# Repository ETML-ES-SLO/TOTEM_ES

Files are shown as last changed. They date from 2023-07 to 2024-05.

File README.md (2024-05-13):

# TOTEM FIXME 

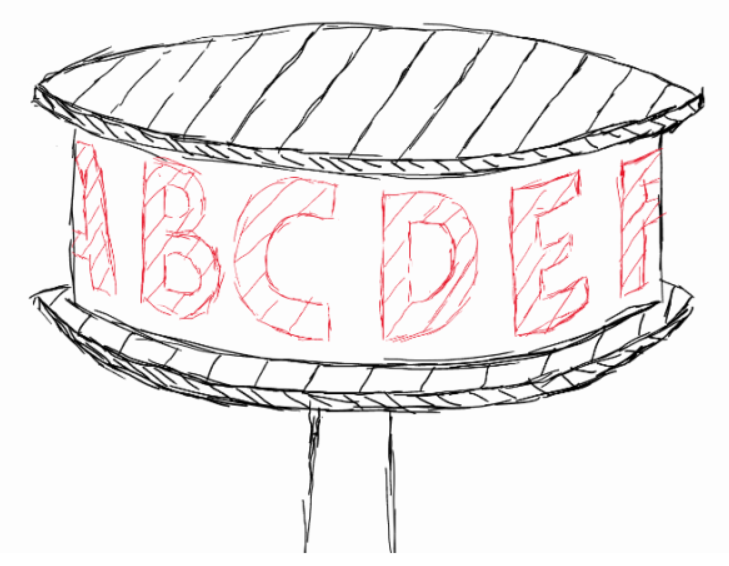
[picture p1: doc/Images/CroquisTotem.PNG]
croquis du totem


## General Description 

[FR] : le but de ce projet est de réaliser un totem lumineux pouvant afficher des messages défilants ou des animations. 
Ce totem sera utilisé lors de festivales ou de manifestions lié aux activités du hackersapce Fixme, que ce soit à l'intérieur ou à l'éxtérieur.
Un premier prototype a été réaliser par un ex-étudiant de l'ES (Nicolas Furst), ce protoype est composé de :  

[EN] : the goal of this project is to make a light totem which can display different scrolling messages or animations. 
This totem will be used at festivals or demonstration meeting related FIXME hackerspace activities, indorrs or outdorrs. 
A first prototype was realized by an former student of the ES technical school (Nicolas Furst), this prototype is composed of : 

## Sotfwares used for this projet 
### for the version 1_X (ETML-ES)

* for mechanical part : **soldiworks** 
* for shematics and PCB design : **Altium** 
* for PIC micronctroller programming  : => *IDE* : MPLABX  ??- *configurator* : Harmony ?? - *compilator* : XC?? 

### for the version 2_x (FIXME)

in progress !!!

## **Mechanical part** : 

* two disk of 240mm diameter - view of top and bottom below

| view **TOP** | view **BOTTOM** | 
| --- | --- |
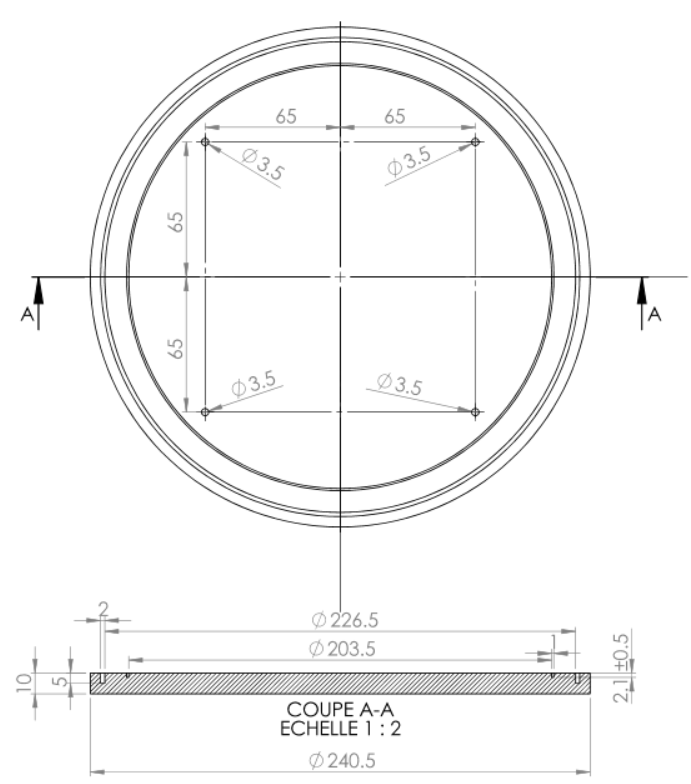
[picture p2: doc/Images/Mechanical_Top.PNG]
TOP
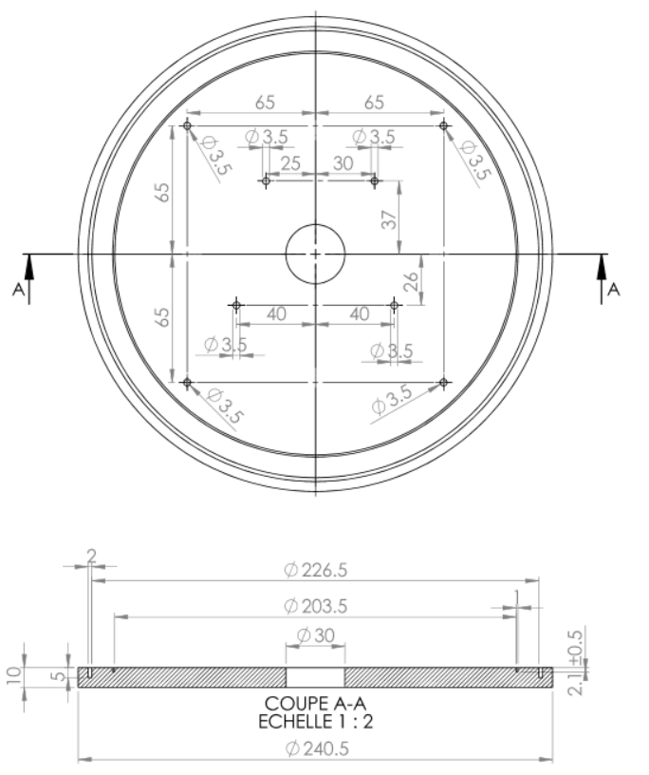
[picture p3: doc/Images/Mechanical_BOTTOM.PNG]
BOTTOM
|  |  | 

**note** : the mechanical schematic was realized on the Solid Works CAO software - for using the mechanical files, go into the **mec** folder 

## **Electronics part** 

Below is a block diagrams of the various stages of the electronic part : 
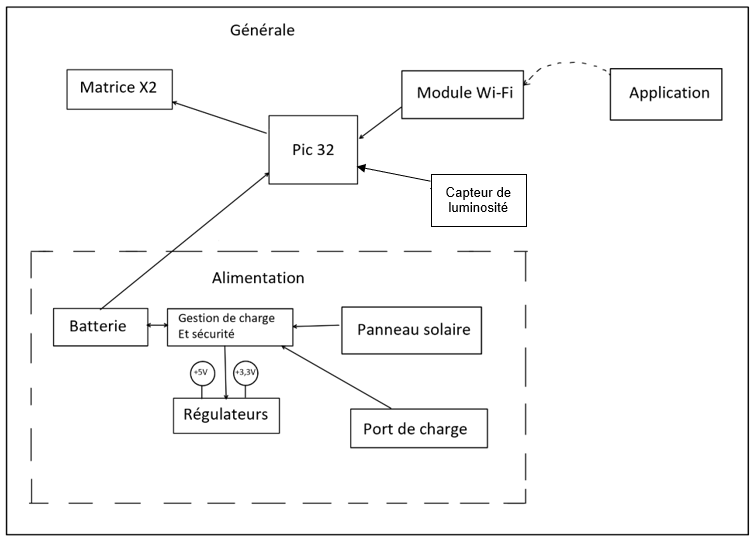
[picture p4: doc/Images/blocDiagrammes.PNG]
block diagrams


### **POWER SUPPLY**
in progress 

#### **Battery & Solar Panel**

#### **Charging System**
#### **Regulator**

### **DISPLAY**
2 flexible LEDS panels (8 x 32 => 256 type leds [WS2812B](https://cdn-shop.adafruit.com/datasheets/WS2812B.pdf) or [SK6812](https://cdn-shop.adafruit.com/product-files/1138/SK6812+LED+datasheet+.pdf))  

### **MICROCONTROLER** 

[FR]: pour choisir correctement un micrcontroleur, il faut déterminer les différentes fonctions que l'on a besoin, voir le tableau ci-dessous. 
On a besoin de : 
* 3 entrées analogiques, 
* une communication SPI comprenant la clock, le chip select, le MISO et le MOSI, 
* 5 I/O, 
* un reset
* deux pins de programmation 
* alimentation pour la partie digitales et analogiques 

ce qui fait au minium ~ **20pins** => voir le tableau ci-dessous 

En se référant au [datasheet PIC32MX795H](https://ww1.microchip.com/downloads/aemDocuments/documents/MCU32/ProductDocuments/DataSheets/PIC32MX5XX6XX7XX_Family%29Datasheet_DS60001156K.pdf),
vu le nombre de pattes estimées, il serait bien de choisir un boitier de type **TQFP** de 64pins. 
On reste sur du prototype, donc il serait bien d'utiliser le chip ayant le plus de mémoire (ROM -> 512ko | RAM -> 128ko)      

[EN]: to choose the microcontroller, to need to determine the functions required - see the table below
It needs : 
* 3x analog input 
* 1x SPI communication with : clock, chip select, MISO, MOSI 
* 5x digital I/O 
* Reset 
* 2x programming Pins
* pins for the digital and analog part 

we need minimum ~ **20pins** => see table below  

In reference with [datasheet PIC32MX795H](https://ww1.microchip.com/downloads/aemDocuments/documents/MCU32/ProductDocuments/DataSheets/PIC32MX5XX6XX7XX_Family%29Datasheet_DS60001156K.pdf), 
and with the above estimate, it would be a good idea to use **TQFP** box, with 64pins. What's more, this is a prototype, so it would be a good idea to also take the uC with the largest memory (ROM -> 512ko | RAM -> 128ko)  

| -Application- | -Function- | -Pin's Number- | 
| --- | --- | --- |
| battery current measurement | Analogic Input (ADC) | 1x | 
| battery voltage measurement | Analogic Input (ADC) | 1x | 
| luminosity measurement | Analogic Input (ADC) | 1x |
| Wifi Communication | SPI | 4x | 
| Wifi Communication | Digital I/O | 4x |
| 5V activation | Digital I/O | 1x |
| uC programming | PGE-D/C | 2x |
| uC Reset | _MCLR | 1x | 
| Power Supply digital I/O | VDD | minimum 1x | 
| Power Supply analog Input | AVDD | minimum 1x | 
| Ground Supply | VSS - AVSS | minimum 2x | 

Below, features extracted from the datasheet 
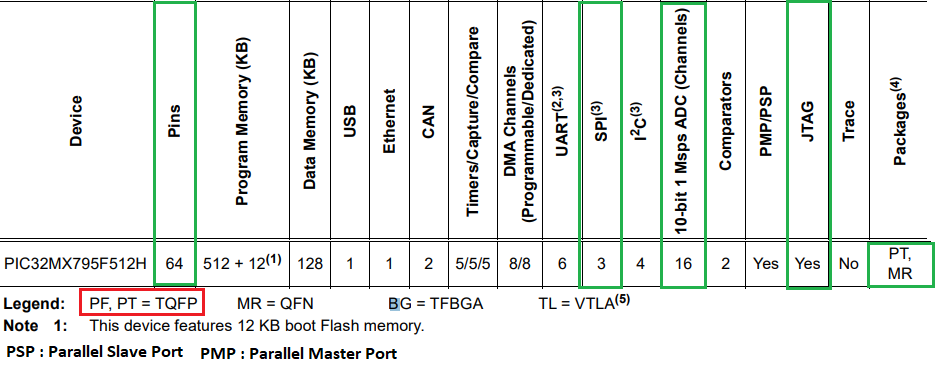
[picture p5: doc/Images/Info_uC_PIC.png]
PIC32M795 features


### **SENSORS** 

#### **Brightness measurement** 

#### **Current measurement**

Below a no exhaustive list of main electronics parts - here the main components used in this project, for more details, see the [BOM](/hardware/BOM/ListeComposants_V1.xlsx) 

| description | manufacturer | model | datasheet | remarks | name supplier | supplier reference |
| --- | --- | --- | --- | --- | --- | --- |
| microcontroller PIC family | Microchip | PICMX795H | [datasheet PIC32MX795H](https://ww1.microchip.com/downloads/aemDocuments/documents/MCU32/ProductDocuments/DataSheets/PIC32MX5XX6XX7XX_Family%29Datasheet_DS60001156K.pdf) | TQFP housing | Farnell | [1778989](https://ch.farnell.com/fr-CH/microchip/pic32mx795f512h-80i-pt/micro-32-bits-512k-flash-usb-64tqfp/dp/1778989) | 
| IOT module IEEE 802.11 | Microchip | ATWILC1000-MR110xB | [datasheet ATWILC100](https://ww1.microchip.com/downloads/aemDocuments/documents/WSG/ProductDocuments/DataSheets/ATWILC1000-MR110XB-IEEE-802.11-b-g-n-Link-Controller-Module-DS70005326E.pd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) | no comments |
| DC/DC Converter (Input : 4,5 to 14V Ouput : 0 - 6V / 10A | lineage Power | NQR010A0X4 | [datasheet NQR010A0X4](/doc/datasheets/Alimentation/NQR010A0X-477178.pdf) | probably osbolete component | 
| current sensing Amplifier | TI | LMP860x | [datasheet LMP860x](https://www.ti.com/lit/ds/symlink/lmp8601.pdf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)  | no comments | 
| light sensor - phototransitor | Vishay | TEPT4400 | [datasheet TEPT4400](https://www.vishay.com/docs/81341/tept4400.pdf) | no comment | 
| Step-Down Regulator 3A | TI | LM2676 | [datasheet LM2676](https://www.ti.com/lit/ds/symlink/lm2676.pdf?ts=1697798250050&ref_url=https%253A%252F%252Fwww.google.com%252F) | no comment | 
| Current Sensor Amplifier | TI | LM860x | [datasheet LM8601](| Step-Down Regulator 3A | TI | LM2676 | [datasheet LM2676](https://www.ti.com/lit/ds/symlink/lm2676.pdf?ts=1697798250050&ref_url=https%253A%252F%252Fwww.google.com%252F) | no comment | ) | no comment | 
| Intelligent Control LED | Worldsemi | WS2812B | [datasheet WS2812B](https://cdn-shop.adafruit.com/datasheets/WS2812B.pdf) | link with led pannels | 
| --- | --- | --- | --- | --- | 

## **SOFTWARE (Firmeware - Software)**
### **Description**

[FR]: Pour la partie connexion avec la carte électronique, cela se fera par le réseau WiFi en connexion point à point avec une application (non défini) qui communiquera pour piloter le ToTem. 
Les fonctions possibles seront : 

* afficher chaînes de caractères alphanumérique - voir caractères spéciaux 
* modification de la luminoisté 
* modification de la couleur du texte 
* modifier la fréquence d'affichage 
* affichage du niveau de batterie 
* animation - jeux 

[EN]: to connect to the electronic board, this will be done using the point-to-point WiFi nwtwork with an application (no defined), which will communicate to control the Totem. 
The possible functions will be : 

* display alpha-numeric strings - see the special characters 
* luminosity modification 
* text's color modification 
* display's frequency modification
* display the battery level 
* animation - gaming 

### **Firmeware part** 

### **software application** 

In progress

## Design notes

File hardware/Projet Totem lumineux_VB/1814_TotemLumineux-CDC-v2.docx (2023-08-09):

# Projet ETML-ES - Cahier des charges

Totem lumineux

1814

Entreprise/Client: | Fixme | Département:
Demandé par (Prénom, Nom): | Philippe Bovey | Date: | 02.05.2022

Auteur (ETML-ES): | Miguel Santos | Filière: | SLO
| | Date: | 02.05.2022

# 1 But du projet

La principale tâche de correction de ce projet sera d’améliorer le PCB de celui-ci. Une empreinte Mikroe sera utilisé pour remplacer et faciliter de futurs changements de module Wi-fi. Le PCB devra aussi être réduit en taille si possible. Les problèmes de footprint relevé dans le rapport final devront être corrigés.

Le boitier devra être modifié afin de pouvoir y intégrer un connecteur pour l’alimentation et un capteur de luminosité externe. Une structure imprimée en 3D peut être envisagée pour cela. Néanmoins, nous souhaitons conserver le plus possible ce qui est déjà présent.

# 2 Spécifications du projet

- Empreinte MikroBus
- Stitching réduit (~10mm)
- Trous de fixation NON-métallisés

# 3 Tâches à réaliser

- Améliorer les différentes connectiques du PCB.
- Ajouter une empreinte Mikroe au PCB qui remplacera le module Wi-fi.
- Corriger les footprints erronés.
- Fraiser les trous supérieurs pour noyer les trous.

# 4 Jalons principaux

- Revue de schéma 23.05.2022
- Corrections des footprints 30.05.2022
- Revue de PCB 13.06.2022

# 5 Livrables

Enlever les livrables inapplicables au projet parmi la liste ci-dessous.

- Les fichiers sources de CAO électronique des PCB réalisés
- Tout le nécessaire à fabriquer un exemplaire hardware de chaque :
- Fichiers de fabrication (GERBER) / liste de pièces avec références pour commande / implantation (prototype) / modifications / dessins mécaniques, etc

# 6 Convention de nommage et liens

Le nom de ce fichier doit être unique et doit donc contenir le nom du projet avec le format suivant :

aaii_nomProjet-CDC_Vn.docx

avec :

- CDC : pour Cahier des charges
- aaii : numéro de projet, exemple 1708 pour projet de 2017 no 08
- nomProjet : comme son nom l'indique.
- Vn: ou n indique la version du document.

Exemple :

- 0910x_PICEthernet-CDC_V1.docx

## 6.1 Stockage du fichier

Ce fichier sera stocké à la racine du dossier /doc d’un projet.

Ainsi, tous les fichiers de documentation faisant partie du projet sont centralisés dans le même répertoire.

JMO – Nov 2018Projet-CDC-v1.docxPage 2

ECOLE SUPERIEURE ELCO – SLO

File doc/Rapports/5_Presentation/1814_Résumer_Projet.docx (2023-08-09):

RESUMÉ - Projet Nicolas Fürst

SLO

2ème années

Titre:

Totem Lumineux

Contexte et objectifs:

- Totem lumineux à LED pour extérieur.
- Animation colorée.
- Possibilité d'afficher un mot ou un texte défilant.
- Lisible depuis toutes directions.
- Tête à monter sur un mat pour l'élever.
- Alimentation sur batterie, rechargeable par secteur et panneau solaire.
- Longue autonomie, environ 24H.
- Commande via Wifi, 4G ou Bluetooth.
- LED RGB - gestion de la batterie.
- Utilisable en extérieur.
- Gérer par un Pic32MX.
- Affichage circulaire avec une matrice souple.

Résultats obtenus et conclusion :

Au finale le projet répond aux principaux critères du cahier des charges.

Le Totem est capable d'afficher un message coloré ou une animation à une vitesse et luminosité variable sur deux matrices souple pour un total de 512 LEDs RGB, il est capable de lire le niveau de son alimentation et il possède un boitier qui peut être imperméabilisé. Bien qu'il ait un module wifi la communication ne fonctionne pas ce qui est le gros point en moins par rapport au cahier des charges. La partie batterie manque mais le Totem peut sans problème la recevoir.

Maître(s) de projet: Monsieur Philippe Bovey

Entreprise mandataire: FIXME Hackerspace

Ecole supérieure, école des métiers Lausanne Rue de Sébeillon 12 CH-1004 Lausanne www.etml-es.ch | 1 / 1 |

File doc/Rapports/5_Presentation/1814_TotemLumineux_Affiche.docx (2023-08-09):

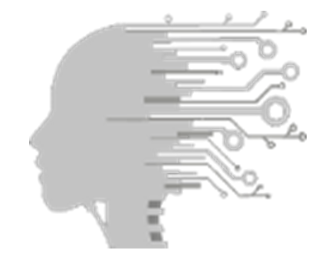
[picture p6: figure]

FIXME Hackerspace

Ce Projet est un Totem qui a pour but d'afficher des messages à 360°, s'est pourquoi il est équipé de deux matrices souples de chez Adfruit donnant un total de 512 LEDs RGB reparti sur tout le tour avec une résolution de 64 colonnes de 8 LEDs.

Les messages que le Totem est capable d'afficher peuvent varier en nombre de caractère, évidemamment, mais également en luminosité et en vitesse de défilement. Mais l'utilité du Totem ne s'arrête pas là, avec autant de LEDs il est aussi capable de faire des animations bien que pour l'instant une seul a été programmer.

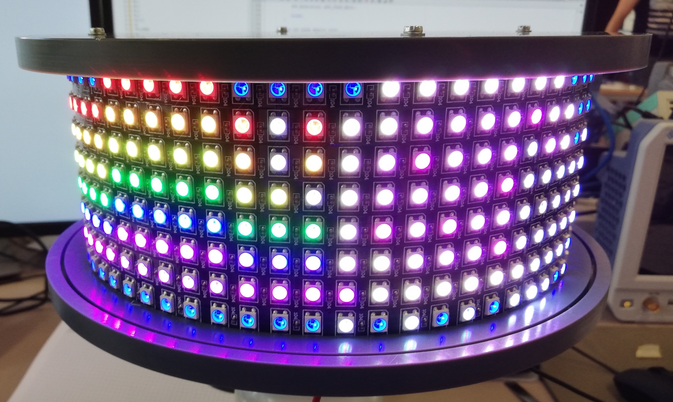
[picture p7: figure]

Pour la suite du projet il faut faire la communication Wifi du Totem ainsi que l'application nécessaire à le faire fonctionner. Avec Ceci Le Totem bénéficiera de plus d'animations.

En conclusion j'ai vraiment apprécié travailler sur ce projet et j'ai beaucoup appris en le réalisant.

www.etml-es.ch rue de Sébeillon 12, 1004 Lausanne ETML

Nicolas Fürst Technicien-ne ES en génie électrique / 2017-2018 Totem Lumineux

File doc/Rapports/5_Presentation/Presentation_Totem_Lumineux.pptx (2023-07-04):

## Totem lumineux

Nicolas Fürst

## Sommaire:

1. Cahier des charges
2. Schéma
3. PCB
4. Affichage
5. Logiciel
6. Mécanique
7. Modes
8. Consommation
9. Conclusion
10. Questions?

Sommaire

## Cahier des charges

• Totem lumineux à LED pour extérieur.
• Animation colorée.
• Possibilité d'afficher un mot ou un texte défilant.
• Lisible depuis toutes directions.
• Tête à monter sur un mat pour l'élever.
• Alimentation sur batterie, rechargeable par secteur et panneau solaire.
• Longue autonomie, environ 24H.
• Commande via Wifi, 4G ou Bluetooth.
• LED RGB - gestion de la batterie.
• Utilisable en extérieur.
• Gérer par un Pic32MX.

Cahier des charges


## Partie alimentation

Schéma

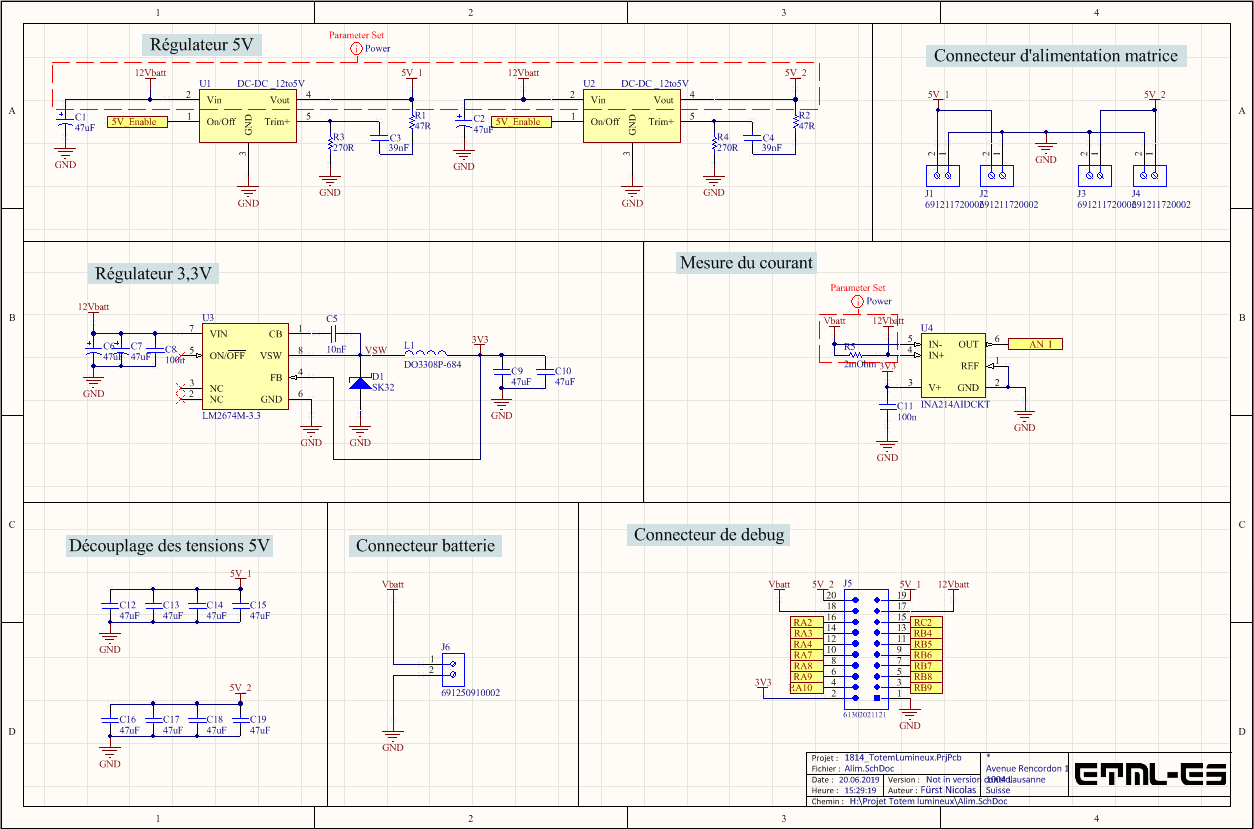
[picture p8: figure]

## Partie Logique

Schéma

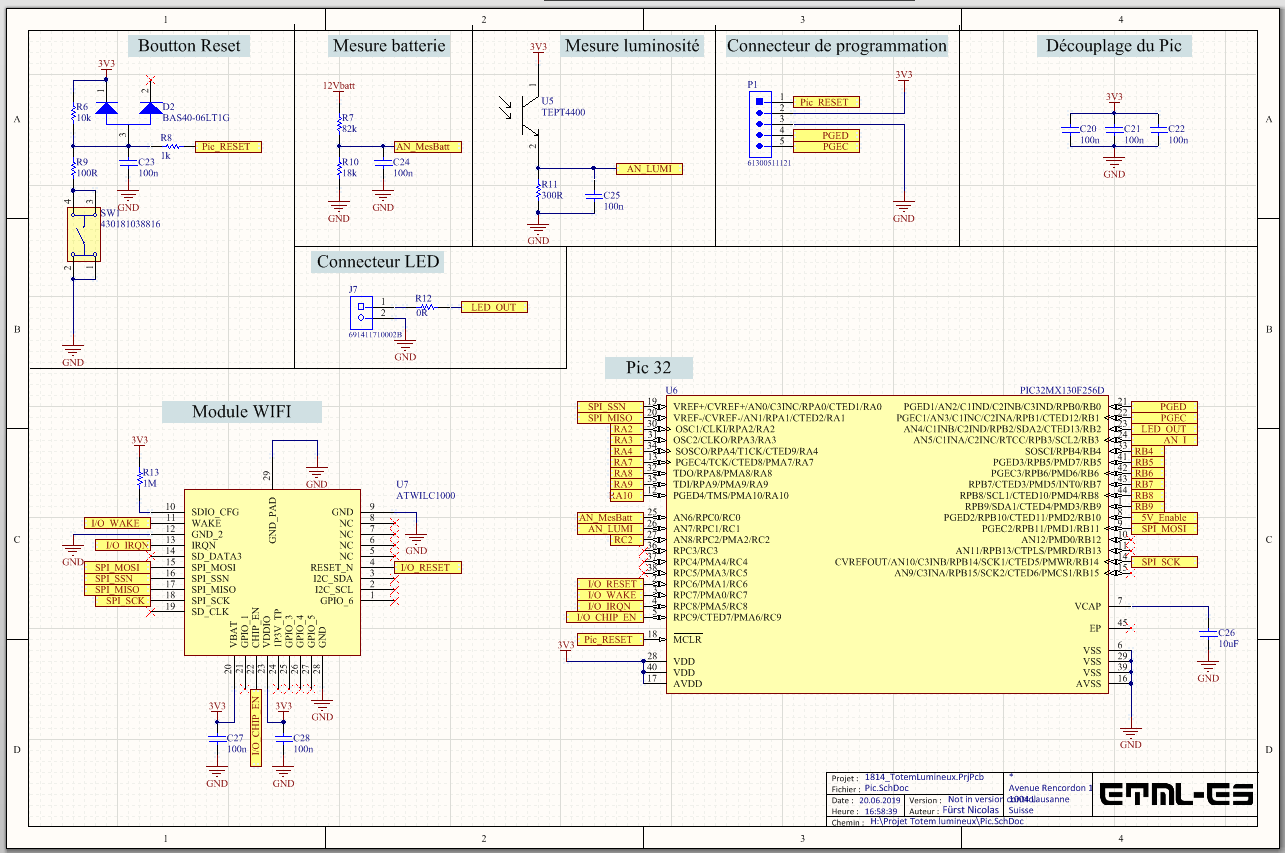
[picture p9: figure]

## Dimensionnement

PCB

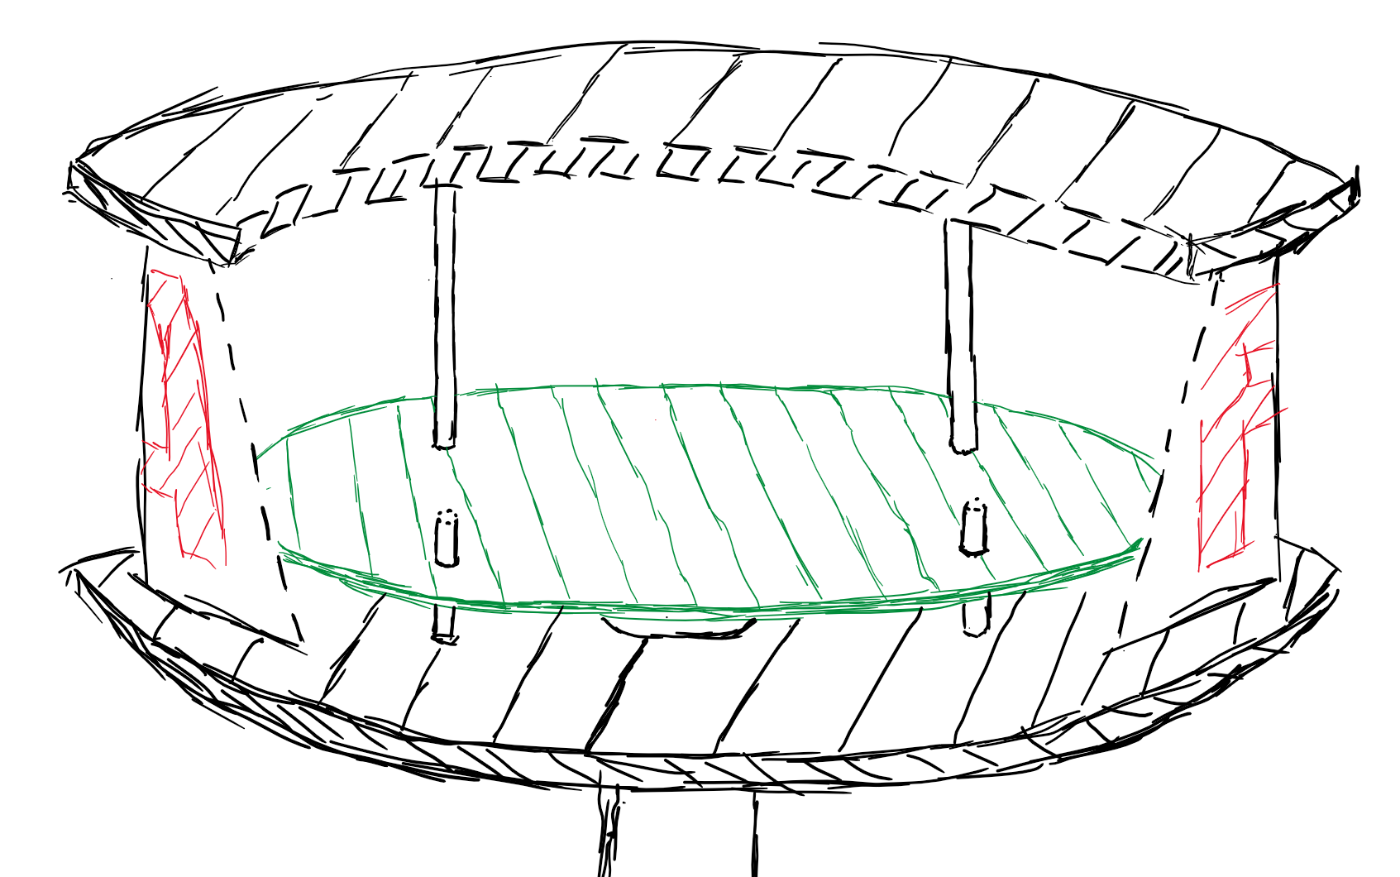
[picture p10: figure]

- 204mm de diamètre ou de diagonale.
- Rectangulaire de 110mm x 87mm

## Placement

PCB

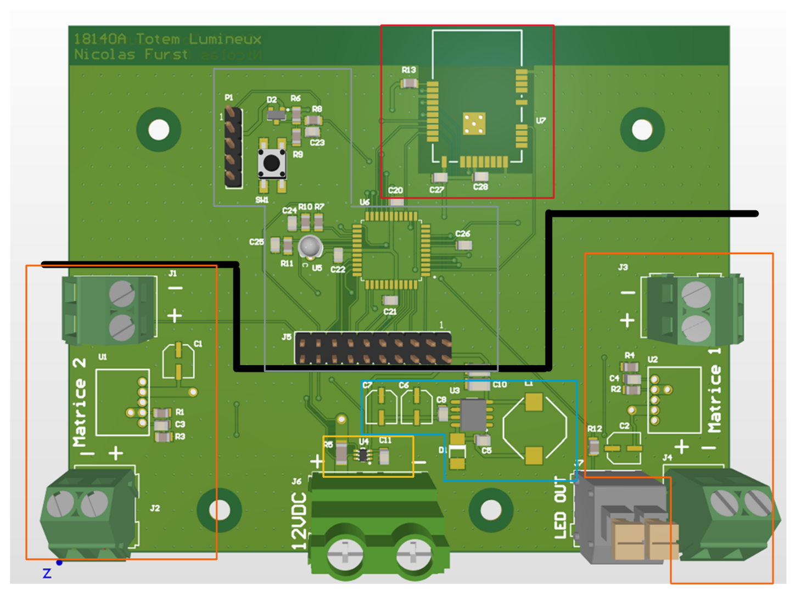
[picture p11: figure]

## Routage

PCB

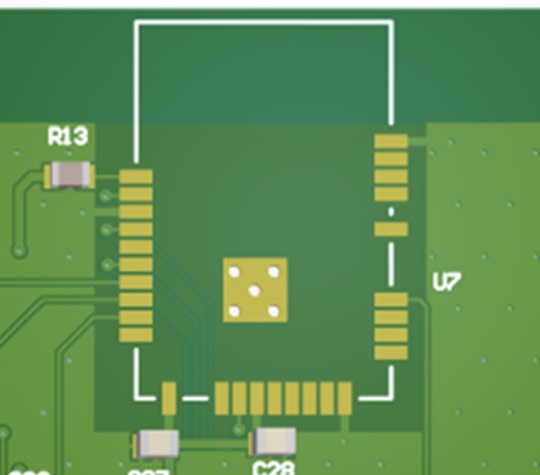
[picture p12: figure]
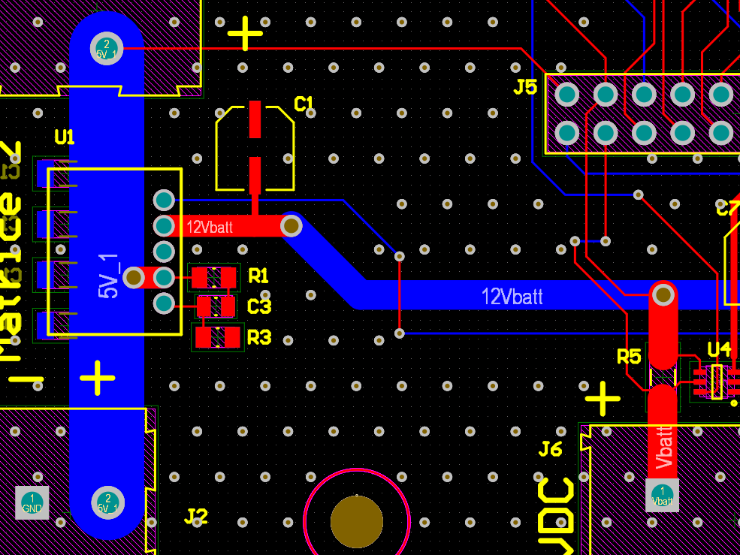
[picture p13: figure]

## Problèmes

PCB

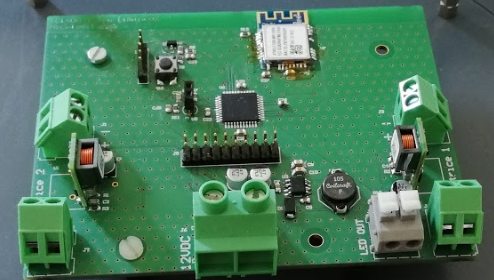
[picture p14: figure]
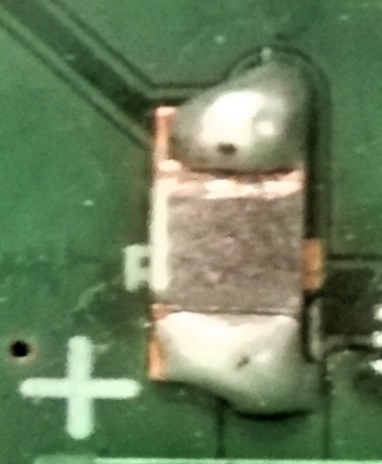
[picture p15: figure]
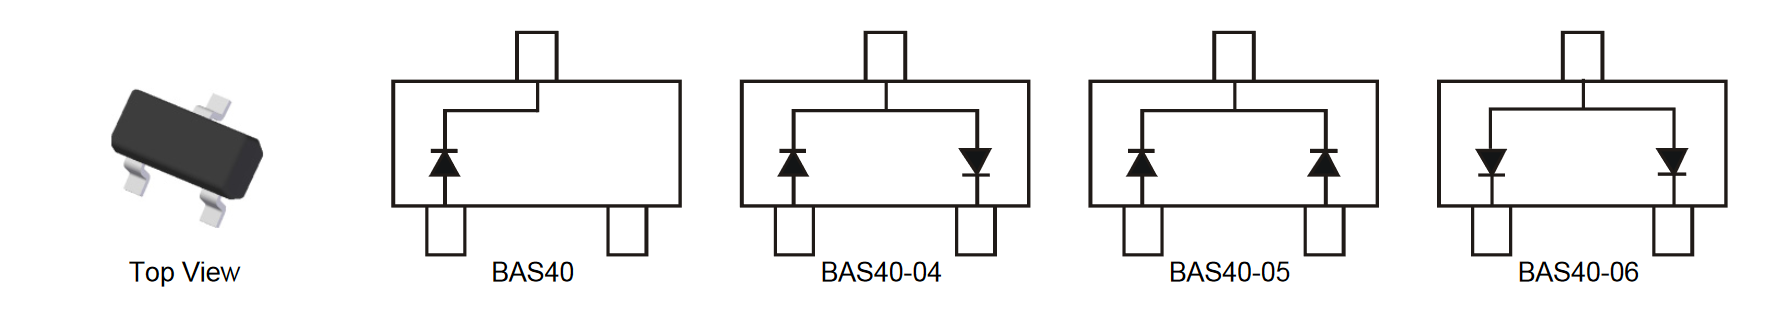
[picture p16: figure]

## Matrices

Deux matrices de 256 LEDs RGB.
512 LEDs au total, 64 colonnes de 8 LEDs.

Affichage

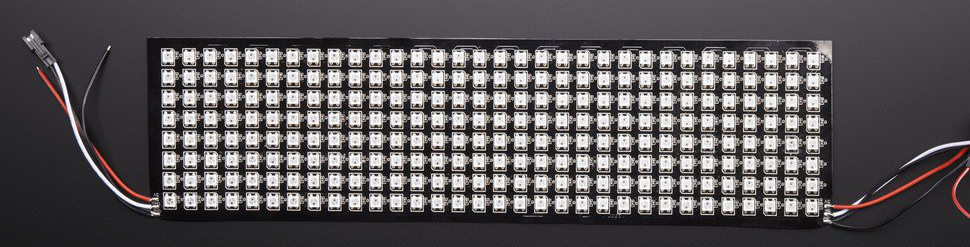
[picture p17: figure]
Flexible 8x32 NeoPixel RGB LED Matrix

## LEDs et communication

Communication série sans communication de clock.
8 bits par couleur.

Affichage

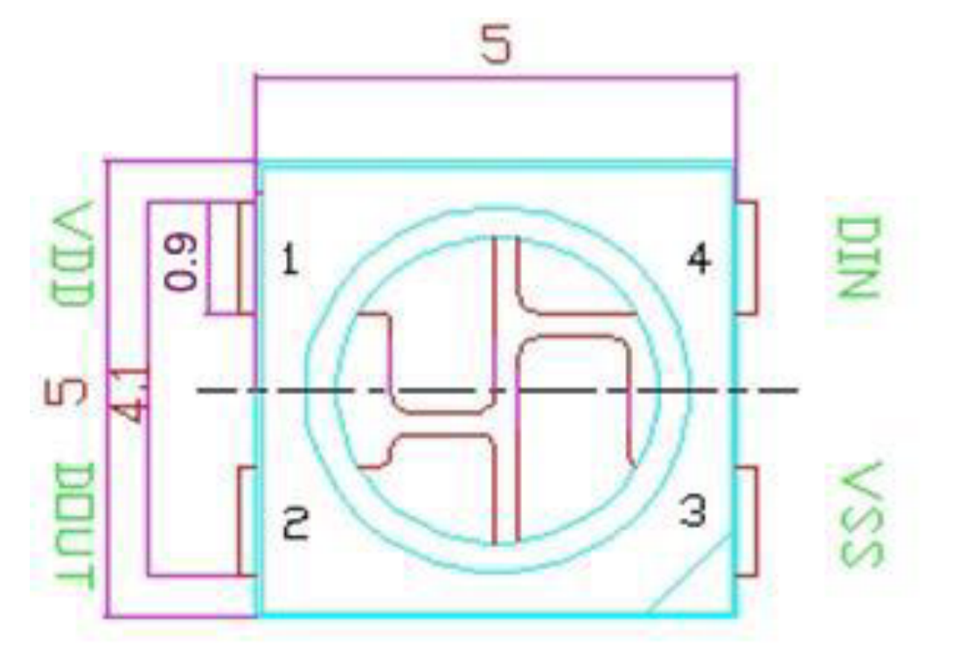
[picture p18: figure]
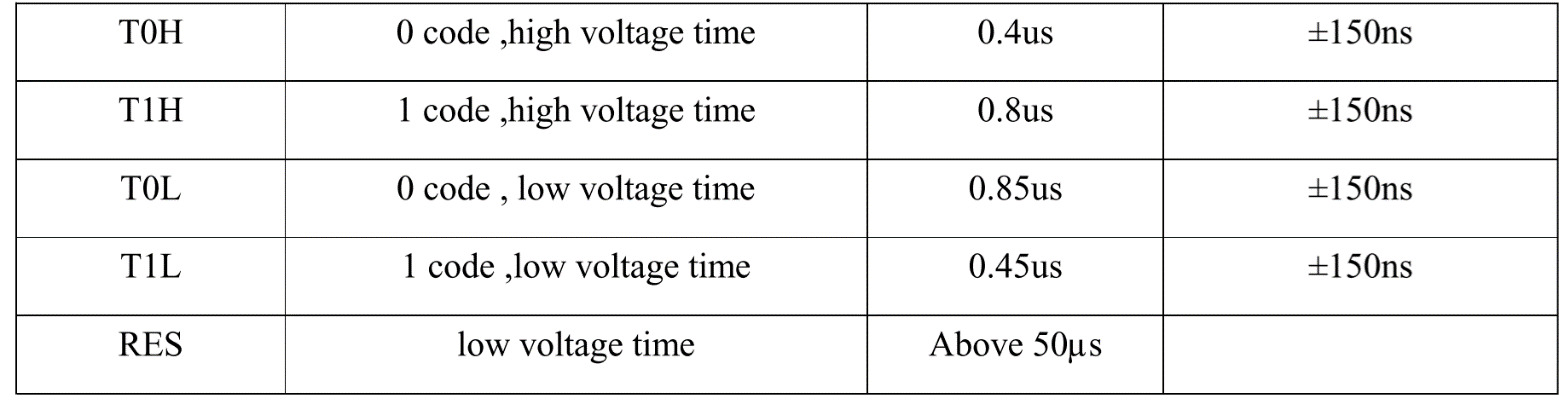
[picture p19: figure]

## Fonctions LEDs

Logiciel

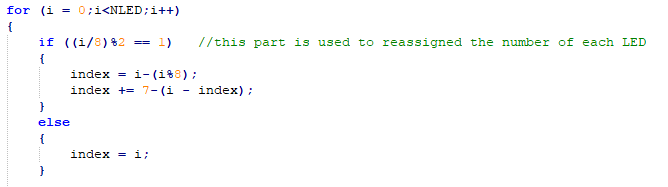
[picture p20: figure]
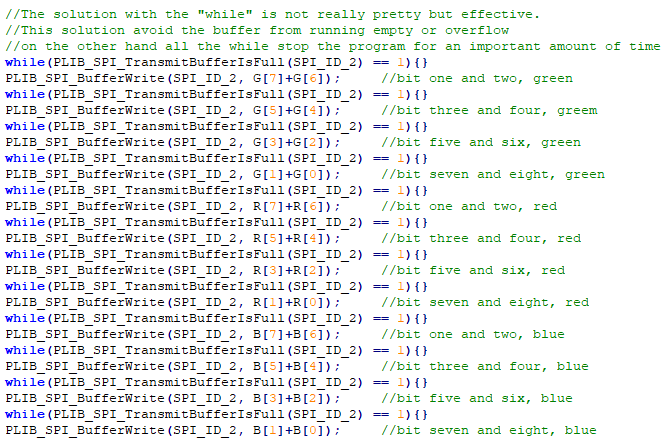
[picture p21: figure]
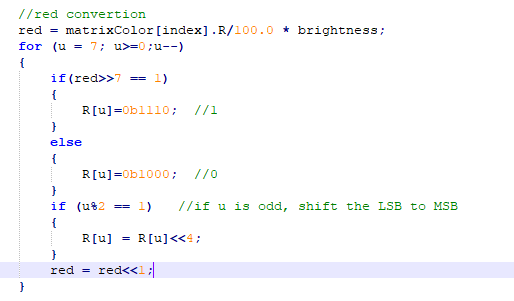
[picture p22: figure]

## Fonctions texte

Logiciel

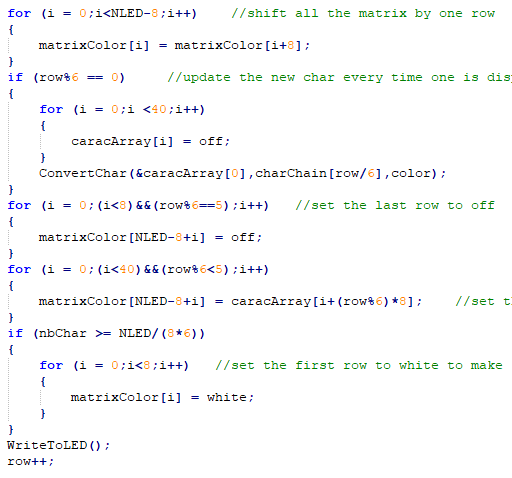
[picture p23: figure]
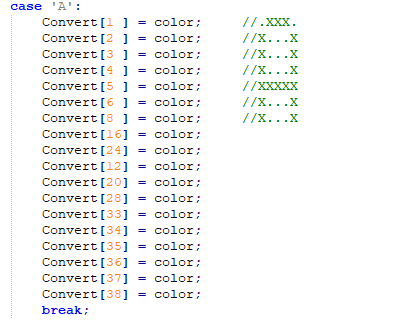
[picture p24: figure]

## Boitier

q

Mécanique

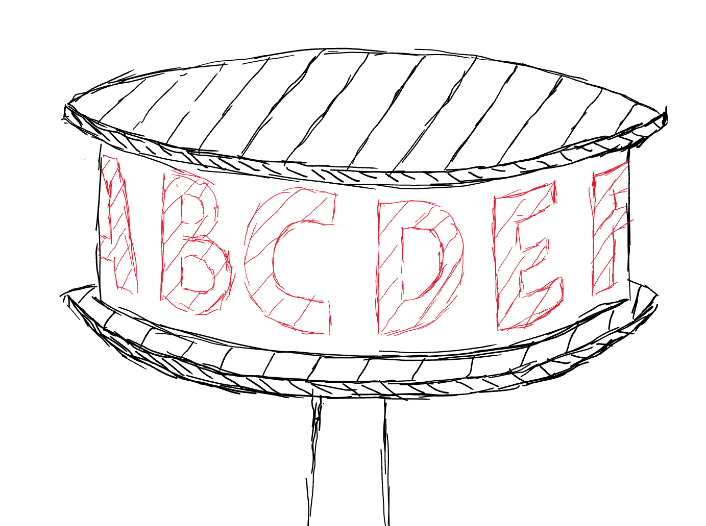
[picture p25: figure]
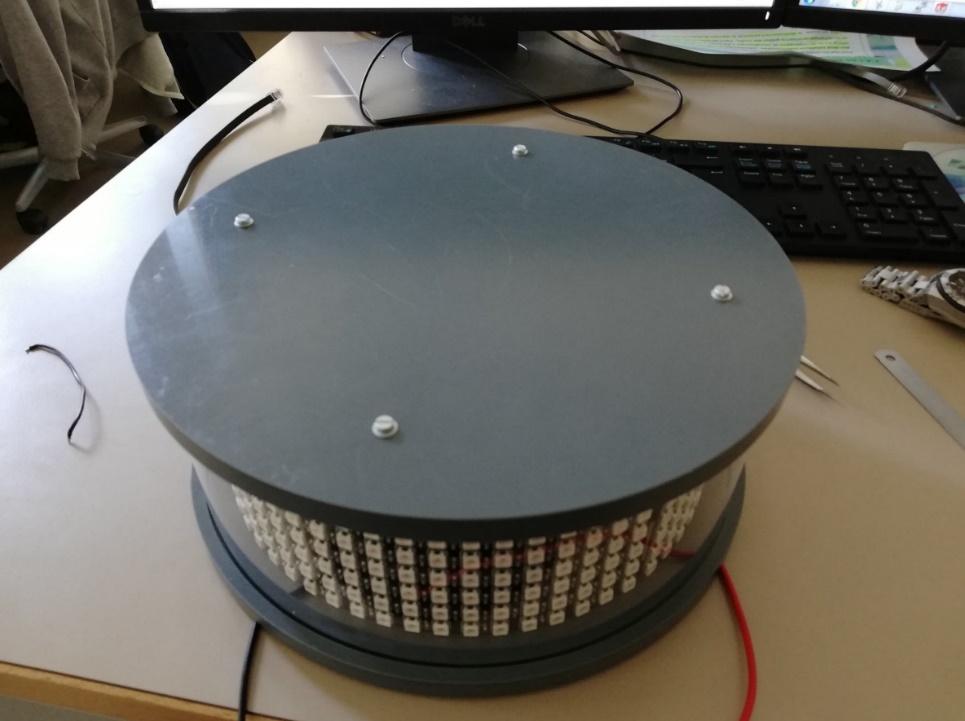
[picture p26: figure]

## Fonctionnalité:

Textes défilant.
Animations.
Réglage automatique de la luminosité.
Mesures de la tension d'entrée.

.',-_/*+=:()%°$!?0123456789ABCDEFGHIJKLMNOPQRSTUVWXYZ

Fonctionnalité

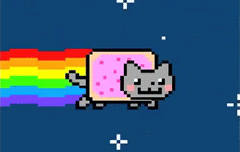
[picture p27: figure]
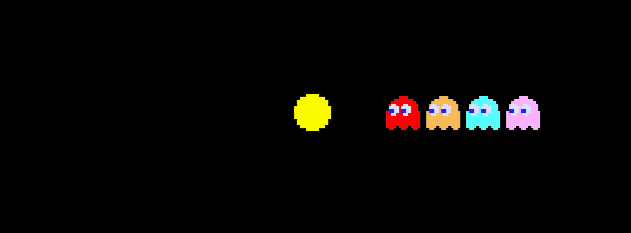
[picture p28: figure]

## Consommation

Consommation

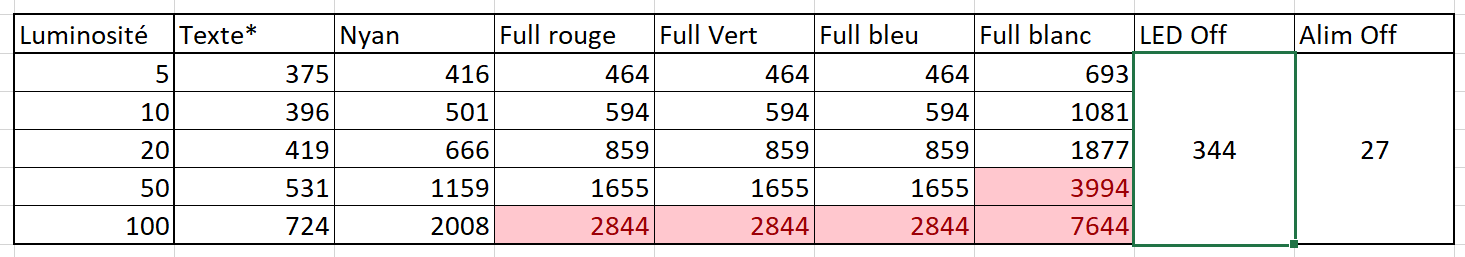
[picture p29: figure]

Mesure faite à 5V sur une seul matrice


## Conclusion

## Question?

Nicolas Fürst

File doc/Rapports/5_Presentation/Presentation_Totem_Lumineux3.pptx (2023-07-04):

## Totem lumineux

Nicolas Fürst

## Sommaire:

1. Cahier des charges
2. Schéma
3. PCB
4. Affichage
5. Logiciel
6. Mécanique
7. Modes
8. Consommation
9. Conclusion
10. Questions?

Sommaire

## Cahier des charges

• Totem lumineux à LED pour extérieur.
• Animation colorée.
• Possibilité d'afficher un mot ou un texte défilant.
• Lisible depuis toutes directions.
• Tête à monter sur un mat pour l'élever.
• Alimentation sur batterie, rechargeable par secteur et panneau solaire.
• Longue autonomie, environ 24H.
• Commande via Wifi, 4G ou Bluetooth.
• LED RGB - gestion de la batterie.
• Utilisable en extérieur.
• Gérer par un Pic32MX.

Cahier des charges


## Partie alimentation

Schéma


## Partie Logique

Schéma


## Placement

PCB


## Routage

PCB


## Problèmes

PCB


## Matrices

Deux matrices de 256 LEDs RGB.
512 LEDs au total, 64 colonnes de 8 LEDs.

Affichage

Flexible 8x32 NeoPixel RGB LED Matrix

## LEDs et communication

Communication série sans communication de clock.
8 bits par couleur.

Affichage


## Fonctions LEDs

Logiciel


## Fonctions texte

Logiciel


## Boitier

q

Mécanique


## Fonctionnalité:

Textes défilant.
Animations.
Réglage automatique de la luminosité.
Mesures de la tension d'entrée.

.',-_/*+=:()%°$!?0123456789ABCDEFGHIJKLMNOPQRSTUVWXYZ

Fonctionnalité


## Consommation

Consommation


Mesure faite à 5V sur une seul matrice


## Conclusion

## Question?

Nicolas Fürst

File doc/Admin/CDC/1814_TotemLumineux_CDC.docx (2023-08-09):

# Totem lumineux

# 1. DOnnée de base

Totem lumineux à Led pour extérieur – forme cylindrique – 30cm de haut – environ 5 à 10 Led par coté cardinaux (N/S/E/W) – alimentation autonomes. Recharge solaire et uUSB – autonomie de 24h – scénario de couleur - commande via wifi ou 4G

# 2. A voir

Sujet | Priorité
LED | 1
Commande wifi | 1
Batterie | 1
Recharge solaire | 1
Forme et boitier | 2
Scénario de couleur | 3
Points cardinaux ? | 2

# 3. Cahier des charges

- 40 LED RGB, 10 par coté.
  - LED SK6812 ou WS2812B
- Sur batterie avec une autonomie de 24H.
  - Batterie li-ion ou li-po.
  - Gestion de la charge.
  - Feedback du niveau de batterie.
- Contrôle via wifi ou 4G.
- Utilisation en extérieure.
- Panneau solaire.
- Forme circulaire de 30cm de haut

# 4. à voir en priorité

## 4.1 LED

LED RGB adressable :

Les LED adressable permettent de contrôler indépendamment la couleur de chaque LED.

Parmis les choix il y a la WS2812B et la SK6812 la seule différence est que la SK est plus récente et sa couleur résiste mieux au voltage drop. Sinon les deux Led se commande avec exactement le même protocolle de communication.

Vus que les LED son independante il est possible d’en mettre plus et de les éteindre pour consommer moins.

Matrice flexible :

Pour afficher un texte a 360 degré j’ai pensé utiliser deux matrice de LED 8x32 flexible de sorte a faire comme un disque d’environ 20cm de diamètre et 8cm de hauteur.

Cette solution implique 512 LED ce qui est considérablement plus que les autres solution mais il seras très facile de faire défiler un texte qui seras facilement lisible.

La profusion de LED implique evidemment une consomation supérieur mais un caractère a environ 15 LED allumer et on peut en afficher maximum de 10 caractère ce qui fait 150 LED allumer au maximum sa reste 4 fois supérieur au 40 LED de base. (a voir test de consommation)

## 4.2 Commande Wifi

Esp(8266)

## 4.3 Batterie

La batterie doit pouvoir tenir 24H. La consommation principale de l’ensemble sera les LED, à tel point que le reste en devient presque négligeable.

La consommation maximale serait donc de 60mA par LED et 40 LED ce qui fait un total de 12Wh, ce qui est beaucoup trop. Mais cette consommation survient uniquement si les 3 couleurs des 40 LED son alummer en pérmanence à la luminosité maximum. Je pense donc que la consommation peut être réduite au moins d’un facteur 10 juste en réduisant la luminositer et en faisant des animation pendant lesquels seulement une LED sur deux ou trois est alummer etc.. SI il est nécessaire de réduire encore il est possible de juste jamais allumer certaine LED.

Pour les calcules je pense prendre une consommation moyenne de 1,2Wh ce qui reste encore assez élever.

Avec 1,2Wh la batterie doit faire 28,8W pour tenir 24h avec une seul charge et cela sans compter le panneau solaire. Ce qui fait que, par exemple, seulement 3 batteries INR18650-30Q sufirait pour alimenter le totem pendant 24H

## 4.4 Recharge solaire

## 4.5 Boitier

https://www.amazon.fr/EsportsMJJ-Acrylique-Longueur-Transparent-Plexiglass/dp/B074SKWL35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

e stage Page 7 sur 7 26-nov.-18

This document is the property of EM MICROELECTRONIC-MARIN SA and is furnished in confidence and upon the condition that all rights originating in the information, whether patented or not, will be respected. EM Document Center/10.12.02 Page 1 of 2

EM MICROELECTRONIC - MARIN SA PRODUCT MARKING

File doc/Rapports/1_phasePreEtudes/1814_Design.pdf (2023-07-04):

ETML

Phase de design | Page 1 sur 13 | 6-févr.-19

# Phase de design

# École supérieure

## Électronique

## PROJ Salle R110

# TOTEM LUMINEUX

## Réalisé par :

## Nicolas Fürst

## Date :

## 06 Février 2019

Phase de design | Page 2 sur 13 | 6-févr.-19

## Table des matières


Phase de design | Page 3 sur 13 | 6-févr.-19

### 1. DESCRIPTION

### 1.1 APPARENCE

En apparence, la tête du totem fera un peu plus de 20 cm de diamètre pour 10 de haut, les deux matrices de 256 LED feront tout le tour afin de pouvoir afficher du texte lisible depuis toutes les directions. Le PCB avec le pic et tout le reste se situera dans la tête.

La base sera moins complexe, elle devra déjà maintenir le mât et la tête droits et stables et contenir la batterie, le panneau solaire, les deux régulateurs de charge avec le port de charge et finalement l’interrupteur on/off. La base pourra donc simplement être une boîte contenant le tout et maintenant le panneau solaire à l’extérieur.

### 1.2 FONCTIONNALITÉ

En plus de pouvoir afficher un texte par Wifi, il sera possible de changer la couleur du texte, choisir d’afficher différentes animations, modifier la luminosité soit automatiquement ou alors à l’aide d’un capteur et finalement le Totem mesurera la tension de la batterie régulièrement pour pouvoir signaler le niveau de batterie et adapter automatiquement la luminosité ou la fréquence d’affichage pour allonger l’autonomie du Totem et le maintenir allumé plus longtemps.

### 2. CHOIX EFFECTUÉ

### 2.1 PRÉ-ÉTUDE

Ce que j’avais déjà choisi lors de la pré-étude est resté. Que ce soit pour les matrices de LED, le kit batterie plus panneau solaire, le capteur de luminosité ou le design du Totem il n’y a pas eu de modification.

Cependant certains points n’étaient pas complétement résolus, notamment pour les régulateurs de tension 12V à 5V et pour le module Wifi. Depuis ses deux points ont été éclaircis .

Le module Wifi sera un ATWILC1000 de chez Microchip car il fallait un module ayant la possibilité de s’y connecter depuis une page Web. Le MRF24WN0MA a été mon premier choix car il a déjà été utilisé pour un précèdent projet, mais Microchip le considère obsolète et conseille d’utiliser son équivalent, le ATWILC1000.

Pour le régulateur, j’ai choisi de prendre deux NQR010A0X4. Je les ai choisis principalement pour une question de simplicité par rapport à celui créé sur mesure sur Texas Instrument et en fonction du coup.

### 2.2 SUPPLÉMENT

En plus de ce que j’ai prévu dans la pré-études, j’ai ajouté un LMP8601 qui permet de mesurer un courant. Cet ajout, en complément de la mesure de tension, permettra de mesurer le niveau de la batterie avec précision malgré les chutes de tension.

Le deuxième gros ajout est un deuxième régulateur de charge qui s’avère nécessaire pour avoir une charge par panneau solaire et par secteur.


Phase de design | Page 4 sur 13 | 6-févr.-19

### 3. DIMENSSIONNEMENT

### 3.1 MESURE DE LA LUMINOSITÉ

Voici le schéma du capteur de luminosité :

Son fonctionnement est plutôt simple. Le phototransistor utilisé comme capteur fournit un courant en fonction de la luminosité qu’il perçoit, il suffit donc de faire passer ce courant dans une résistance pour pouvoir mesurer une tension sur un port analogique du pic. Pour dimensionner la résistance il faut déterminer la luminosité maximum que l’on veut pouvoir détecter en Lux, pour me donner une idée de ce que représente une valeur de luminosité je suis allé voir sur Wikipédia :

Grace à ce tableau je peut déterminer à peu près qu’il ne sera pas nécessaire de connaitre la luminosité ambiante si elle passe le cap des 5000 Lux. Une fois ce cap atteint l’affichage sera certainement déjà à sa luminosité maximale.


Phase de design | Page 5 sur 13 | 6-févr.-19

Ensuite, dans le datasheet du capteur on peut facilement trouver la résolution du capteur (le nombre de mA par Lux) :

Malheureusement, dans le tableau on peut voir trois différents groupes de capteurs (A,B et C) qui ont chacun un rapport différent, mais Distrelec ne précise pas à quel groupe appartient leur capteur ce qui fait que selon le type du capteur la valeur de la résistance peut être amenée à changer. Pour l’instant j’ai considéré que le capteur se situera à 45 uA/20Lux ce qui donne les résultats suivants :

R =

3,3 ∗ 20
5000 = ~300Oℎm

### 3.2 RÉGULATEUR

3.2.1 | Régulateur 5V
| Schéma pour les deux régulateurs 5V :

Avec ces régulateurs, pour avoir une sortie à 5V il faut dimensionner le condensateur et les deux résistances. Pour ce faire on trouve dans le datasheet un schéma qui montre comment les câbler :


Phase de design | Page 6 sur 13 | 6-févr.-19

Et des tableaux nous donnant les valeurs de résistance et de condensateur pour des tensions communes telles que 3,3V ou dans mon cas 5V :

Avec les tableaux on peut déterminer toutes les valeurs nécessaires : RTune (R2) = 47 Ohm, CTrim (C2) = 39nF et RTrim = 268 Ohm. Pour RTrim la valeur ne tombe pas sur une valeur facile à trouver, j’ai donc pris la valeur la plus proche dans la serie E12 ce qui donne 270 Ohm. Pour vérifier l’impact que le changement de valeur à eu sur la tension de sortie, j’ai retourné la fonction servant à trouver RTrim en cas de tension hors valeur des tableaux :

Uout =

1,182
RTrim ∗ 10⁻³ − 0,591 = 4,97V

On peut voir que la tension reste extrêmement proche des 5V.

3.2.2 | Régulateur 3,3V
| Schéma du régulateur 3,3V :

Comme pour le régulateur 5V toutes les informations sur le dimensionnement des composants se trouvent dans le datasheet. Cette fois-ci cependant la tension de sortie est


Phase de design | Page 7 sur 13 | 6-févr.-19

fixée à 3,3V dans le chip. Tous les dimensionnements se feront par rapport au courant nécessaire en sortie.

La première chose est le schéma exemple :

On peut voir que tous les composants sont déjà dimensionnés pour une application typique. J’ai repris la valeur des condensateurs tels quels mais j’ai quand même redimensionné la bobine et la diode.

Que ce soit pour la bobine ou la diode il faut commencer par déterminer le courant max de sortie nécessaire. Pour estimer le courant max j’ai simplement considérer environ 200mA pour le Pic et pour le module Wifi ce qui correspond à ce que j’ai pu trouver dans les datasheets, j’ai ensuite arrondi à 500mA pour compenser les autres éventuelles consommations.

Une fois ce courant max déterminé il suffit de trouver les valeurs correspondantes dans les tableaux :

Seulement dans le tableau pour dimensionner la bobine le courant ne descend pas en dessous de 1A. Ce qui n’est pas vraiment un problème puisque si la bobine peut tenir 1A à 14V de tension d’entrée, elle sera aussi capable de tenir 0,5A. Donc la référence de la bobine est L23.

Le datasheet fournit un tableau avec des bobines correspondent aux références du premier tableau :


Phase de design | Page 8 sur 13 | 6-févr.-19

J’ai choisi la bobine DO3316-333 car je voulais une bobine SMD et celle-ci se trouvait dans le vault de Altium.

Pour la diode on peut trouver un tableau similaire à la bobine :

Pour les diodes, toutes feraient l’affaire je me suis donc contenté de prendre la plus basique que le datasheet propose en SMD.

### 3.3 MESURE DE LA BATTERIE

3.3.1 | Mesure de la tension
| Schéma du diviseur :

La mesure de la tension est constituée d’un simple diviseur de tension pour avoir une tension variable d’un maximum de 3,3V lisible par une des entrées analogiques du Pic. En considérant que la batterie aura une tension maximale de 14V on peut facilement dimensionner le diviseur en déterminant que Rtot vaux 100 kOhm pour limiter un maximum le courant :


Phase de design | Page 9 sur 13 | 6-févr.-19

R8 =

100 ∗ 3,3
14 = 23,57kOℎm

Pour R8 22kOhm fonctionnerait mais pour avoir une marge d’erreur j’ai choisi la valeur inférieure de 18kOhm. On peut ensuite trouver la résistance R5 qui vaudra 82 kOhm, ce qui fait parfaitement 100 kOhm au total.

3.3.2 Mesure du courant

Schéma du LM8601 :

Pour mesurer le courant j’utilise un LM8601. Il s’agit basiquement d’un ampli OP. Le dimensionnement à faire ici est la résistance. Le but de cette résistance est de créer une chute de tension en fonction du courant qui la traverse pour créer une différence entre les deux entrées de l’ampli OP.

Pour la dimensionner, il faut que la valeur de la résistance soit suffisamment haute pour que la chute de tension au courant maximum soit exploitable, mais la plus basse possible pour minimiser les pertes. Dans cette optique, on m’a conseillé de ne pas dépasser 1V de chute de tension aux bornes de la résistance lorsque le courant est maximum. Maintenant en divisant cette chute de tension par le courant que la batterie aura à fournir au maximum dans le pire des cas, on trouve la valeur de la résistance :

Calcul du courant :

Imax =

Imatrice ∗ 2 ∗ 5+ I3,3V ∗ 3,3
12 | = 5,14A

Le courant max ne devrait pas dépasser les 5,14A mais j’ai fait la suite des calculs en considérant le courant max à 5A. Car comme c’est un courant estimé et extrême qui ne devrait jamais survenir plus de quelques secondes. L’arrondir à 5A donne une valeur de résistance plus simple.

Calcul de la résistance :

Rsℎunt =

1
5

= 0,2Oℎm

Phase de design | Page 10 sur 13 | 6-févr.-19

### 4. CONCEPT DU LOGICIEL

### 4.1 LOGICIEL DE BASE

Le Totem pourra être contrôlé uniquement au travers du module Wifi. Voilà une liste de ce qu’il sera possible de faire :

- Pouvoir afficher tous les caractères de l’alphabet en majuscule ainsi que tous les chiffres.
- Mettre à jour le texte à afficher.
- Modifier la luminosité ou demander au Totem de la régler lui-même.
- Modifier la fréquence d’affichage, faire en sorte que le texte tourne en permanence ou que une fois toutes les 5 secondes par exemple.
- Demander au Totem d’afficher le niveau de batterie.

### 4.2 AMÉLIORATIONS

Si aucun problème majeur ne ce présente lors de la réalisation du projet, le logiciel de base avec les fonctions citées ci-dessus sera fait et fonctionnel. Cependant, je pense qu’il y a beaucoup d’améliorations qui peuvent être ajoutées. Si mon avancement le permet voici la liste des fonctions que j’aimerais pouvoir ajouter de la plus importante à la moins importante selon moi :

1. Pouvoir modifier la couleur du texte voire de chaque caractère.
2. Etendre le nombre de caractère possible à celui de la table ascii.
3. Ajouter des animations.
4. Faire un mode d’affichage optimisé à différentes consommations permettant d’estimer précisément combien de temps encore le Totem pourra rester allumé.

### 4.3 IDÉES POSSIBLES

Il est très peut probable que je réussisse à faire le logiciel de base avec toutes les améliorations que j’aimerais y amener mais si j’y arrive et qu’il me reste du temps, voici des idées que j’ai eues pour la suite :

- Augmenter le nombre de caractères à la table ascii étendue.
- Ajouté un mode d’édition de la matrice depuis l’application wifi. Ce mode permettrait de modifier indépendamment chaque LED des deux matrices. Ce mode permettrait aussi de modifier la matrice de manière automatique depuis un PC par exemple sans devoir modifier le code dans le Pic.

### 4.4 GÉSTION DES LED

Les LED des matrices sont des WS2812B qui sont des LED RGB avec un chip permettant une communication en série, ce qui permet de contrôler les 512 LED avec une seule ligne de commande. Pour pouvoir les commander il faut donc respecter un protocole, chaque LED prend 24 bits, les bits sont envoyés à une vitesse de 800kHz, chaque bit que ce soit un 1 ou un 0 possède un temps à l’état haut et un temps à l’état bas, ce qui permet entre autres de transmettre l’horloge.

C’est pourquoi l’utilisation d’une ligne SPI pour contrôler les LED fonctionne bien, en utilisant un SPI travaillant à une fréquence 8 fois plus élevée que celle nécessaire pour gérer les LED un byte du SPI correspondra à un bit pour les LED et donc en transmettant 1000’0000 on obtiendras un 0 et 1111’1110 un 1.


Phase de design | Page 11 sur 13 | 6-févr.-19

### 5. BOITIER ET PCB

Pour le boîtier, la forme sera normalement très semblable à ce que j’ai dessiné. Pour déterminer les dimensions du boîtier, il faut partir du diamètre que les deux matrices vont créer une fois mises en cercle. Vu que la longueur des matrices est connue, le diamètre peut se trouver facilement :

p =

320 ∗ 2
π

= 204mm

La hauteur de la tête est en partie déterminé par la hauteur des matrices qui font 8cm de haut, À la hauteur des matrices s’ajoute l’épaisseur des disques inférieurs et supérieurs. Au total la tête fera environ 10cm de haut.

Le diamètre des matrices permet de connaitre le diamètre maximal du PCB, environ 20cm de diamètre. Cependant pour le diamètre du PCB je vais partir sur un PCB rond de 18cm de diamètre ce qui devrait être amplement suffisant au cas ou cela ne suffit pas il reste encore un peu de marge.

### 6. SCHÉMA BATTERIE

La partie charge de la batterie, interrupteur et panneau solaire se trouvera dans et sur la base. Cette partie ne sera pas faite sur PCB mais câblée. Voici le schéma :


Phase de design | Page 12 sur 13 | 6-févr.-19

### 7. CHOIX DES PINS

Pour visualiser le choix des pins sur le pic j’ai fait ce tableau :

La première chose à faire pour correctement choisir les pins est de savoir ce qu’il faut et pour quel élément :

- Trois entrées analogiques, deux pour la mesure de la batterie et une pour la luminosité.
- Un SPI à 4 fil et 4 IO pour le module Wifi.
- Une IO pour activer, désactiver l’alimentation 5V.
- PGED, PGEC.
- Les alimentations.

Une fois déterminé il faut les placer. Le plus simple est de d’abord placé celle qui on le plus de restriction. Les alimentations ne peuvent pas être placé ailleurs que sur les pattes d’alimentation, de ce fait la question de ou les mettre ne se pose même pas. Ensuite le module Wifi est celui qui monopolise le plus de pattes, de plus il a besoin d’un SPI, pour le SPI 1 la patte SCK1 est la seul à être imposer les autres son des pps ce qui fait quel peuvent être placer presque librement. J’ai donc essayé de placer les huit pattes destiner au module wifi sur le moins de côté du Pic possible. J’ai placer les deux pattes de programmation sur PGEC1 et PGED1 car elles étaient libres. Finalement j’ai placé les pattes restantes en essayant d’imaginé ou seront placer les composant sur le PCB.

Phase de design | Page 13 sur 13 | 6-févr.-19

### 8. CONCLUSION

Suite à la présentation, certains éléments vont être ajouter et d’autre modifier :

- Pour commencer, le régulateur 3,3V seras remplacer par un LM2674 car il n’est pas nécessaire de fournir plus de 500mA à 3,3V.
- Une série de connecteurs seras ajouter pour y relier les alimentations et les pin no connecte du Pic.
- Le schéma de la batterie sera très certainement modifié.
- Le PCB serra certainement fait dans le but d’être le plus petit possible et de forme rectangulaire pour limiter les couts.

Pour le régulateur 3,3V LM2674 la méthode de dimensionnement des composant ainsi que le schéma exemple son exactement les mêmes. Ce qui fait qu’il suffit de faire la même démarche mais cette fois-ci pour un courant de 500mA avec le datasheet du LM2674 pour corriger le mauvais choix du régulateur.

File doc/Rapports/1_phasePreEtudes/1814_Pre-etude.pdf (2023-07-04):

ETML

Pre-étude | Page 1 sur 9 | 13-déc.-18

# Pre-étude de projet

# École supérieure

## Électronique

## PROJ Salle R110

# TOTEM LUMINEUX

## Réalisé par :

## Nicolas Fürst

## Dates :

## 13 décembre 2018

Pre-étude | Page 2 sur 9 | 13-déc.-18

## Table des matières

Pre-étude | Page 3 sur 9 | 13-déc.-18

### 1. CAHIER DES CHARGES

- Totem lumineux à LED pour extérieur.
- Animation colorée.
- Possibilité d'afficher un mot ou un texte défilant.
- Lisible depuis toutes directions.
- Tête à monter sur un mat pour l'élever.
- Alimentation sur batterie, rechargeable par externe et panneau solaire.
- Longue autonomie, environ 24H.
- Commande via Wifi, 4G ou Bluetooth.
- LED RGB - gestion de la batterie.
- Utilisable en extérieur.
- Gérer par un Pic32MX.
- Affichage circulaire avec une matrice souple.

### 2. DONNÉE DE BASE

Mon projet doit être un totem lumineux capable d’afficher des textes ou des messages visible distance. Pour ce faire je vais réaliser une sorte de soucoupe avec deux matrices souples qui viendra se placer sur un mat d’environ deux mètre de haut.
Le tout aura une autonomie d’environ 24h avec la possibilité en cas de soleil de la recharger avec un panneau solaire.
Les messages à afficher ou les animations seront déterminer via une application, les données transmise via 4G, WIFI ou Bluetooth.
La structure devra être utilisable en extérieure ce qui veut dire entre autres qui faudrait qu’elle soit water proof.

### 3. PLANNING

Semaine | 1 | 2 | 3 | 4 | 5 | 6 | 7 | 8 | 9 | 10 | 11 | 12 | 13 | 14 | 15 | 16 | 17 | 18 | 19 | 20 | 21 | 22 | 23 | 24
Schéma
PCB
Montage
Programmation


Pre-étude | Page 4 sur 9 | 13-déc.-18

### 4. SHÉMA BLOQUE ET ÉXPLICATION COMPOSANT

### 4.1 PIC32

Pour le choix du microcontrôleur j’ai simplement prix le même que la plupart des projets s’est à dire un PIC32MX795H :
http://ww1.microchip.com/downloads/en/DeviceDoc/80000480P.pdf
Ce PIC possède plus que ce qu’il me faut, c’est à dire :
- Un UART pour le module WIFI.
- Une sortie SPI pour les matrices de LED.
- Au moins deux entrées analogiques, une pour le capteur de luminosité et une pour un potentielle contrôle de la tension de batterie.
- Plusieurs I/O au cas où il faut ajouter des boutons ou autre.

### 4.2 MATRICE X2

Deux matrices de 256 LED RGB ws2812b/sk6812 de chez Adafruit : https://www.adafruit.com/product/2294

Capteur de
luminosité


Pre-étude | Page 5 sur 9 | 13-déc.-18

Les deux matrices seraient disposées en cercle formant une sorte de soucoupe de 8 LED de haut et 64 de périmètre.

Il sera possible d’afficher entre 10 et 12 caractères en même temp et de faire tourner le texte pour en afficher plus et le rendre lisible de tous les coté.

Au niveau de la consommation après plusieurs mesures que l’on peut trouver dans le fichier Excel. Les LED peuvent consommer jusqu’à 64W ce qui est énorme mais pour quelle consomme autant il faut qu’elles soient toutes allumées en blanc et à la luminosité maximum ce qui fait un vrai lampadaire.
Je pense que pour une utilisation normale la consommation moyenne devrait se trouver entre 5 et 10 W ce qui est déjà beaucoup plus raisonnable.
D’après les mesures que j’ai faites il serait possible descendre en dessous de 2W et de toujours avoir un texte lisible, cependant la luminosité serais grandement atteinte et en plein soleil j’ai des doutes sur la lisibilité du texte.
Avec mes mesures j’ai également remarqué que les LED consomment même si elles sont éteintes, avec les deux matrice la consommation des LED éteintes vaut 1,73Wh.

En conclusion pour les deux matrices je pense qu’il sera définitivement possible d’avoir un excellent rendu à une consommation raisonnable. La consommation peut non seulement être réduite en réduisant la luminosité des LED mais également en n’affichant pas le texte en permanence par exemple. Comme je l’ai remarqué si les LED sont alimentées on ne peut pas consommer mois de 1,7Wh
, pour économiser encore plus il faudrait ajouter un système qui coupe l’alimentation des LED quand elles sont éteintes

4.2.1 Autres possibilités

Parmi les autres possibilités, il y avait faire une seule matrice de LED qui tournerais sur elle-même. Mais cette méthode nécessite de faire passer au minimum la masse et le positive au travers d’un axe ce qui est très compliqué.
Il aurait également été possible d’utiliser 4 matrices formant un carré. Mais la consommation par rapport au deux matrices souples n’auraient pas changé dû au nombre de LED quasi identique donc quatre matrices en carré résulteraient juste en un affichage moins bien lisible.

Pre-étude | Page 6 sur 9 | 13-déc.-18

### 4.3 MODULE WIFI

Pour le module Wifi, j’ai trouvé trois modules potentiels le esp32 qui est le module que Patrick Favre va utiliser pour son projet.

La deuxième possibilité est assez similaire, s’est le RN171.

Et enfin la dernière et celle que je choisirais pour l’instant car par rapport au deux autres il est possible de si connecter depuis une page internet est le MRF24Wn0MA / ATWILC1000.

### 4.4 APPLICATION

Il n’est pas prévu pour l’instant que je réalise l’application, je ne me suis donc pas encore renseigné sur le sujet.

### 4.5 BATTERIE

La première chose à savoir pour pouvoir choisir la batterie est quel volume doit-elle faire. Pour le déterminer il me suffit de multiplier l’autonomie désirer [h] par la consommation moyenne de mon système :
Pour l’autonomie l’objectif est de 24H au mieux, mais pour la consommation s’est un peu plus compliquer. Premièrement je considère la consommation des LED comme l’unique consommation du système car le reste (Pic, module wifi) ont une consommation négligeable par rapport au LED. Comme l’autonomies est désirer dans le meilleur des cas je considère quelle seras possible à une consommation réduite. Je choisi donc 2Wh qui selon moi est une consommation atteignable.
La batterie devra donc avoir une capacité minimum de 24 * 2 = 48Wh.

Une fois la capacité trouver deux solutions son possible : Batterie au plomb ou batterie au lithium. Cependant vus qu’il faut une grande capacité les batteries au lithium son moins envisageable.
Le prix/Wh des batteries au lithium est beaucoup plus élever que pour celle au plomb ce qui en fait le premier mauvais point.
Ensuite due à la grande capacité nécessaire il faut plusieurs cellules ce qui rend la charge et la gestion de la sécurité des batteries au lithium très compliquer alors que la gestion de charge est un jeu d’enfant avec une batterie au plomb.

Les gros inconvénients d’une batterie au plomb sont sa taille et son poids, mais ce n’est pas un problème pour mon projet car le Totem na pas pour objectif d’être déplacer en permanence et il est parfaitement possible de faire une sorte de boite ou de cage à la base du totem pour y ranger la batterie.

Après quelque recherche j’ai trouvé cette batterie chez distrelec : https://www.distrelec.ch/fr/batterie-au-plomb-12-ah-fiammfg20722/p/30047216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 (https://www.distrelec.ch/fr/batterie-au-plomb-12-ah-fiamm-fg20722/p/30047216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) Cette batterie fait 7,2Ah pour 12V ce qui fait 86,4Wh ce qui est largement au-dessus des 48Wh minimum calculer. Ça taille et son poids son également parfaitement raisonnable.

Avec cette batterie l’autonomie a consommation minimum :

Consommation | Minimum, 2Wh | Moyenne, 5Wh | Moyenne, 10Wh | Maximum 30Wh
Autonomie | 43,2h | 17,2h | 8,6h | 2,88h

Avec la batterie on peut facilement atteindre 12h avec la consommation moyenne que j’ai estimée, en plus avec le panneau solaire cette autonomie peut être grandement améliorer. En plus si le Totem est utilisé en mode basse consommation, selon mes estimations il est presque possible d’atteindre 2 jour non-stop d’utilisation.

Mais plusieurs problèmes peuvent apparaitre avec une batterie de moto avec les charges décharge répéter. Voir la batterie à utilisé dans le point panneau solaire

### 4.6 PANNEAU SOLAIRE / GESTION DE CHARGE


Pre-étude | Page 7 sur 9 | 13-déc.-18

Pour le panneau solaire, on m’a conseillé de prendre un kit qui comprend panneau, régulateur de charge et une batterie AGM qui est une batterie au plomb un peu spéciale adapté pour les panneaux solaires.
J’ai assez vite trouvé ce kit de chez swiss green : https://www.swiss-green.ch/fr/kits-solaires-standard/39286460-kit-solaire-420-wh-12v.html

Il comprend un panneau solaire de 20Wpeak, un régulateur de charge de 5A et une batterie au plomb AGM de 12V 8Ah ce qui fait pile le double en capacité du minimum que j’ai calculer.

### 4.7 PORT DE CHARGE

En plus du panneau solaire il faut un port de charge secteur pour pouvoir le charger sans dépendre du soleil. Le seul problème est que le régulateur de charge qui viens avec le panneau solaire ne possède pas d’entrer secondaire. Ma solution est donc de directement brancher une alimentation de 24V sur l’entrée du panneau solaire comme ceci :

Vus que l’entrée du panneau solaire doit être d’un maximum de 30V pour une batterie de 12V :

Une alimentation de 24V comme celle-ci fait parfaitement l’affaire : https://www.amazon.fr/LED-Alimentation-151W-MeanWell-LPV-150-24/dp/B01CGQRYZY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 (https://www.amazon.fr/LED-Alimentation-151W-MeanWell-LPV-150-24/dp/B01CGQRYZY) Sachant que c’est un régulateur de charge de 5A pour une batterie de 12V ça ne sert à rien d’avoir une alimentation de plus de 3A pour 24V.


Pre-étude | Page 8 sur 9 | 13-déc.-18

### 4.8 REGULATEURS

Le régulateur de 3,3V est simplement là pour le PIC se seras donc le même que pour les autres s’est à dire un :

Mais pour les LED s’est différent il faut un régulateur capable de fournir au minimum 3A à 5V constant et jusqu’à 12,8A au cas ou toutes les LED devais être allumé à la luminosité maximum.
Vus qu’il y aura deux matrices il est possible si nécessaire de faire deux régulateurs chacun de 6,5A.

Après de multiple recherche je n’ai pas trouvé de composant tous en un avec un courant de sortie aussi élever. Mais à la suite du conseil de Yann Dacosta j’ai utilisé un des outils de Texas Instrument pour désigner un step down buck converter.
Voici un des montages qui tourne autour du TPS40345DRC : http://www.ti.com/lit/ds/symlink/tps40345.pdf

Pour retrouver la simulation il faut mettre sur ce lien : https://webench.ti.com/powerdesigner/switching-regulator (https://webench.ti.com/power-designer/switching-regulator) les paramètres suivants : VinMin = 12V VinMax = 12V, Vout = 5V et IoutMax = 13A. Ensuite s’est le premier résultat.
Cette solution semble adéquate mais elle pose des problèmes au niveau du routage et du montage.

S’est pourquoi comme autre solution il y aurais un ou deux convertisseur DCDC comme celui-ci : https://www.mouser.ch/ProductDetail/GE-Critical-Power/NQR010A0X4Z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. (https://www.mouser.ch/ProductDetail/GE-Critical-Power/NQR010A0X4Z)

### 4.9 CAPTEUR DE LUMINOSITÉ

Le capteur de luminosité servira à mesurer l’intensité lumineuse de l’environnement dans lequel ce trouve le totem, et adapte la luminosité des LED pour quelles restent visible. Plus l’environnement est lumineux plus les LED le seront.

Pour ça il y a une multitude de capteur disponible. Mais mon choix s’est tourné vers un capteur de luminosité ambiante sous forme de LED : https://www.distrelec.ch/fr/capteur-de-luminosite-ambiante-570-nm-vishay-tept-4400/p/17522426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. 06 (https://www.distrelec.ch/fr/capteur-de-luminosite-ambiante-570-nm-vishay-tept-4400/p/17522426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)

Pre-étude | Page 9 sur 9 | 13-déc.-18

### 5. ÉSTIMATION DES COUTS

Composant | Prix
PIC | 10 .-
Module WIFI | 5 à 18.-
Régulateurs | 5 à ~20.-
Panneau solaire, batterie et régulateur | 230.-
Matrices X2 | 200.-
Composant divers | 5 à 20.-
Total | 455 à 498.-

### 6. CONCLUSION

En conclusion, bien que j’aie encore des doutes sur certains composants comme pour le régulateur de 12V à 5V. Je pense pouvoir me lancer dans le développement du schéma.

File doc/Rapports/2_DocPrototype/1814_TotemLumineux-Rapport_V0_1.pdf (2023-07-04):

ETML

Rapport final | Page 1 sur 41 | 20-juin-19

# Rapport Final

# École supérieure

## Électronique

## PROJ Salle R110

# TOTEM LUMINEUX

## Réalisé par :

## Nicolas Fürst

## Date :

## 20 Juin 2019

Rapport final | Page 2 sur 41 | 20-juin-19

Rapport final | Page 3 sur 41 | 20-juin-19

## Table des matières

Rapport final | Page 4 sur 41 | 20-juin-19

Rapport final | Page 5 sur 41 | 20-juin-19

## PRÉ-ÉTUDE

### 1. CAHIER DES CHARGES

- Totem lumineux à LED pour extérieur.
- Animation colorée.
- Possibilité d'afficher un mot ou un texte défilant.
- Lisible depuis toutes directions.
- Tête à monter sur un mat pour l'élever.
- Alimentation sur batterie, rechargeable par secteur et panneau solaire.
- Longue autonomie, environ 24H.
- Commande via Wifi, 4G ou Bluetooth.
- LED RGB - gestion de la batterie.
- Utilisable en extérieur.
- Gérer par un Pic32MX.
- Affichage circulaire avec une matrice souple.

### 2. DONNÉE DE BASE

Mon projet doit être un totem lumineux capable d’afficher des textes ou des messages visible distance. Pour ce faire je vais réaliser une sorte de soucoupe avec deux matrices souples qui viendra se placer sur un mat d’environ deux mètre de haut.
Le tout aura une autonomie d’environ 24h avec la possibilité en cas de soleil de la recharger avec un panneau solaire.
Les messages à afficher ou les animations seront déterminer via une application, les données transmise via 4G, WIFI ou Bluetooth.
La structure devra être utilisable en extérieure ce qui veut dire entre autres qui faudrait qu’elle soit water proof.

### 3. PLANNING

Semaine | 1 | 2 | 3 | 4 | 5 | 6 | 7 | 8 | 9 | 10 | 11 | 12 | 13 | 14 | 15 | 16 | 17 | 18 | 19 | 20 | 21 | 22 | 23 | 24
Schéma
PCB
Montage
Programmation


Rapport final | Page 6 sur 41 | 20-juin-19

### 4. SHÉMA BLOQUE ET ÉXPLICATION COMPOSANT

### 4.1 PIC32

Pour le choix du microcontrôleur j’ai simplement prix le même que la plupart des projets s’est à dire un PIC32MX795H :
http://ww1.microchip.com/downloads/en/DeviceDoc/80000480P.pdf
Ce PIC possède plus que ce qu’il me faut, c’est à dire :
- Un UART pour le module WIFI.
- Une sortie SPI pour les matrices de LED.
- Au moins deux entrées analogiques, une pour le capteur de luminosité et une pour un potentielle contrôle de la tension de batterie.
- Plusieurs I/O au cas où il faut ajouter des boutons ou autre.

### 4.2 MATRICE X2

Deux matrices de 256 LED RGB ws2812b/sk6812 de chez Adafruit : https://www.adafruit.com/product/2294

Capteur de
luminosité

Rapport final | Page 7 sur 41 | 20-juin-19

Les deux matrices seraient disposées en cercle formant une sorte de soucoupe de 8 LED de haut et 64 de périmètre.

Il sera possible d’afficher entre 10 et 12 caractères en même temp et de faire tourner le texte pour en afficher plus et le rendre lisible de tous les coté.

Au niveau de la consommation après plusieurs mesures que l’on peut trouver dans le fichier Excel. Les LED peuvent consommer jusqu’à 64W ce qui est énorme mais pour quelle consomme autant il faut qu’elles soient toutes allumées en blanc et à la luminosité maximum ce qui fait un vrai lampadaire.
Je pense que pour une utilisation normale la consommation moyenne devrait se trouver entre 5 et 10 W ce qui est déjà beaucoup plus raisonnable.
D’après les mesures que j’ai faites il serait possible descendre en dessous de 2W et de toujours avoir un texte lisible, cependant la luminosité serais grandement atteinte et en plein soleil j’ai des doutes sur la lisibilité du texte.
Avec mes mesures j’ai également remarqué que les LED consomment même si elles sont éteintes, avec les deux matrice la consommation des LED éteintes vaut 1,73Wh.

En conclusion pour les deux matrices je pense qu’il sera définitivement possible d’avoir un excellent rendu à une consommation raisonnable. La consommation peut non seulement être réduite en réduisant la luminosité des LED mais également en n’affichant pas le texte en permanence par exemple. Comme je l’ai remarqué si les LED sont alimentées on ne peut pas consommer mois de 1,7Wh
, pour économiser encore plus il faudrait ajouter un système qui coupe l’alimentation des LED quand elles sont éteintes

4.2.1 Autres possibilités

Parmi les autres possibilités, il y avait faire une seule matrice de LED qui tournerais sur elle-même. Mais cette méthode nécessite de faire passer au minimum la masse et le positive au travers d’un axe ce qui est très compliqué.
Il aurait également été possible d’utiliser 4 matrices formant un carré. Mais la consommation par rapport au deux matrices souples n’auraient pas changé dû au nombre de LED quasi identique donc quatre matrices en carré résulteraient juste en un affichage moins bien lisible.

### 4.3 MODULE WIFI

Pour le module Wifi, j’ai trouvé trois modules potentiels le esp32 qui est le module que Patrick Favre va utiliser pour son projet.

La deuxième possibilité est assez similaire, s’est le RN171.

Et enfin la dernière et celle que je choisirais pour l’instant car par rapport au deux autres il est possible de si connecter depuis une page internet est le MRF24Wn0MA / ATWILC1000.

Rapport final | Page 8 sur 41 | 20-juin-19

### 4.4 APPLICATION

Il n’est pas prévu pour l’instant que je réalise l’application, je ne me suis donc pas encore renseigné sur le sujet.

### 4.5 BATTERIE

La première chose à savoir pour pouvoir choisir la batterie est quel volume doit-elle faire. Pour le déterminer il me suffit de multiplier l’autonomie désirer [h] par la consommation moyenne de mon système :
Pour l’autonomie l’objectif est de 24H au mieux, mais pour la consommation s’est un peu plus compliquer. Premièrement je considère la consommation des LED comme l’unique consommation du système car le reste (Pic, module wifi) ont une consommation négligeable par rapport au LED. Comme l’autonomies est désirer dans le meilleur des cas je considère quelle seras possible à une consommation réduite. Je choisi donc 2Wh qui selon moi est une consommation atteignable.
La batterie devra donc avoir une capacité minimum de 24 * 2 = 48Wh.

Une fois la capacité trouver deux solutions son possible : Batterie au plomb ou batterie au lithium. Cependant vus qu’il faut une grande capacité les batteries au lithium son moins envisageable.
Le prix/Wh des batteries au lithium est beaucoup plus élevé que pour celle au plomb ce qui en fait le premier mauvais point.
Ensuite due à la grande capacité nécessaire il faut plusieurs cellules ce qui rend la charge et la gestion de la sécurité des batteries au lithium très compliquer alors que la gestion de charge est un jeu d’enfant avec une batterie au plomb.

Les gros inconvénients d’une batterie au plomb sont sa taille et son poids, mais ce n’est pas un problème pour mon projet car le Totem na pas pour objectif d’être déplacer en permanence et il est parfaitement possible de faire une sorte de boite ou de cage à la base du totem pour y ranger la batterie.

Après quelque recherche j’ai trouvé cette batterie chez distrelec : https://www.distrelec.ch/fr/batterie-au-plomb-12-ah-fiamm-fg20722/p/30047216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 (https://www.distrelec.ch/fr/batterie-au-plomb-12-ah-fiamm-fg20722/p/30047216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) Cette batterie fait 7,2Ah pour 12V ce qui fait 86,4Wh ce qui est largement au-dessus des 48Wh minimum calculer. Ça taille et son poids son également parfaitement raisonnable.

Avec cette batterie l’autonomie a consommation minimum :

Consommation | Minimum, 2Wh | Moyenne, 5Wh | Moyenne, 10Wh | Maximum 30Wh
Autonomie | 43,2h | 17,2h | 8,6h | 2,88h

Avec la batterie on peut facilement atteindre 12h avec la consommation moyenne que j’ai estimée, en plus avec le panneau solaire cette autonomie peut être grandement améliorer. En plus si le Totem est utilisé en mode basse consommation, selon mes estimations il est presque possible d’atteindre 2 jour non-stop d’utilisation.

Mais plusieurs problèmes peuvent apparaitre avec une batterie de moto avec les charges décharge répéter. Voir la batterie à utiliser dans le point panneau solaire

### 4.6 PANNEAU SOLAIRE / GESTION DE CHARGE

Pour le panneau solaire, on m’a conseillé de prendre un kit qui comprend panneau, régulateur de charge et une batterie AGM qui est une batterie au plomb un peu spéciale adapté pour les panneaux solaires. J’ai assez vite trouvé ce kit de chez Swiss green : https://www.swiss-green.ch/fr/kits-solaires-standard/39286460-kit-solaire-420-wh-12v.html

Il comprend un panneau solaire de 20Wpeak, un régulateur de charge de 5A et une batterie au plomb AGM de 12V 8Ah ce qui fait pile le double en capacité du minimum que j’ai calculer.


Rapport final | Page 9 sur 41 | 20-juin-19

### 4.7 PORT DE CHARGE

En plus du panneau solaire il faut un port de charge secteur pour pouvoir le charger sans dépendre du soleil. Le seul problème est que le régulateur de charge qui viens avec le panneau solaire ne possède pas d’entrer secondaire. Ma solution est donc de directement brancher une alimentation de 24V sur l’entrée du panneau solaire comme ceci :

Vus que l’entrée du panneau solaire doit être d’un maximum de 30V pour une batterie de 12V :

Une alimentation de 24V comme celle-ci fait parfaitement l’affaire : https://www.amazon.fr/LED-Alimentation-151W-MeanWell-LPV-150-24/dp/B01CGQRYZY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 (https://www.amazon.fr/LED-Alimentation-151W-MeanWell-LPV-150-24/dp/B01CGQRYZY) Sachant que c’est un régulateur de charge de 5A pour une batterie de 12V ça ne sert à rien d’avoir une alimentation de plus de 3A pour 24V.

### 4.8 REGULATEURS

Le régulateur de 3,3V est simplement là pour le PIC se seras donc le même que pour les autres s’est à dire un : LM2674M

Mais pour les LEDs s’est différent il faut un régulateur capable de fournir au minimum 3A à 5V constant et jusqu’à 12,8A au cas où toutes les LEDs devaient être allumé à la luminosité maximum.
Vus qu’il y aura deux matrices il est possible si nécessaire de faire deux régulateurs chacun de 6,5A.

Après de multiple recherche je n’ai pas trouvé de composant tous en un avec un courant de sortie aussi élever. Mais à la suite du conseil de Yann Dacosta j’ai utilisé un des outils de Texas Instrument pour désigner un step down buck converter.
Voici un des montages qui tourne autour du TPS40345DRC : http://www.ti.com/lit/ds/symlink/tps40345.pdf


Rapport final | Page 10 sur 41 | 20-juin-19

Pour retrouver la simulation il faut mettre sur ce lien : https://webench.ti.com/power-designer/switching-regulator (https://webench.ti.com/power-designer/switching-regulator) les paramètres suivants : VinMin = 12V VinMax = 12V, Vout = 5V et IoutMax = 13A. Ensuite s’est le premier résultat.
Cette solution semble adéquate mais elle pose des problèmes au niveau du routage et du montage.

C’est pourquoi comme autre solution il y aurais un ou deux convertisseur DCDC comme celui-ci : https://www.mouser.ch/ProductDetail/GE-Critical-Power/NQR010A0X4Z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. (https://www.mouser.ch/ProductDetail/GE-Critical-Power/NQR010A0X4Z)

### 4.9 CAPTEUR DE LUMINOSITÉ

Le capteur de luminosité servira à mesurer l’intensité lumineuse de l’environnement dans lequel se trouve le totem, et adapte la luminosité des LEDs pour qu’elles restent visible. Plus l’environnement est lumineux plus les LED le seront.

Pour ça il y a une multitude de capteur disponible. Mais mon choix s’est tourné vers un capteur de luminosité ambiante sous forme de LED : https://www.distrelec.ch/fr/capteur-de-luminosite-ambiante-570-nm-vishay-tept-4400/p/17522426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. 06 (https://www.distrelec.ch/fr/capteur-de-luminosite-ambiante-570-nm-vishay-tept-4400/p/17522426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)

### 5. ÉSTIMATION DES COUTS

Composant | Prix
PIC | 10 .-
Module WIFI | 5 à 18.-
Régulateurs | 5 à ~20.-
Panneau solaire, batterie et régulateur | 230.-
Matrices X2 | 200.-
Composant divers | 5 à 20.-
Total | 455 à 498.-

Rapport final | Page 11 sur 41 | 20-juin-19

## PHASE DE DESIGN

### 6. DESCRIPTION

### 6.1 APPARENCE

En apparence, la tête du totem fera un peu plus de 20 cm de diamètre pour 10 de haut, les deux matrices de 256 LED feront tout le tour afin de pouvoir afficher du texte lisible depuis toutes les directions. Le PCB avec le pic et tout le reste se situera dans la tête.

La base sera moins complexe, elle devra déjà maintenir le mât et la tête droits et stables et contenir la batterie, le panneau solaire, les deux régulateurs de charge avec le port de charge et finalement l’interrupteur on/off. La base pourra donc simplement être une boîte contenant le tout et maintenant le panneau solaire à l’extérieur.

### 6.2 FONCTIONNALITÉ

En plus de pouvoir afficher un texte par Wifi, il sera possible de changer la couleur du texte, choisir d’afficher différentes animations, modifier la luminosité soit automatiquement ou alors à l’aide d’un capteur et finalement le Totem mesurera la tension de la batterie régulièrement pour pouvoir signaler le niveau de batterie et adapter automatiquement la luminosité ou la fréquence d’affichage pour allonger l’autonomie du Totem et le maintenir allumé plus longtemps.

### 7. CHOIX EFFECTUÉ

### 7.1 PRÉ-ÉTUDE

Ce que j’avais déjà choisi lors de la pré-étude est resté. Que ce soit pour les matrices de LED, le kit batterie plus panneau solaire, le capteur de luminosité ou le design du Totem il n’y a pas eu de modification.

Cependant certains points n’étaient pas complétement résolus, notamment pour les régulateurs de tension 12V à 5V et pour le module Wifi. Depuis ses deux points ont été éclaircis .

Le module Wifi sera un ATWILC1000 de chez Microchip car il fallait un module ayant la possibilité de s’y connecter depuis une page Web. Le MRF24WN0MA a été mon premier choix car il a déjà été utilisé pour un précèdent projet, mais Microchip le considère obsolète et conseille d’utiliser son équivalent, le ATWILC1000.

Pour le régulateur, j’ai choisi de prendre deux NQR010A0X4. Je les ai choisis principalement pour une question de simplicité par rapport à celui créé sur mesure sur Texas Instrument et en fonction du coup.

### 7.2 SUPPLÉMENT

En plus de ce que j’ai prévu dans la pré-études, j’ai ajouté un LMP8601 qui permet de mesurer un courant. Cet ajout, en complément de la mesure de tension, permettra de mesurer le niveau de la batterie avec précision malgré les chutes de tension.

Le deuxième gros ajout est un deuxième régulateur de charge qui s’avère nécessaire pour avoir une charge par panneau solaire et par secteur.


Rapport final | Page 12 sur 41 | 20-juin-19

### 8. DIMENSSIONNEMENT

### 8.1 MESURE DE LA LUMINOSITÉ

Voici le schéma du capteur de luminosité :

Son fonctionnement est plutôt simple. Le phototransistor utilisé comme capteur fournit un courant en fonction de la luminosité qu’il perçoit, il suffit donc de faire passer ce courant dans une résistance pour pouvoir mesurer une tension sur un port analogique du pic. Pour dimensionner la résistance il faut déterminer la luminosité maximum que l’on veut pouvoir détecter en Lux, pour me donner une idée de ce que représente une valeur de luminosité je suis allé voir sur Wikipédia :

Grace à ce tableau je peux déterminer à peu près qu’il ne sera pas nécessaire de connaitre la luminosité ambiante si elle passe le cap des 5000 Lux. Une fois ce cap atteint l’affichage sera certainement déjà à sa luminosité maximale.


Rapport final | Page 13 sur 41 | 20-juin-19

Ensuite, dans le datasheet du capteur on peut facilement trouver la résolution du capteur (le nombre de mA par Lux) :

Malheureusement, dans le tableau on peut voir trois différents groupes de capteurs (A,B et C) qui ont chacun un rapport différent, mais Distrelec ne précise pas à quel groupe appartient leur capteur ce qui fait que selon le type du capteur la valeur de la résistance peut être amenée à changer. Pour l’instant j’ai considéré que le capteur se situera à 45 uA/20Lux ce qui donne les résultats suivants :

R =

3,3 ∗ 20
5000 = ~300Oℎm

### 8.2 RÉGULATEUR

8.2.1 | Régulateur 5V
| Schéma pour les deux régulateurs 5V :

Avec ces régulateurs, pour avoir une sortie à 5V il faut dimensionner le condensateur et les deux résistances. Pour ce faire on trouve dans le datasheet un schéma qui montre comment les câbler :


Rapport final | Page 14 sur 41 | 20-juin-19

Et des tableaux nous donnant les valeurs de résistance et de condensateur pour des tensions communes telles que 3,3V ou dans mon cas 5V :

Avec les tableaux on peut déterminer toutes les valeurs nécessaires : RTune (R2) = 47 Ohm, CTrim (C2) = 39nF et RTrim = 268 Ohm. Pour RTrim la valeur ne tombe pas sur une valeur facile à trouver, j’ai donc pris la valeur la plus proche dans la série E12 ce qui donne 270 Ohm. Pour vérifier l’impact que le changement de valeur a eu sur la tension de sortie, j’ai retourné la fonction servant à trouver RTrim en cas de tension hors valeur des tableaux :

Uout =

1,182
RTrim ∗ 10⁻³ − 0,591 = 4,97V

On peut voir que la tension reste extrêmement proche des 5V.

8.2.2 | Régulateur 3,3V
| Schéma du régulateur 3,3V :

Comme pour le régulateur 5V toutes les informations sur le dimensionnement des composants se trouvent dans le datasheet. Cette fois-ci cependant la tension de sortie est


Rapport final | Page 15 sur 41 | 20-juin-19

fixée à 3,3V dans le chip. Tous les dimensionnements se feront par rapport au courant nécessaire en sortie.

La première chose est le schéma exemple :

On peut voir que tous les composants sont déjà dimensionnés pour une application typique. J’ai repris la valeur des condensateurs tels quels mais j’ai quand même redimensionné la bobine et la diode.

Que ce soit pour la bobine ou la diode il faut commencer par déterminer le courant max de sortie nécessaire. Pour estimer le courant max j’ai simplement considérer environ 200mA pour le Pic et pour le module Wifi ce qui correspond à ce que j’ai pu trouver dans les datasheets, j’ai ensuite arrondi à 500mA pour compenser les autres éventuelles consommations.

Une fois ce courant max déterminé il suffit de trouver les valeurs correspondantes dans les tableaux :

Le tableau tombe pile entre deux bobines pour avoir de la marge j’ai choisi la bobine L23.

Le datasheet fournit un tableau avec des bobines correspondent aux références du premier tableau :


Rapport final | Page 16 sur 41 | 20-juin-19

J’ai choisi la bobine DO3308-683 car je voulais une bobine SMD et celle-ci se trouvait dans le vault de Altium.

Pour la diode on peut trouver un tableau similaire à la bobine :

Pour les diodes, toutes feraient l’affaire je me suis donc contenté de prendre la plus basique que le datasheet propose en SMD.

### 8.3 MESURE DE LA BATTERIE

8.3.1 | Mesure de la tension
| Schéma du diviseur :

Rapport final | Page 17 sur 41 | 20-juin-19

La mesure de la tension est constituée d’un simple diviseur de tension pour avoir une tension variable d’un maximum de 3,3V lisible par une des entrées analogiques du Pic. En considérant que la batterie aura une tension maximale de 14V on peut facilement dimensionner le diviseur en déterminant que Rtot vaux 100 kOhm pour limiter un maximum le courant :

R8 =

100 ∗ 3,3
14 = 23,57kOℎm

Pour R8 22kOhm fonctionnerait mais pour avoir une marge d’erreur j’ai choisi la valeur inférieure de 18kOhm. On peut ensuite trouver la résistance R5 qui vaudra 82 kOhm, ce qui fait parfaitement 100 kOhm au total.

8.3.2 Mesure du courant

Schéma du LM8601 :

Pour mesurer le courant j’utilise un LM8601. Il s’agit basiquement d’un ampli OP. Le dimensionnement à faire ici est la résistance. Le but de cette résistance est de créer une chute de tension en fonction du courant qui la traverse pour créer une différence entre les deux entrées de l’ampli OP.

Pour la dimensionner, il faut que la valeur de la résistance soit suffisamment haute pour que la chute de tension au courant maximum soit exploitable, mais la plus basse possible pour minimiser les pertes. Dans cette optique, on m’a conseillé de ne pas dépasser 1V de chute de tension aux bornes de la résistance lorsque le courant est maximum. Maintenant en divisant cette chute de tension par le courant que la batterie aura à fournir au maximum dans le pire des cas, on trouve la valeur de la résistance :

Calcul du courant :

Imax =

Imatrice ∗ 2 ∗ 5+ I3,3V ∗ 3,3
12 | = 5,14A

Le courant max ne devrait pas dépasser les 5,14A mais j’ai fait la suite des calculs en considérant le courant max à 5A. Car comme c’est un courant estimé et extrême qui ne devrait jamais survenir plus de quelques secondes. L’arrondir à 5A donne une valeur de résistance plus simple.

Calcul de la résistance :

Rsℎunt =

1
5

= 0,2Oℎm

Rapport final | Page 18 sur 41 | 20-juin-19

### 9. CONCEPT DU LOGICIEL

### 9.1 LOGICIEL DE BASE

Le Totem pourra être contrôlé uniquement au travers du module Wifi. Voilà une liste de ce qu’il sera possible de faire :

- Pouvoir afficher tous les caractères de l’alphabet en majuscule ainsi que tous les chiffres.
- Mettre à jour le texte à afficher.
- Modifier la luminosité ou demander au Totem de la régler lui-même.
- Modifier la fréquence d’affichage, faire en sorte que le texte tourne en permanence ou que une fois toutes les 5 secondes par exemple.
- Demander au Totem d’afficher le niveau de batterie.

### 9.2 AMÉLIORATIONS

Si aucun problème majeur ne se présente lors de la réalisation du projet, le logiciel de base avec les fonctions citées ci-dessus sera fait et fonctionnel. Cependant, je pense qu’il y a beaucoup d’améliorations qui peuvent être ajoutées. Si mon avancement le permet voici la liste des fonctions que j’aimerais pouvoir ajouter de la plus importante à la moins importante selon moi :

1. Pouvoir modifier la couleur du texte voire de chaque caractère.
2. Etendre le nombre de caractère possible à celui de la table ascii.
3. Ajouter des animations.
4. Faire un mode d’affichage optimisé à différentes consommations permettant d’estimer précisément combien de temps encore le Totem pourra rester allumé.

### 9.3 IDÉES POSSIBLES

Il est très peu probable que je réussisse à faire le logiciel de base avec toutes les améliorations que j’aimerais y amener mais si j’y arrive et qu’il me reste du temps, voici des idées que j’ai eues pour la suite :

- Augmenter le nombre de caractères à la table ascii étendue.
- Ajouté un mode d’édition de la matrice depuis l’application wifi. Ce mode permettrait de modifier indépendamment chaque LED des deux matrices. Ce mode permettrait aussi de modifier la matrice de manière automatique depuis un PC par exemple sans devoir modifier le code dans le Pic.

### 9.4 GÉSTION DES LED

Les LED des matrices sont des WS2812B qui sont des LED RGB avec un chip permettant une communication en série, ce qui permet de contrôler les 512 LED avec une seule ligne de commande. Pour pouvoir les commander il faut donc respecter un protocole, chaque LED prend 24 bits, les bits sont envoyés à une vitesse de 800kHz, chaque bit que ce soit un 1 ou un 0 possède un temps à l’état haut et un temps à l’état bas, ce qui permet entre autres de transmettre l’horloge.

C’est pourquoi l’utilisation d’une ligne SPI pour contrôler les LED fonctionne bien, en utilisant un SPI travaillant à une fréquence 8 fois plus élevée que celle nécessaire pour gérer les LED un byte du SPI correspondra à un bit pour les LED et donc en transmettant 1000’0000 on obtiendras un 0 et 1111’1110 un 1.


Rapport final | Page 19 sur 41 | 20-juin-19

### 10. BOITIER ET PCB

Pour le boîtier, la forme sera normalement très semblable à ce que j’ai dessiné. Pour déterminer les dimensions du boîtier, il faut partir du diamètre que les deux matrices vont créer une fois mises en cercle. Vu que la longueur des matrices est connue, le diamètre peut se trouver facilement :

p =

320 ∗ 2
π

= 204mm

La hauteur de la tête est en partie déterminé par la hauteur des matrices qui font 8cm de haut, À la hauteur des matrices s’ajoute l’épaisseur des disques inférieurs et supérieurs. Au total la tête fera environ 10cm de haut.

Le diamètre des matrices permet de connaitre le diamètre maximal du PCB, environ 20cm de diamètre. Cependant pour le diamètre du PCB je vais partir sur un PCB rond de 18cm de diamètre ce qui devrait être amplement suffisant au cas où cela ne suffit pas il reste encore un peu de marge.

### 11. SCHÉMA BATTERIE

La partie charge de la batterie, interrupteur et panneau solaire se trouvera dans et sur la base. Cette partie ne sera pas faite sur PCB mais câblée. Voici le schéma :

Rapport final | Page 20 sur 41 | 20-juin-19

### 12. CHOIX DES PINS

Pour visualiser le choix des pins sur le pic j’ai fait ce tableau :

La première chose à faire pour correctement choisir les pins est de savoir ce qu’il faut et pour quel élément :

- Trois entrées analogiques, deux pour la mesure de la batterie et une pour la luminosité.
- Un SPI à 4 fil et 4 IO pour le module Wifi.
- Une IO pour activer, désactiver l’alimentation 5V.
- PGED, PGEC.
- Les alimentations.

Une fois déterminé il faut les placer. Le plus simple est de d’abord placé celle qui on le plus de restriction. Les alimentations ne peuvent pas être placé ailleurs que sur les pattes d’alimentation, de ce fait la question de ou les mettre ne se pose même pas. Ensuite le module Wifi est celui qui monopolise le plus de pattes, de plus il a besoin d’un SPI, pour le SPI 1 la patte SCK1 est la seul à être imposer les autres sont des pps ce qui fait quel peuvent être placer presque librement. J’ai donc essayé de placer les huit pattes destiner au module wifi sur le moins de côté du Pic possible. J’ai placer les deux pattes de programmation sur PGEC1 et PGED1 car elles étaient libres. Finalement j’ai placé les pattes restantes en essayant d’imaginé ou seront placer les composant sur le PCB.


Rapport final | Page 21 sur 41 | 20-juin-19

## RÉALISATION

### 13. PCB

### 13.1 DIMENSSIONNEMENT DE LA CARTE

Vus que aucun boitier ou design particulier n’a été imposé dans le cahier des charge, il n’y avait pas réellement de contrainte concernant la taille du PCB. Cependant de légère contrainte son apparu lors de la phase de design. Il a été décider de placer le PCB au centre des deux matrices de LEDs ce qui limite la taille du PCB au périmètre des matrices :

d =

p
π

=

640
π

≅ 203,72mm

Due aux matrices le PCB ne pouvait pas être plus grand qu’un rond de 204mm de diamètre ou un carré de 144mm x 144mm.
Ces dimension calculé sont plus que suffisante pour les composant qu’il fallait monter, j’ai donc fait le PCB au plus petit et finalement c’est un rectangle de 110mm par 87mm.

### 13.2 PLACEMENT

Pour la plus parts des composants il n’y avait pas de grande contrainte pour le placement ou pour le routage, seul le module wifi et les connecteurs avait un placement restreint et un routage particulier.

Voilà à quoi ressemble la carte. La séparation délimite, en haut la partie logique et en bas la partie puissance et alimentation.

Rapport final | Page 22 sur 41 | 20-juin-19
13.2.1 | Partie puissance
| En bas dans les encadrés orange j’ai placé les borniers d’alimentation des matrices, les deux sont identique et indépendant, deux bornier à droite pour alimenter la matrice droite et pareil du côté gauche pour alimenter la deuxième matrice chacun ayant un régulateur 5V. De nombreuse contrainte on mener à les placer là, la première est qu’ils doivent être au bord pour droite et gauche pour être plus proche des matrice, ensuite si les borniers sont aussi proches de leur régulateur 5V respectif s’est pour limiter la résistance dans les piste 5V et les effet de résistance dans le plan de masse menant à une masse non uniforme. À droite il y a également le bornier de data out pour les LEDs car c’est la matrice une qui reçois les informations pour les LEDs. Enduite au centre j’ai placer le bornier de la batterie et tout de suite après dans l’encadré jaune la mesure du courant. Si la mesure du courant se fait aussi proche s’est simplement pour simplifier le routage du 12V ensuite. Et finalement il ne restait plus qu’à mettre la partie régulateur 3,3V (encadré bleu) dans l’espace qu’il restait.
13.2.2 | Partie logique
| La seul contrainte pour la partie logique concerne le module wifi (dans l’encadrer rouge) qui, pour fonctionner de manière optimale, doit se trouver au bord du PCB. Le reste des composants (dans l’encadrer gris) a été placé en fonction de la place restante en suivant une logique de base c’est à dire les capacités de découplage le plus proche des composant à découpler etc...

### 13.3 ROUTAGE

Le routage de la partie logique était assez classique, du moins pour toute la partie dans l’encadré gris. En revanche pour le module wifi les contrainte ne s’arrêtait pas à le placer au bord de la carte, le datasheet conseil aussi vivement de retiré tous le cuivre de la couche top directement en dessous du module et de faire une zone sous l’antenne sans cuivre sur aucune des couches :

Consigne du datasheet. | Résultat sur le PCB.

Le routage de la partie puissance lui était un peu plus particulier, il a fallu faire attention à la largeur des pistes.
Vus que le 3,3V est prévu uniquement pour la partie logique, le courant traversant les piste serras relativement faible. Les piste font donc une largeur standard pour des alimentation de 0,5mm.


Rapport final | Page 23 sur 41 | 20-juin-19

En revanche pour la partie 12V et 5V vus que la puissance nécessaire pour alimenter les matrices de LEDs doit passer dans le piste il faut les dimensionner en conséquence :
Voilà ce que ça donne sur le PCB. On peut voir, en particulier pour le 5V, que les piste qui entre et qui sorte du régulateur 5V sont plus petite quelle devrait s’est dû à l’entraxe du régulateur, si les piste était plus large elles seraient trop proche des pad. Pour le 12V la réduction est négligeable mais pour le 5V elle est importante, j’ai donc routé la piste au top et au bot et j’ai fait la piste le plus court possible.

Après avoir tous routé j’ai ajouté un plan de masse au top et au bot avec un stiching.


Rapport final | Page 24 sur 41 | 20-juin-19

### 13.4 MONTAGE ET PROBLÊME

Après avoir reçus le PCB et les composants j’ai vite remarqué qu’il y avait des problème avec certain footprint que j’ai réalisé :
Tout d’abord je me suis trompé sur les dimension de la résistance shunt R5, la résistance que j’ai commandée est du 2512 mais le footprint que j’ai utilisé n’est que du 1206, par chance grâce au via en dessus de la résistance j’ai pu souder la résistance en limitant un maximum l’ajout de résistance indésiré.

Le deuxième footprint qui à poser un problème est celui des condensateur polarisé de 47uF, en plus d’avoir assigné les pin à l’envers, je n’ai pas mis suffisamment de tolérance par rapport aux indications du datasheet ce qui fait qu’ils n’étaient pas faciles du tous à souder, exactement le même problème est survenu pour la bobine. Au finale cette erreur n’impact pas le produit finale mais elle a posé beaucoup de problème lors du montage.

La première chose que j’ai soudé et testé sont les alimentation ce qui m’a très vite permis de remarquer que j’ai également assigné les pin des régulateurs 5V à l’envers. Par chance en avoir testé un à l’envers ne la pas détruit et le dessouder puis le resouder à l’endroit à résolue le problème.

La dernière erreur commise lors du montage concerne le reset du pic qui ne fonctionnais pas avec le bouton. J’ai assez vite remarqué que le problème venait de la diode D2. Pendant la confection du PCB j’ai décidé de prendre la même diode que celle utilisé pour la carte de développement pic 32 de l’ETML-ES parce qu’il y en avait en stock, la diode BAS40. La diode était disponible dans le vault de Altium ce qui m’a épargné la confection du schéma et du footprint, seulement la diode BAS40 qui est dans le vault est une BAS40-06 et on peut voir dans le datasheet que la BAS40 n’a pas la même configuration que la BAS40-06 chose que j’ai remarqué trop tard :

J’ai cependant réussi à corriger cette erreur efficacement en recablent une diode BAS40 pour éviter de perdre du temps avec la commande d’un nouveau composant :

En revanche le footprint le plus sensible que j’ai dû réaliser, celui du module wifi est juste et j’ai réussi à le souder sans difficulté.


Rapport final | Page 25 sur 41 | 20-juin-19

### 14. COMMUNICATION AVEC LES LED

La gestion de la communication des LEDs est un des point les plus important et le premier auquel je me suis attaquée.
Les matrices sont composées chacune de 256 LEDs RGB adressable WS2812B ou de l’équivalant SK6812 pour un total de 512 LEDs. Ces LEDs comporte 4 pins :

Les pins d’alimentation VDD et VSS et le pins de données Din et Dout respectivement data in et data out.

La ou ces LEDs sont particulière par rapport à des LEDs RGB classique c’est la manière dont elles sont commandées. Chacune des LEDs est composer d’un chip qui vas lui-même adapter la tension de chacune des composante de la LED RGB en fonction des donné reçus sur sa pin Din. Une LED a besoin de 24 bit pour être commander, 8 bit par couleur, ce qui donne un total de plus de 16 million de couleurs.

Sur la matrice les LEDs sont simplement placée en séries. Pour les commandée il faut envoyer une tram du nombre totale de LEDs fois 24 bit. Chacune des LEDs vas lire les 24 premier bit puis transmettre le reste de la tram à la suivante, ce qui fait que la tram vas en quelque sort se consommer un peu plus après chaque LEDs.

Les LEDs utilises leurs propre protocole :

Rapport final | Page 26 sur 41 | 20-juin-19

Vu qu’il n’y a pas de transmission d’horloge il faut un moyens de synchroniser les données et un moyens de différencier un 0 de aucune donnée. C’est pour ça que le 0 comme le 1 ont un temps high voltage et un temps low voltage.

Pour générer ces 1 et ces 0 j’ai utilisé le SPI 2 et plus précisément le SDO2 que j’ai placer sur la pin 23 du Pic grâce à Harmony. Si j’ai choisi un SPI pour générer le signale de commande des LEDs s’est parce que s’est facile de générer les 1 et les 0. Il suffit d’utiliser un byte de SPI comme bit du signale, par exemple en envoyant 11000000 sur SDO2 avec le bon baud rate la première LED vas le comprendre comme un 0 et en envoyant 24 bytes d’affiler la première LED vas mettre ses trois couleur à 0.

Maintenant que la théorie est expliquée il faut passer au calculs. La première chose que j’ai fait est de trouver un temps identique pour T0H, T1L et idem pour T1H, T0L maintenant ses temps ne peuvent pas être choisi arbitrairement, il faut qu’il soit dans la tolérance et également qu’ils respectent la règle suivante :
8
T0H +T0L

∗ T0H = nombre rond

Après quelque essais j’ai trouvé Valeurs trouvé qui respecte toutes les conditions. Avec ces valeurs et la formule juste en dessus on peut également trouver le nombre de bits du SPI correspondant pour chacun des temps. T0H et T1L corresponde à 2 bits, T1H et T0L corresponde eux au reste du byte donc 6 bits. Donc en envoyant 11000000 on obtiendra un 0 au LEDs et si on envois 11111100 un 1.

La deuxième chose à réglé est le baud rate du SPI. En sachant que les LEDs travail à 800kHz ça veut dire que le SPI doit envoyer les bytes à 800kHz. On trouve donc facilement le baud rate avec le calcul suivant :

800kHz ∗ 8 = 6,4MHz

Cette configuration fonctionne mais on peut réduire le baud rate du SPI sans perdre en précision. Il est possible de réduire le baud rate de moitié, car les ratio de bits nécessaire pour que les LEDs interprète un 1 ou un 0 peuvent être divisé par deux sans que les délai T0H,T0L,T1H et T1L ne change. Ce changement implique qu’il faut envoyer les donner par paire de bits car avec un byte du SPI on envois désormais deux bits mais vus que les LEDs ont besoin chacune de 24 bits le nombre de bit à envoyer serras toujours paire quelle que soit le nombre de LEDs à commander. En plus de permettre au SPI de travailler moins vite cette solution à un autre avantage qui est celui de réduire le code. Le baud rate du SPI serra donc deux fois plus petit à 3,2MHz à la place de 6,4MHz, et désormais pour un 0 il faudra écrire 1000XXXX et pour un 1 il faudra écrire1110XXXX.

Rapport final | Page 27 sur 41 | 20-juin-19

### 15. CODE

### 15.1 HARMONY

15.1.1 | Pin settings :
| Il y avait plusieurs chose à régler avec Harmony, ici on peut voir la configuration des pins :

Les deux seul pin vraiment importantes sont la pin 8 qui est l’enable des deux régulateur 5V et la pin 23 qui est la pin de commande des LEDs.

15.1.2 | Timer 1 :
| Le reste de la configuration se fait dans les options. Tous d’abord il a fallu un Timer pour cadencer l’application, s’est lui qui vas déterminer la vitesse de défilement du texte :

Ici le Timer Period n’est pas très important car il est tout de suite modifié dans le code mais le Prescaler lui a été choisi de manière que la fréquence du timer ne soit pas trop haute ce qui ferais que le code n’a pas le temps de mettre à jour les matrice qu’il doit déjà les remettre à jour et pas trop faible non plus pour éviter que le texte mette 10 minute pour faire le tour du totem. Après plusieurs test j’ai remarqué que le prescaler idéal été 64 ce qui permet une fréquence du Timer 1 entre :

48000000
64 = 750kHz

Et :

48000000
64 ∗ 65536 = 11,44Hz


Rapport final | Page 28 sur 41 | 20-juin-19

Test du Timer 1, Timer Period = 65535, toggle de la pin RB6 à chaque interruption donc f = 2*f mesuré.

Sur le Screenshot on voit une fréquence de 5,74Hz ce qui fait une interruption à 11,48Hz ce qui est très proche des 11,44Hz calculé.

15.1.3 | SPI
| Le projet contient deux communication SPI mais n’ayant pas eu le temps de m’attaquer sérieusement à la programmation du module wifi je n’ai pas initialisé le SPI servant à la communication avec le module wifi. Vus qu’il ne faut que le SDO2 pour communiquer avec les LEDs la configuration du SPI n’est pas très compliquer :

Le plus important a changé est le Clock/Baud Rate qui a été mis à 3,2MHz.


Rapport final | Page 29 sur 41 | 20-juin-19

### 15.2 LED

L’écriture sur les matrice est faite avec deux fonction. La fonction Led_Set() et la fonction WriteToLED.

La Fonction Led_Set() est très basic, la seul chose qu’elle fait s’est écrire des 0 dans le SPI pendant environ 50us le temps de reset des LEDs. Cette fonction va permettre de dire au LEDs d’afficher ce qu’elles ont reçus.

La fonction WriteToLED elle est un peu plus compliquer, elle s’occupe de prendre un tableau, colorMatrix, d’un nombre de case égale au nombre de LEDs contenant une structure, colorStruct, de trois uint8 par case représentant les trois couleurs RGB de chaque LEDs et de convertir ces valeurs en une tram valide pour les LEDs à envoyer sur le SPI. Ce tableau permet de modifier facilement la couleurs de chacune des LEDs avec des fonctions relativement simple.

La première chose que fait la fonction est de réassigner les cases du tableau, car dans mon code je considère que les LEDs sont router comme ça sur les matrices :

Alors qu’elles sont réellement routées comme ça :

La première configuration permet de grandement simplifier le faite de faire bouger les lettres ou les animations sur la matrice. Dans le code au lieu de réassigner tous le tableau j’ai juste adapté l’index utilisé pour le lire :

Voilà ce que fait cette partie de code, si la colonne sur laquelle pointe i est impaire l’index est adapté, sinon il vaut i.

La deuxième chose que vas faire la fonction est de convertir la valeur 8 bit de chaque couleur de la case pointer par l’index :

On peut voir ici la couleur rouge mais les trois couleur marche exactement de la même manière. La valeur rouge du tableau est testé bit par bit puis selon si c’est un 1 ou un 0 vas être converti en 1110 ou en 1000 puis assigné à la case correspondent au bit d’un tableau de 8 case. Puis vus que l’on envois deux bit par byte de SPI si le bit converti est impair il serra shift de 4 bit en direction du MSB pour simplifier sont addition plus tard.


Rapport final | Page 30 sur 41 | 20-juin-19

La dernière partie mais pas des moindre est celle qui s’occupe de remplir le buffer du SPI :

Cette partie m’a causé beaucoup de problème car bien que le datasheet du pic est la conception du SPI suggère que en cas de non transfère de donner le SDO garde son dernière état réalité le SDO se met à l’état haut ce qui pose de gros problème pour les LEDs. Il faut donc s’assuré que le buffer ne soit jamais plein et encore moins vide. La fonction s’exécute bien assez vite pour que le buffer ne soit jamais vide cependant il se remplit très vite d’où les while qui font attendre le code tant qu’il n’y a pas au moins une place dans le buffer. Cette solution stop le program ce qui n’est pas parfait mais l’écriture se fait quand même suffisamment vite pour ne pas gêner le reste du programme.

### 15.3 MESSAGE

Pour écrire des massages sur les matrices il faut une librairie de caractères. Une fonction qui, une fois appelé, vas retourner un tableau contenant les LEDs à allumer pour faire la lettre voulu. Voilà ce que ça donne dans le code pour la lettre A :


Rapport final | Page 31 sur 41 | 20-juin-19

La fonction qui s’occupe de faire c’est la fonction convertChar() qui avec l’adresse du tableau de 40 case, un caractère de la table ascii et une couleur vas remplir le tableau avec le caractère d’entré converti. Pour l’instant la fonction peut convertir 53 caractère faisant partie de cette liste :

.',-_/*+=:()%°$!?0123456789ABCDEFGHIJKLMNOPQRSTUVWXYZ

À cette liste s’ajoute l’espace qui enfaite est le tableau vide et un damier si le caractère voulu ne correspond pas à la liste. Il est possible de mettre à jour cette « librairie » de caractère avec d’autre caractère mais sans trop la modifier il faut que les caractère respectent les règle suivantes : ils doivent faire partie de la table ascii non-étendue, ils ne doivent pas une foi converti prendre plus de place sur la matrice que 5x8 LEDs et ça ne peut pas être le caractère ‘\0’.

Une fois la librairie de caractère faite il faut afficher s’est caractère sur les matrices, s’est ici que la fonction Text() entre en jeu. Cette fonction fonctionne de la manière suivante : Elle prend le premier caractère de la chaine qu’il lui a été passé en paramètre et le convertit avec la fonction CaracLib() ; ensuite elle décale tous le tableau matixColor d’une colonne vers la gauche ; puis elle met à jour la dernière colonne du tableau matrixColor avec la première colonne du tableau de conversion du caractère.

La fonction va également analyser la taille du message et s’il est suffisamment petit pour être afficher en entier sur les matrices il tournera à l’infinie Contrairement à une phrase un mot suffisamment court de mois de X caractère est lisible tout autour du totem. Si le message est trop grand la première colonne s’allumeras en blanc pour marquer la différence entre le début du message et la fin car là où le début et la fin du message se rencontre si-il n’y a pas d’indication les lettres donne l’impression de se mélanger et le résultat est très perturbant.

La fonction Text() a besoin en entré d’une chaine de caractère contenant à la fin le caractère ‘\0’ sinon la fonction ne sait pas où se trouve la fin du message et il risque d’y avoir des overflow avec les index de tableau.

Rapport final | Page 32 sur 41 | 20-juin-19

### 15.4 AUTRES FONCTIONS

Mon code est composé d’autres fonction un peu plus secondaire que je vais un peu moins détailler que les précédentes mais s’est quand même intéressent de s’arrêter dessus.

Dans le fichier Anim.c en plus de la fonction Text() j’ai fait une fonction Nyan() et une fonction Battery(). Les deux fonctions marchent de manière assez similaire.

La première, Nyan(), est une animation de la célèbre vidéo Nyancat, je l’ai principalement réalisé pour faire une sorte de démonstration de ce que l’on peut faire avec les matrices. En plus de la fonction Nyan() je voulais implémenter une fonction PacMan() mais le manque de temps m’en a empêché.

La fonction Battery() elle affiche des batterie toute autour du totem qui vont afficher le niveau de l’alimentation. Cette fonction est surtout là pour montrer que la lecture de la tension fonctionne il manque toute la calibration, pour l’instant les batteries afficher son plein si la tension vaut 14V et diminue de manière linéaire jusqu’à 10V pour afficher des batteries vides.

J’ai réalisé une autre fonction qui a besoin de réglage c’est la fonction AutoBrightness() qui comme son nom l’indique règle la luminosité des matrices en fonction de la lumière ambiante, cette fonction marche étonnamment bien mais elle a besoin d’être calibrer. Il faudra peut-être même changer la résistance R11 sur le PCB pour modifier la sensibilité du capteur.

Les fonction d’initialisation et de lecture des ADCs ont été copier des anciens TP et exercice réaliser autour des ADCs. Presque aucune modifications n’a été requise.

Les dernières fonctions sont des fonctions plutôt utilitaire comme la fonction FullColor() qui permet de mettre la même couleur dans tous le tableau matrixColor. Cette fonction est utilisée principalement pour remettre tous le tableau dans un état LEDs éteinte. La fonction RainbowPick() elle est une fonction qui permet de return une couleur, au format colorStruct, faisant partie du spectre de l’arc-en-ciel. Cette fonction est très utile pour faire une boucle couvrant toutes les couleurs ou choisir une couleur en étant sûr qu’elle soit jolie et à la même luminosité.

### 15.5 PROBLÈME ET MODULE WIFI

En réalisant ce programme j’ai rencontré plusieurs problème, certains relativement classique comme des oubli d’initialisation de variable etc. et d’autre plus embêtent et qui mérite qu’on si attarde. Le premier était celui concernant la communication des LEDs et le SPI que j’ai déjà détaillé en dessus. Le deuxième gros problème que j’ai rencontré lui concerne l’écriture des message sur la matrice. Pendant l’implémentation de la fonction Text() j’ai fait une erreur qui faisait que l’index du tableau matrixColor réalisait une formule pouvant donner un résultat négatif. Voilà à quoi ressemblais le problème en simplifier dans le code :

L’ennui s’est que MplabX compilait le code sans erreur est l’écrivait dans la mémoire mais il ne fonctionnait pas du tout. En plus de compiler sans erreur en mode debug le code ne plantais que plus tard à un endroit qui n’avait aucun problème. J’ai assez vite remarqué que certaine variable qui ne devait pas être modifié prenait de valeurs absolument absurde pour mon code. Et j’ai fini par remarquer qu’un tableau avait parfois un index négatif mais qu’au lieux de planter écrivais la valeur que je voulais lui attribuer à l’adresse de la case en considérant l’index comme non signé et les adresses en question été par hasard celle d’autre variable qui elles, ont causé des problème juste en dessous car elle n’était pas réassignée. Bien que ce problème m’ait fait perdre deux jours j’ai eu de la chance car les variable modifier aurait pu être utile bien plus loin dans le code rendant la détection du problème encore plus compliquer.

Concernant le module wifi qui était une grosse partie du cahier des charges, j’ai essayé sans succès à le faire fonctionner, d’un point de vue hardware toute à l’air correcte s’est du côté software qu’il y a des problèmes. Pour commencer si j’ai choisi le module ATWILC1000 s’est parce que monsieur Castoldi ma conseiller d’utiliser le module MRF24Wn0MA seulement sur le site de Microchip il conseil de prendre

Rapport final | Page 33 sur 41 | 20-juin-19

le module ATWILC1000 car l’autre est devenus obsolète. En faisant des recherches j’ai remarqué que Microchip fournissait un exemple spécifique pour le ATWILC1000 ce qui aurait dû rendre l’utilisation du module très similaire au dernier TP de MINF sur la communication Ethernet.

Dans un premier temps j’ai essayé d’adapter l’exemple à mon projet. J’ai très vite remarqué que le code était grandement basé sur FreeRTOS après avoir analyser le code j’ai demandé de l’aide à monsieur Bovey qui en analysant le code à pus me renseigner sur le fonctionnement de l’exemple. Tout d’abord l’exemple est prévu pour fonctionner avec une carte de développement faite par Microchip grâce à l’laquelle le module est programmer par Uart.

C’est ici qu’est la première difficulté, il faut trouver les commande SPI pour programmer le module que je n’ai pas réussi à trouver. C’est à ce stade que j’ai abandonné faute de temps.

Pendant mes recherche j’ai eu pas mal de peine à trouver des gens ayant fait un projet fonctionnel sur le module, le forum le plus constructif que j’ai trouvé est celui-ci :

https://www.avrfreaks.net/forum/atwilc1000-sd-evaluation-code

Ici la personne essaye comme moi d’utiliser le module via SPI sans succès et conseille vivement d’utiliser un autre module comme le ATWINC1500. Je regrette de ne pas avoir pris le module que l’on m’a conseillé.

### 16. MECANIQUE

Après avoir fait le PCB avec Altium j’ai commencé le design du boitier. J’ai donc suivi l’idée développer dans la phase de pré-étude qui était de faire deux disque qui prennent en sandwich les matrices laissant de la place au milieu pour monter le PCB. J’ai donc développé les deux disque en 3D sur Solid Works l’utilisation du programme était assez intuitive, je n’ai pas rencontré de problème particulier. Voilà le résultat :

Disque du bas. | Disque du haut.

Les deux disque sont presque identique, la seul différence entre les deux est les quatre trous de Montage du PCB et le gros trous au centre qui sert à faire passer les câbles d’alimentation. Sur les disques on peut apercevoir deux rainure au tour, la première sert à tenir les matrice correctement en rond el la deuxième sert à mettre un plexiglass souple pour d’une part essayer de rendre le Totem imperméable et de pouvoir dissipé un peu les LEDs en ponssant le plexiglass ce qui rend également les lettres et animation plus lisible. Finalement les quatre trous qu’il y a sur les deux disques servent à maintenir les disques avec des entretoise.


Rapport final | Page 34 sur 41 | 20-juin-19

Après avoir coté les disques j’ai transmis les plan au secteur mécanique de l’ETML qui on accepter de les réaliser pour moi sur une CNC. Une fois les deux disques reçus j’ai remarqué que malheureusement l’étudiant qui s’est occuper de les usiner à lu les dessins en miroir ce qui cause les trous de fixation du PCB à ne pas être aligner, seulement deux trous correspondes à la fois cette erreur n’est pas spécialement gênante, les deux tous aligner plus le support qu’offre les entretoises suffisent à maintenir le PCB. En vérifiant d’où venait l’erreur j’ai également remarqué que même si le dessin avait été interpréter correctement seul trois trous aurait été aligné car j’ai mal placé un des trous :

Cette côte aurait dû être à 15 au lieu de 25.

### 16.1 MONTAGE

L’or du design du boitier le montage me paraissait simple et évident mais finalement il s’avère bien plus compliquer que prévu.

1. Placé les entretoises et monté le PCB sur le disque du bas.

Il est important que les longues entretoises soient plus courtes que la hauteur des matrices mais plus longue que les matrices lorsqu’elles sont placé dans les disque pour éviter de les écraser. Ici on peut voir un élégant empilement d’entretoises forment quatre longues entretoises de 78mm de haut chacune.

Rapport final | Page 35 sur 41 | 20-juin-19
2. Placer les matrices et mettre les câbles dans les bon borniers.

Pour cette étape brancher les câbles d’alimentations avant de placer les matrices est plus simple. Ensuite il faut faire attention de brancher les deux matrices sur leurs alimentations en suivants les légendes sur le PCB.

3. La dernière étape et de très loin la plus compliquer consiste à mettre le plexiglass dans la deuxième rainure, de mettre le disque du haut et de le vissé dans les entretoise.

C’est ici qu’on peut remarquer les premier défaut du design, il est très dur de faire rentrer les matrices et le plexiglass dans leur rainure. Il est vraiment important d’être sûr d’avoir placé les matrices correctement dans la rainure avant de visser les deux disques ensemble, car si elles ne sont pas correctement mises elles vont se plier et il sera encore plus dur de les placer correctement par la suite.

Une fois complétement monté et en état de marche on peut remarquer l’autre défaut du boitier. À hauteur d’œil la visibilité des matrices est parfaite mais si le Totem est plus haut ou plus bas certaine rangée de LEDs deviennent cacher par les disques.


Rapport final | Page 36 sur 41 | 20-juin-19

### 17. TESTS ET MESURES

### 17.1 ALIMENTATION

Mon PCB est composé de trois régulateurs, deux de 5V servant d’alimentation pour les matrices et un de 3,3V pour alimenter tout le reste.

D’abords la tension d’alimentation qui est régler
à 12V

Ensuite le régulateur de la matrice 1.

Et le régulateur de la matrice 2.

Finalement le régulateur 3,3V.

On peut voir avec ces mesure que le dimensionnement des alimentations est juste et que les tension sont celle calculé.


Rapport final | Page 37 sur 41 | 20-juin-19

### 17.2 SPI

En envoyant en boucle le byte suivant 10101010 on peut mesurer le baud rate du SPI exactement de la même manière que pour le timer c’est-à-dire à la moitié de sa fréquence réel :

On voit que le SPI atteint 1,5MHz ce qui fois deux fait 3MHz ce qui est assez proche des 3,2MHz.

Si maintenant on allume la première LED en rouge à la luminosité maximum, la tram du SPI devrais ressembler à ça :

8 bits à 0 vert | 8 bits à 1 rouge | 8 bits à 0 bleu
10001000 10001000 10001000 10001000 11101110 11101110 11101110 11101110 10001000 10001000 10001000 10001000

Voilà ce qui est mesuré à l’entrée des matrices :

On voit effectivement la même tram ainsi que les donné pour la suite des LEDs qui sont toutes éteinte c’est donc uniquement des 0 ou des 1000 pour le SPI. Sur le Totem la première LED s’est bien allumé en rouge


Rapport final | Page 38 sur 41 | 20-juin-19

Avec cette tram on peut directement vérifier les temps calculer avant et vérifier s’ils correspondent :

Les temps sont respectés, on est bien dans les tolérance du datasheet, il y à certes une déviation par rapport au calcule mais les valeurs sont encore dans les tolérances et la communication fonctionne. Cette différence avec les valeurs calculer viens du faite que le baud rate du SPI n’est pas pile 3,2MHz mais 3MHz.

### 17.3 DURÉE DE FONCTION

Le code varie selon la taille du message à envoyer ou simplement si le totem affiche un message ou un animation il n’est donc pas facile ni vraiment utile de mesurer la durée du code, cependant il y a une fonction qui prend beaucoup de temps, qui est bloquante et qui prend toujours le même temps quel que soit le reste du code, c’est la fonction d’écriture sur les LEDs WriteToLED().

En faisant passé de l’état bas à l’état haut la pin RB6 juste avant l’appelle de la fonction et en faisant l’inverse juste après on auras une bonne idée de la durée de la fonction :

La fonction dure 17,86ms cette information peut paraitre un peu inutile elle nous permet déjà de réaliser le temps qu’il faut pour mettre à jour les matrices et en plus grâce à ce temps on sait que si le Timer 1 crée une interruption plus souvent que toute les 17,86ms le texte n’ira pas plus vite. En sachant ça on peut calculer la valeur minimum du Timer 1 :

17,86 ∗ 10⁻³
∗ 48000000
64 | = 13395

La valeur sous laquelle il ne faut pas aller pour le Timer Period est 13395.

des LEDs éteintes.; Texte*; Nyan; Full rouge; Full Vert; Full bleu; Full blanc

Rapport final | Page 39 sur 41 | 20-juin-19

### 17.4 CONSOMMATION

Pour mesurer la consommation j’ai fait un tableau sur Excel, toutes les valeur sont en mA, le courant a été mesuré juste avant le PCB avec une tension d’entrée de 12V :

Dans ce tableau on peut voir que j’ai tester plusieurs mode à plusieurs luminosité. Pour commencer on peut voir que quand les LEDs sont éteinte mais alimenté (LED Off) on consomme quand même 344mA ce qui n’est pas négligeable, en mesurant le courant mais cette fois en désactivant les régulateurs 5V on voit que l’on consomme plus que 27mA on peut donc en conclure que rien que d’alimenter les deux matrices par les régulateurs 5V consomme 317mA.

Mise à part ça, on peut voir que quand les matrices sont allumées d’une des trois couleurs RGB (Full rouge, Full rouge, Full bleu) on obtient exactement la même consommation pour la même luminosité ce qui prouve que les LEDs sont bien calibré à l’intérieur. Les cases en rouge indiquent que le courant est supérieur à 3A la limite de l’alimentation. L’alimentation ne peut pas fournir plus de 3A ce qui peut paraitre être un inconvenant, avec une tel consommation les matrices chauffent considérablement et d’après Adafruits qui sont les fabricants les matrices peuvent allez jusqu’à la destruction.

Ce tableau est pratique pour estimer l’autonomie du Totem en fonction du mode, de la luminosité et de la batterie. Vus que la batterie n’a pas été commander et quelle ne serras surement pas la même que celle prévu ça n’est pas très utile d’essayer d’estimer l’autonomie mais on peut déjà voir si la consommation est linéaire en fonction de la luminosité. Pour faire le graph j’ai soustrait la consommation

Ce graph montre que la consommation des matrices est parfaitement linéaire en fonction de la luminosité. Ce qui peut me permettre de compléter le tableau en extrapolant les valeurs :

Après avoir extrapoler ces valeurs on voit qu’en théorie le Totem peut atteindre une consommation de plus de 7,6A a 12V si toutes les LEDs son allumer en blanc ce qui fait environ 9A par régulateur 5V à fournir.

Rapport final | Page 40 sur 41 | 20-juin-19

### 18. STADE D’AVANCEMENT

La base du Totem fonctionne, il affiche un message sur les matrices. La grosse partie manquante du projet est, évidemment, la communication par wifi mais mise à part ça à condition d’avoir un pc et un programmeur le projet respect le cahier des charge, il est capable d’afficher un message, des animation, le niveau de la batterie, changer sa luminosité en fonction de la lumière ambiante, etc… En plus de la partie wifi toute la partie batterie et panneau solaire a été mise de coter dû à plusieurs chose notamment le prix des composant et le temps restreint. La partie panneau solaire et batterie n’est pas très compliquer commander les composant et les brancher au projet devrais suffire.

Si ce projet est repris je conseil vivement de changer le module wifi.

### 19. CONCLUSION

En conclusion je suis content de mon travail bien que déçus de ne pas avoir réussi à faire fonctionner le module wifi. Le projet a atteint un stade qui le rend selon moi fonctionnelle et qui respecte les points essentielle du cahier des charge. Le totem est capable d’afficher un message sur les matrices, de mesuré sa tension d’alimentation, d’adapter la luminosité des LEDs en fonction de la lumière ambiante et d’afficher une animation.

J’ai acquis beaucoup de nouvelle compétence grâce à ce projet. J’ai pu voir comment fonctionne la communication des LEDs à communication série et réaliser des fonction capable de communiquer avec les LEDs avec succès, mais là où j’ai appris le plus s’est au niveau de la gestion de sont temps et de la gestion d’un projet. J’ai très mal géré mon temp, j’ai été très optimiste lors de la pré-étude sur le temps que prendrais certaine chose et j’ai oublier pas mal de chose, j’ai oublié de prendre en compte les délai de commande des composant et du PCB ce qui m’a un peu retardé pour le code, je n’ai pas non plus pensé au temps que je passerais à régler des erreurs comme pour le module wifi. Ce manque d’organisation à fait que je n’ai pas réaliser que la fin du projet approchait à grand pas ce qui a grandement réduit le temps nécessaire pour travailler sur le rapport.

Bien qu’ayant fait beaucoup d’erreurs sur l’organisation et la gestion du temps je suis sûr que je réaliserais mais future projet bien mieux grâce à celui-ci.

Je tiens également à m’excuser pour le nombre de fautes que le lecteurs de ce rapport à dû subir malheureusement dû à la mauvaise gestion de mon temps je n’ai pas eu le temps de faire corriger mon rapport ma dysorthographie se reflète donc pleinement au travers de mon rapport.

Nicolas Fürst

Rapport final | Page 41 sur 41 | 20-juin-19

### 20. ANNEXE

Annexe 1 : Schéma Alim.

Annexe 2 : Schéma Pic.

Annexe 3 : Liste des composant.

Annexe 4 : Planning réel.

Annexe 5 : Plan mécanique, disque du bas.

Annexe 6 : Plan mécanique, disque du haut.

Autres annexe : Code.

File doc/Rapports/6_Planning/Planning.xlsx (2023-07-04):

 |  |  |  |  |  |  |  |  | Planning
No semaine projet | 1 | 2 | 3 | 4 | 5 | 6 | 7 | 8 | 9 | 10 | 11 | 12 | 13 | 14 | 15 | 16 | 17 | 18 | 19 | 20 | 21 | 22 | 23 | 24 | 25 | 26 | 27 | 28 | 29 | 30 | 31 | 32 | 33
No semaine | 47 | 48 | 49 | 50 | 51 | 52 | 1 | 2 | 3 | 4 | 5 | 6 | 7 | 8 | 9 | 10 | 11 | 12 | 13 | 14 | 15 | 16 | 17 | 18 | 19 | 20 | 21 | 22 | 23 | 24 | 25 | 26 | 27
Tâches
Préparation des documents / Organisation
Cahier des charges
Pré-étude
Choix des composants
Design / Schémas éléctriques
Routage des PCBs
Commande des composants / PCBs
Montage du PCB
Design Mécanique
Softwares
Tests et mesures
Rédaction du rapport

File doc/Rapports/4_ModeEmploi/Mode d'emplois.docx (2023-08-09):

Mode d’Emplois

École supérieure

Électronique

PROJ

Salle R110

# Totem Lumineux

Réalisé par :

Nicolas Fürst

Date :

20 Juin 2019

# 1. Montage

L’or du design du boitier le montage me paraissait simple et évident mais finalement il s’avère bien plus compliquer que prévu.


1. Placé les entretoises et monté le PCB sur le disque du bas.

Il est important que les longues entretoises soient plus courtes que la hauteur des matrices mais plus longue que les matrices lorsqu’elles sont placé dans les disque pour éviter de les écraser. Ici on peut voir un élégant empilement d’entretoises forment quatre longues entretoises de 78mm de haut chacune.


2. Placer les matrices et mettre les câbles dans les bon borniers.

Pour cette étape brancher les câbles d’alimentations avant de placer les matrices est plus simple. Ensuite il faut faire attention de brancher les deux matrices sur leurs alimentations en suivants les légendes sur le PCB.

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

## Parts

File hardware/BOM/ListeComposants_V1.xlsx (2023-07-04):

Comment | Description | Designator | Fournisseur | Reference | LibRef | Quantity | Price
47uF | Conductive Polymer Hybrid Aluminum Electrolytic Capacitor, 100 uF, +/- 20%, 50 V, -55 to 105 degC, 2-Pin SMD (G), RoHS, Tape and Reel | C1, C2, C6, C7 | Mouser | 667-EEE-FT1E470AR | CMP-2000-06221-1 | 4 | 0.52 | 2.08
39nF |  | C3, C4 | Digi-key | 311-1106-1-ND | Capa | 2 | 0.1 | 0.2
10nF |  | C5 | Stock |  | Capa | 1 | 0 | 0
100n |  | C8, C11, C20, C21, C22, C24, C25, C27, C28, C23 | Stock |  | Capa | 10 | 0 | 0
CAP 47uF 10V 1206(3216) | CAP 47uF 10V ±20% 1206 (3216 Metric) Thickness 1.9mm SMD | C9, C10, C12, C13, C14, C15, C16, C17, C18, C19 | Stock |  | CMP-1037-05002-1 | 10 | 0 | 0
10uF |  | C26 | Stock |  | Capa | 1 | 0 | 0
SK32 | Shotky diod | D1 | Mouser | 821-SK320BR4G | SK32 | 1 | 0.71 | 0.71
BAS40-06LT1G | Common Anode Schottky Barrier Diodes, 3-Pin SOT-23, Pb-Free, Tape and Reel | D2 | Stock |  | CMP-1055-00547-1 | 1 | 0 | 0
691211720002 | Serie 211 - 5.00 mm 45deg Entry Modular with Rising Cage Clamp - 15.50 mm Height WR-TBL, 2 pin | J1, J2, J3, J4 | Digi-Key | 732-2034-ND | CMP-1502-02524-1 | 4 | 1.11 | 4.44
61302021121 | THT Vertical Pin Header WR-PHD, Pitch 2.54 mm, Dual Row, 20 pins | J5 | Stock |  | CMP-1502-01104-1 | 1 | 0 | 0
691250910002 | Serie 2509 - 9.52 mm Horizontal Entry Modular with Rising Cage Clamp WR-TBL, 2 pin | J6 | Digi-Key | 277-5951-ND | CMP-1502-02750-1 | 1 | 1.66 | 1.66
691411710002B | Serie 411 B - 5.00mm Screwless Horizontal Entry-2.0mm2 Wires WR-TBL, 2 pin | J7 | Würth | 691411710002B | CMP-1502-03026-1 | 1 | 0 | 0
DO3308P-684 |  | L1 | Farnell | 2457510 | DO3308P-684 | 1 | 3.18 | 3.18
61300511121 | THT Vertical Pin Header WR-PHD, Pitch 2.54 mm, Single Row, 5 pins | P1 | Stock |  | CMP-1502-01068-1 | 1 | 0 | 0
47R |  | R1, R2 | Stock |  | Resistor | 2 | 0 | 0
270R |  | R3, R4 | Stock |  | Resistor | 2 | 0 | 0
2mOhm |  | R5 | Mouser | 755-PSR100KTQFJ2L00 | Resistor | 1 | 1.41 | 1.41
 |  | R6, R8, R9 | Stock |  | Resistor | 3 | 0 | 0
82k |  | R7 | Stock |  | Resistor | 1 | 0 | 0
18k |  | R10 | Stock |  | Resistor | 1 | 0 | 0
300R |  | R11 | Stock |  | Resistor | 1 | 0 | 0
0R |  | R12 | Stock |  | Resistor | 1 | 0 | 0
1M |  | R13 | Stock |  | Resistor | 1 | 0 | 0
430181038816 | WS-TASV SMD Tact Switch 4.5X4.5 mm | SW1 | Stock |  | CMP-1454-00001-1 | 1 | 0 | 0
DC-DC _12to5V |  | U1, U2 | Mouser | 894-NQR010A0X4Z | DC-DC _12to5V | 2 | 8.2 | 16.4
LM2674M-3.3 | SIMPLE SWITCHER® Power Converter High Efficiency 500mA Step-Down Voltage Regulator, 8-pin Narrow SOIC | U3 | Digi-Key | LM2674MX-3.3/NOPBCT-ND | CMP-0069-00679-2 | 1 | 3.31 | 3.31
INA214AIDCKT | Voltage Output, High / Low-Side Measurement, Bi-Directional Zero-Drift Series, Current Shunt Monitor, 2.7 to 26 V, -40 to 125 degC, 6-Pin SOT-23 (DCK6), Green (RoHS & no Sb/Br), Tape and Reel | U4 | Mouser | 595-INA210CQDCKRQ1 | CMP-2000-06456-1 | 1 | 1.65 | 1.65
TEPT4400 |  | U5 | Mouser | 782-TEPT4400 | TEPT4400 | 1 | 0.66 | 0.66
PIC32MX130F256D |  | U6 | Digi-key | PIC32MX130F256D-I/PT-ND | PIC32MX130F256D | 1 | 3.13 | 3.13
ATWILC1000 |  | U7 | Digi-Key | ATWILC1000-MR110PB-TCT-ND | ATWILC1000 | 1 | 7.44 | 7.44
Matrice | Matrice souple 8x32 LEDs |  | Mouser | 485-2294 |  | 2 | 103.49 | 206.98
PCB |  |  | Eurocircuit |  |  | 1 | 40 | 40
Total price [chf] = |  |  |  |  |  |  | 293.25

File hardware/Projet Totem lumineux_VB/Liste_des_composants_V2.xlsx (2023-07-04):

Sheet: 1814_TotemLumineux
Comment | Description | Designator | Fournisseur | Reference | LibRef | Quantity | Price
47uF | Conductive Polymer Hybrid Aluminum Electrolytic Capacitor, 100 uF, +/- 20%, 50 V, -55 to 105 degC, 2-Pin SMD (G), RoHS, Tape and Reel | C1, C2, C6, C7 | Mouser | 667-EEE-FT1E470AR | CMP-2000-06221-1 | 4 | 0.52 | 2.08
39nF |  | C3, C4 | Digi-key | 311-1106-1-ND | Capa | 2 | 0.1 | 0.2
10nF |  | C5 | Stock |  | Capa | 1 | 0 | 0
100n |  | C8, C11, C20, C21, C22, C24, C25, C27, C28, C23 | Stock |  | Capa | 10 | 0 | 0
CAP 47uF 10V 1206(3216) | CAP 47uF 10V ±20% 1206 (3216 Metric) Thickness 1.9mm SMD | C9, C10, C12, C13, C14, C15, C16, C17, C18, C19 | Stock |  | CMP-1037-05002-1 | 10 | 0 | 0
10uF |  | C26 | Stock |  | Capa | 1 | 0 | 0
SK32 | Shotky diod | D1 | Mouser | 821-SK320BR4G | SK32 | 1 | 0.71 | 0.71
BAS40-06LT1G | Common Anode Schottky Barrier Diodes, 3-Pin SOT-23, Pb-Free, Tape and Reel | D2 | Stock |  | CMP-1055-00547-1 | 1 | 0 | 0
691211720002 | Serie 211 - 5.00 mm 45deg Entry Modular with Rising Cage Clamp - 15.50 mm Height WR-TBL, 2 pin | J1, J2, J3, J4 | Digi-Key | 732-2034-ND | CMP-1502-02524-1 | 4 | 1.11 | 4.44
61302021121 | THT Vertical Pin Header WR-PHD, Pitch 2.54 mm, Dual Row, 20 pins | J5 | Stock |  | CMP-1502-01104-1 | 1 | 0 | 0
691250910002 | Serie 2509 - 9.52 mm Horizontal Entry Modular with Rising Cage Clamp WR-TBL, 2 pin | J6 | Digi-Key | 277-5951-ND | CMP-1502-02750-1 | 1 | 1.66 | 1.66
691411710002B | Serie 411 B - 5.00mm Screwless Horizontal Entry-2.0mm2 Wires WR-TBL, 2 pin | J7 | Würth | 691411710002B | CMP-1502-03026-1 | 1 | 0 | 0
DO3308P-684 |  | L1 | Farnell | 2457510 | DO3308P-684 | 1 | 3.18 | 3.18
61300511121 | THT Vertical Pin Header WR-PHD, Pitch 2.54 mm, Single Row, 5 pins | P1 | Stock |  | CMP-1502-01068-1 | 1 | 0 | 0
47R |  | R1, R2 | Stock |  | Resistor | 2 | 0 | 0
270R |  | R3, R4 | Stock |  | Resistor | 2 | 0 | 0
2mOhm |  | R5 | Mouser | 755-PSR100KTQFJ2L00 | Resistor | 1 | 1.41 | 1.41
 |  | R6, R8, R9 | Stock |  | Resistor | 3 | 0 | 0
82k |  | R7 | Stock |  | Resistor | 1 | 0 | 0
18k |  | R10 | Stock |  | Resistor | 1 | 0 | 0
300R |  | R11 | Stock |  | Resistor | 1 | 0 | 0
0R |  | R12 | Stock |  | Resistor | 1 | 0 | 0
1M |  | R13 | Stock |  | Resistor | 1 | 0 | 0
430181038816 | WS-TASV SMD Tact Switch 4.5X4.5 mm | SW1 | Stock |  | CMP-1454-00001-1 | 1 | 0 | 0
DC-DC _12to5V |  | U1, U2 | Mouser | 894-NQR010A0X4Z | DC-DC _12to5V | 2 | 8.2 | 16.4
LM2674M-3.3 | SIMPLE SWITCHER® Power Converter High Efficiency 500mA Step-Down Voltage Regulator, 8-pin Narrow SOIC | U3 | Digi-Key | LM2674MX-3.3/NOPBCT-ND | CMP-0069-00679-2 | 1 | 3.31 | 3.31
INA214AIDCKT | Voltage Output, High / Low-Side Measurement, Bi-Directional Zero-Drift Series, Current Shunt Monitor, 2.7 to 26 V, -40 to 125 degC, 6-Pin SOT-23 (DCK6), Green (RoHS & no Sb/Br), Tape and Reel | U4 | Mouser | 595-INA210CQDCKRQ1 | CMP-2000-06456-1 | 1 | 1.65 | 1.65
TEPT4400 |  | U5 | Mouser | 782-TEPT4400 | TEPT4400 | 1 | 0.66 | 0.66
PIC32MX130F256D |  | U6 | Digi-key | PIC32MX130F256D-I/PT-ND | PIC32MX130F256D | 1 | 3.13 | 3.13
ATWILC1000 |  | U7 | Digi-Key | ATWILC1000-MR110PB-TCT-ND | ATWILC1000 | 1 | 7.44 | 7.44
Matrice | Matrice souple 8x32 LEDs |  | Mouser | 485-2294 |  | 2 | 103.49 | 206.98
PCB |  |  | Eurocircuit |  |  | 1 | 40 | 40
Total price [chf] = |  |  |  |  |  |  | 293.25

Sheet: Nouveaux composants
Bloc | Designateur | Description | Valeur | Boitier | Fabricant | Fournisseur | Références |  | Quantité | Prix unitaire [CHF] | Disponible en stock ? | Prix total [CHF] | Datasheet
 |  |  |  |  |  |  | Fabricant | Fournisseur
Alimentation +5V |  | DC/DC +12V/+5V | - | Custom | Murata Power Solutions Inc. | Digi-key | OKL2-T/20-W12N2-C | 811-2961-1-ND | 1 | 12.38 | Non | 12.38 | https://www.murata.com/products/productdata/8807038353438/okl2-t20-w12.pdf?1583754815000
 |  | Rtrim pour le DC/DC 5V | 1,6 [kΩ] | 0805 (2012 métrique) | YAGEO | Digi-key | RT0805DRE071K6L | 311-2809-1-ND | 1 | 0.12 | Non | 0.12 | https://www.yageo.com/upload/media/product/productsearch/datasheet/rchip/PYu-RT_1-to-0.01_RoHS_L_12.pdf
 |  | Fusible soudé d'entrée 12V | 25 [A] | 1206 (3216 métrique) | Bel Fuse Inc. | Digi-key | 0685H9250-01 | 507-1946-1-ND | 1 | 0.28 | Non | 0.28 | https://belfuse.com/resources/datasheets/circuitprotection/ds-cp-c1h-series.pdf
 |  | Capacité d'entrée 12V + Capacité de sortie 3,3V | 22 [µF] | 0805 (2012 métrique) | Murata Electronics | Digi-key | GRM21BR61E226ME44K | 490-14661-1-ND | 3 | 0.42 | Non | 1.26 | https://www.digikey.ch/fr/products/detail/murata-electronics/GRM21BR61E226ME44K/4905534
Alimentation +3,3V |  | DC/DC +5V/+3,3V | - | Custom | Mornsun America, LLC | Digi-key | K7803JT-500R3-LB | 2725-K7803JT-500R3-LBCT-ND | 1 | 0.85 | Non | 0.85 | https://www.mornsun-power.com/html/pdf/K7803JT-500R3-LB.html
 |  | Capacité d'entrée 5V | 10 [µF] | 0805 (2012 métrique) | Murata Electronics | Digi-key | GRM21BR61H106KE43L | 490-18663-1-ND | 1 | 0.35 | Non | 0.35 | https://search.murata.co.jp/Ceramy/image/img/A01X/G101/ENG/GRM21BR61H106KE43-01A.pdf
Total [CHF] : |  |  |  |  |  |  |  |  |  |  |  | 15.24

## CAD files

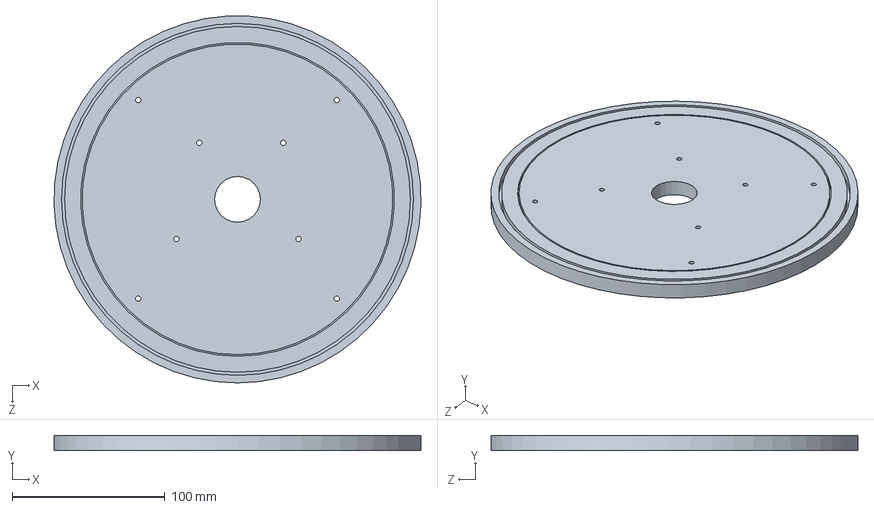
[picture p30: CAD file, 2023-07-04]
mecanique/Version A/Design_Solidworks/Totem_botom.SLDPRT
240.4 x 10.0 x 240.3 mm

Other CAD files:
mecanique/Version A/Design_Solidworks/Totem_top.SLDPRT
mecanique/Version A/Design_Solidworks/Totem_botom.SLDDRW
mecanique/Version A/Design_Solidworks/Totem_top.SLDDRW

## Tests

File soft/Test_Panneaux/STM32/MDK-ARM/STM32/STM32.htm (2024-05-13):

# Static Call Graph for image STM32\STM32.axf

#<CALLGRAPH># ARM Linker, 5060960: Last Updated: Sat May 11 20:56:07 2024

### Maximum Stack Usage = 200 bytes + Unknown(Cycles, Untraceable Function Pointers)

### Call chain for Maximum Stack Depth:

main ⇒ SystemClock_Config ⇒ HAL_RCC_ClockConfig ⇒ HAL_RCC_GetSysClockFreq ⇒ __aeabi_uldivmod ⇒ __aeabi_llsl

### Mutually Recursive functions

- ADC1_COMP_IRQHandler ⇒ ADC1_COMP_IRQHandler

### Function Pointers

- ADC1_COMP_IRQHandler from startup_stm32f051x8.o(.text) referenced from startup_stm32f051x8.o(RESET)
- CEC_IRQHandler from startup_stm32f051x8.o(.text) referenced from startup_stm32f051x8.o(RESET)
- DMA1_Channel1_IRQHandler from startup_stm32f051x8.o(.text) referenced from startup_stm32f051x8.o(RESET)
- DMA1_Channel2_3_IRQHandler from startup_stm32f051x8.o(.text) referenced from startup_stm32f051x8.o(RESET)
- DMA1_Channel4_5_IRQHandler from startup_stm32f051x8.o(.text) referenced from startup_stm32f051x8.o(RESET)
- EXTI0_1_IRQHandler from startup_stm32f051x8.o(.text) referenced from startup_stm32f051x8.o(RESET)
- EXTI2_3_IRQHandler from startup_stm32f051x8.o(.text) referenced from startup_stm32f051x8.o(RESET)
- EXTI4_15_IRQHandler from startup_stm32f051x8.o(.text) referenced from startup_stm32f051x8.o(RESET)
- FLASH_IRQHandler from startup_stm32f051x8.o(.text) referenced from startup_stm32f051x8.o(RESET)
- HardFault_Handler from stm32f0xx_it.o(i.HardFault_Handler) referenced from startup_stm32f051x8.o(RESET)
- I2C1_IRQHandler from startup_stm32f051x8.o(.text) referenced from startup_stm32f051x8.o(RESET)
- I2C2_IRQHandler from startup_stm32f051x8.o(.text) referenced from startup_stm32f051x8.o(RESET)
- NMI_Handler from stm32f0xx_it.o(i.NMI_Handler) referenced from startup_stm32f051x8.o(RESET)
- PVD_IRQHandler from startup_stm32f051x8.o(.text) referenced from startup_stm32f051x8.o(RESET)
- PendSV_Handler from stm32f0xx_it.o(i.PendSV_Handler) referenced from startup_stm32f051x8.o(RESET)
- RCC_IRQHandler from startup_stm32f051x8.o(.text) referenced from startup_stm32f051x8.o(RESET)
- RTC_IRQHandler from startup_stm32f051x8.o(.text) referenced from startup_stm32f051x8.o(RESET)
- Reset_Handler from startup_stm32f051x8.o(.text) referenced from startup_stm32f051x8.o(RESET)
- SPI1_IRQHandler from startup_stm32f051x8.o(.text) referenced from startup_stm32f051x8.o(RESET)
- SPI2_IRQHandler from startup_stm32f051x8.o(.text) referenced from startup_stm32f051x8.o(RESET)
- SVC_Handler from stm32f0xx_it.o(i.SVC_Handler) referenced from startup_stm32f051x8.o(RESET)
- SysTick_Handler from stm32f0xx_it.o(i.SysTick_Handler) referenced from startup_stm32f051x8.o(RESET)
- SystemInit from system_stm32f0xx.o(i.SystemInit) referenced from startup_stm32f051x8.o(.text)
- TIM14_IRQHandler from startup_stm32f051x8.o(.text) referenced from startup_stm32f051x8.o(RESET)
- TIM15_IRQHandler from startup_stm32f051x8.o(.text) referenced from startup_stm32f051x8.o(RESET)
- TIM16_IRQHandler from startup_stm32f051x8.o(.text) referenced from startup_stm32f051x8.o(RESET)
- TIM17_IRQHandler from startup_stm32f051x8.o(.text) referenced from startup_stm32f051x8.o(RESET)
- TIM1_BRK_UP_TRG_COM_IRQHandler from startup_stm32f051x8.o(.text) referenced from startup_stm32f051x8.o(RESET)
- TIM1_CC_IRQHandler from startup_stm32f051x8.o(.text) referenced from startup_stm32f051x8.o(RESET)
- TIM2_IRQHandler from startup_stm32f051x8.o(.text) referenced from startup_stm32f051x8.o(RESET)
- TIM3_IRQHandler from startup_stm32f051x8.o(.text) referenced from startup_stm32f051x8.o(RESET)
- TIM6_DAC_IRQHandler from startup_stm32f051x8.o(.text) referenced from startup_stm32f051x8.o(RESET)
- TSC_IRQHandler from startup_stm32f051x8.o(.text) referenced from startup_stm32f051x8.o(RESET)
- USART1_IRQHandler from startup_stm32f051x8.o(.text) referenced from startup_stm32f051x8.o(RESET)
- USART2_IRQHandler from startup_stm32f051x8.o(.text) referenced from startup_stm32f051x8.o(RESET)
- WWDG_IRQHandler from startup_stm32f051x8.o(.text) referenced from startup_stm32f051x8.o(RESET)
- __main from entry.o(.ARM.Collect$$$$00000000) referenced from startup_stm32f051x8.o(.text)
- main from main.o(i.main) referenced from entry9a.o(.ARM.Collect$$$$0000000B)

### Global Symbols

__main (Thumb, 0 bytes, Stack size unknown bytes, entry.o(.ARM.Collect$$$$00000000))
[Address Reference Count : 1]

- startup_stm32f051x8.o(.text)

_main_stk (Thumb, 0 bytes, Stack size unknown bytes, entry2.o(.ARM.Collect$$$$00000001))

_main_scatterload (Thumb, 0 bytes, Stack size unknown bytes, entry5.o(.ARM.Collect$$$$00000004))

[Calls]

- >> __scatterload

__main_after_scatterload (Thumb, 0 bytes, Stack size unknown bytes, entry5.o(.ARM.Collect$$$$00000004))

[Called By]

- >> __scatterload

_main_clock (Thumb, 0 bytes, Stack size unknown bytes, entry7b.o(.ARM.Collect$$$$00000008))

_main_cpp_init (Thumb, 0 bytes, Stack size unknown bytes, entry8b.o(.ARM.Collect$$$$0000000A))

_main_init (Thumb, 0 bytes, Stack size unknown bytes, entry9a.o(.ARM.Collect$$$$0000000B))

__rt_lib_shutdown_fini (Thumb, 0 bytes, Stack size unknown bytes, entry12b.o(.ARM.Collect$$$$0000000E))

[Calls]

- >> __arm_fini_ (Weak Reference)

__rt_final_cpp (Thumb, 0 bytes, Stack size unknown bytes, entry10a.o(.ARM.Collect$$$$0000000F))

__rt_final_exit (Thumb, 0 bytes, Stack size unknown bytes, entry11a.o(.ARM.Collect$$$$00000011))

Reset_Handler (Thumb, 8 bytes, Stack size 0 bytes, startup_stm32f051x8.o(.text))
[Address Reference Count : 1]

- startup_stm32f051x8.o(RESET)

ADC1_COMP_IRQHandler (Thumb, 0 bytes, Stack size 0 bytes, startup_stm32f051x8.o(.text))

[Calls]

- >> ADC1_COMP_IRQHandler

[Called By]

- >> ADC1_COMP_IRQHandler

[Address Reference Count : 1]

- startup_stm32f051x8.o(RESET)

CEC_IRQHandler (Thumb, 0 bytes, Stack size 0 bytes, startup_stm32f051x8.o(.text))
[Address Reference Count : 1]

- startup_stm32f051x8.o(RESET)

DMA1_Channel1_IRQHandler (Thumb, 0 bytes, Stack size 0 bytes, startup_stm32f051x8.o(.text))
[Address Reference Count : 1]

- startup_stm32f051x8.o(RESET)

DMA1_Channel2_3_IRQHandler (Thumb, 0 bytes, Stack size 0 bytes, startup_stm32f051x8.o(.text))
[Address Reference Count : 1]

- startup_stm32f051x8.o(RESET)

DMA1_Channel4_5_IRQHandler (Thumb, 0 bytes, Stack size 0 bytes, startup_stm32f051x8.o(.text))
[Address Reference Count : 1]

- startup_stm32f051x8.o(RESET)

EXTI0_1_IRQHandler (Thumb, 0 bytes, Stack size 0 bytes, startup_stm32f051x8.o(.text))
[Address Reference Count : 1]

- startup_stm32f051x8.o(RESET)

EXTI2_3_IRQHandler (Thumb, 0 bytes, Stack size 0 bytes, startup_stm32f051x8.o(.text))
[Address Reference Count : 1]

- startup_stm32f051x8.o(RESET)

EXTI4_15_IRQHandler (Thumb, 0 bytes, Stack size 0 bytes, startup_stm32f051x8.o(.text))
[Address Reference Count : 1]

- startup_stm32f051x8.o(RESET)

FLASH_IRQHandler (Thumb, 0 bytes, Stack size 0 bytes, startup_stm32f051x8.o(.text))
[Address Reference Count : 1]

- startup_stm32f051x8.o(RESET)

I2C1_IRQHandler (Thumb, 0 bytes, Stack size 0 bytes, startup_stm32f051x8.o(.text))
[Address Reference Count : 1]

- startup_stm32f051x8.o(RESET)

I2C2_IRQHandler (Thumb, 0 bytes, Stack size 0 bytes, startup_stm32f051x8.o(.text))
[Address Reference Count : 1]

- startup_stm32f051x8.o(RESET)

PVD_IRQHandler (Thumb, 0 bytes, Stack size 0 bytes, startup_stm32f051x8.o(.text))
[Address Reference Count : 1]

- startup_stm32f051x8.o(RESET)

RCC_IRQHandler (Thumb, 0 bytes, Stack size 0 bytes, startup_stm32f051x8.o(.text))
[Address Reference Count : 1]

- startup_stm32f051x8.o(RESET)

RTC_IRQHandler (Thumb, 0 bytes, Stack size 0 bytes, startup_stm32f051x8.o(.text))
[Address Reference Count : 1]

- startup_stm32f051x8.o(RESET)

SPI1_IRQHandler (Thumb, 0 bytes, Stack size 0 bytes, startup_stm32f051x8.o(.text))
[Address Reference Count : 1]

- startup_stm32f051x8.o(RESET)

SPI2_IRQHandler (Thumb, 0 bytes, Stack size 0 bytes, startup_stm32f051x8.o(.text))
[Address Reference Count : 1]

- startup_stm32f051x8.o(RESET)

TIM14_IRQHandler (Thumb, 0 bytes, Stack size 0 bytes, startup_stm32f051x8.o(.text))
[Address Reference Count : 1]

- startup_stm32f051x8.o(RESET)

TIM15_IRQHandler (Thumb, 0 bytes, Stack size 0 bytes, startup_stm32f051x8.o(.text))
[Address Reference Count : 1]

- startup_stm32f051x8.o(RESET)

TIM16_IRQHandler (Thumb, 0 bytes, Stack size 0 bytes, startup_stm32f051x8.o(.text))
[Address Reference Count : 1]

- startup_stm32f051x8.o(RESET)

TIM17_IRQHandler (Thumb, 0 bytes, Stack size 0 bytes, startup_stm32f051x8.o(.text))
[Address Reference Count : 1]

- startup_stm32f051x8.o(RESET)

TIM1_BRK_UP_TRG_COM_IRQHandler (Thumb, 0 bytes, Stack size 0 bytes, startup_stm32f051x8.o(.text))
[Address Reference Count : 1]

- startup_stm32f051x8.o(RESET)

TIM1_CC_IRQHandler (Thumb, 0 bytes, Stack size 0 bytes, startup_stm32f051x8.o(.text))
[Address Reference Count : 1]

- startup_stm32f051x8.o(RESET)

TIM2_IRQHandler (Thumb, 0 bytes, Stack size 0 bytes, startup_stm32f051x8.o(.text))
[Address Reference Count : 1]

- startup_stm32f051x8.o(RESET)

TIM3_IRQHandler (Thumb, 0 bytes, Stack size 0 bytes, startup_stm32f051x8.o(.text))
[Address Reference Count : 1]

- startup_stm32f051x8.o(RESET)

TIM6_DAC_IRQHandler (Thumb, 0 bytes, Stack size 0 bytes, startup_stm32f051x8.o(.text))
[Address Reference Count : 1]

- startup_stm32f051x8.o(RESET)

TSC_IRQHandler (Thumb, 0 bytes, Stack size 0 bytes, startup_stm32f051x8.o(.text))
[Address Reference Count : 1]

- startup_stm32f051x8.o(RESET)

USART1_IRQHandler (Thumb, 0 bytes, Stack size 0 bytes, startup_stm32f051x8.o(.text))
[Address Reference Count : 1]

- startup_stm32f051x8.o(RESET)

USART2_IRQHandler (Thumb, 0 bytes, Stack size 0 bytes, startup_stm32f051x8.o(.text))
[Address Reference Count : 1]

- startup_stm32f051x8.o(RESET)

WWDG_IRQHandler (Thumb, 0 bytes, Stack size 0 bytes, startup_stm32f051x8.o(.text))
[Address Reference Count : 1]

- startup_stm32f051x8.o(RESET)

__aeabi_uidiv (Thumb, 0 bytes, Stack size 12 bytes, uidiv.o(.text), UNUSED)

__aeabi_uidivmod (Thumb, 44 bytes, Stack size 12 bytes, uidiv.o(.text))

[Stack]

- Max Depth = 12
- Call Chain = __aeabi_uidivmod

[Called By]

- >> HAL_InitTick

__aeabi_uldivmod (Thumb, 96 bytes, Stack size 48 bytes, uldiv.o(.text))

[Stack]

- Max Depth = 56
- Call Chain = __aeabi_uldivmod ⇒ __aeabi_llsl

[Calls]

- >> __aeabi_llsl
- >> __aeabi_llsr

[Called By]

- >> HAL_RCC_GetSysClockFreq

__aeabi_llsr (Thumb, 34 bytes, Stack size 8 bytes, llushr.o(.text))

[Stack]

- Max Depth = 8
- Call Chain = __aeabi_llsr

[Called By]

- >> __aeabi_uldivmod

_ll_ushift_r (Thumb, 0 bytes, Stack size 8 bytes, llushr.o(.text), UNUSED)

__aeabi_memset (Thumb, 14 bytes, Stack size 0 bytes, memseta.o(.text), UNUSED)

[Called By]

- >> _memset$wrapper
- >> __aeabi_memclr

__aeabi_memset4 (Thumb, 0 bytes, Stack size 0 bytes, memseta.o(.text), UNUSED)

__aeabi_memset8 (Thumb, 0 bytes, Stack size 0 bytes, memseta.o(.text), UNUSED)

__aeabi_memclr (Thumb, 4 bytes, Stack size 0 bytes, memseta.o(.text), UNUSED)

[Calls]

- >> __aeabi_memset

__aeabi_memclr4 (Thumb, 0 bytes, Stack size 0 bytes, memseta.o(.text))

[Called By]

- >> SystemClock_Config

__aeabi_memclr8 (Thumb, 0 bytes, Stack size 0 bytes, memseta.o(.text), UNUSED)

_memset$wrapper (Thumb, 18 bytes, Stack size 8 bytes, memseta.o(.text), UNUSED)

[Calls]

- >> __aeabi_memset

__aeabi_llsl (Thumb, 32 bytes, Stack size 8 bytes, llshl.o(.text))

[Stack]

- Max Depth = 8
- Call Chain = __aeabi_llsl

[Called By]

- >> __aeabi_uldivmod

_ll_shift_l (Thumb, 0 bytes, Stack size 8 bytes, llshl.o(.text), UNUSED)

__scatterload (Thumb, 28 bytes, Stack size 0 bytes, init.o(.text))

[Calls]

- >> __main_after_scatterload

[Called By]

- >> _main_scatterload

__scatterload_rt2 (Thumb, 0 bytes, Stack size 0 bytes, init.o(.text), UNUSED)

Error_Handler (Thumb, 6 bytes, Stack size 0 bytes, main.o(i.Error_Handler))

[Called By]

- >> SystemClock_Config

HAL_GetTick (Thumb, 6 bytes, Stack size 0 bytes, stm32f0xx_hal.o(i.HAL_GetTick))

[Called By]

- >> HAL_RCC_OscConfig
- >> HAL_RCC_ClockConfig

HAL_IncTick (Thumb, 16 bytes, Stack size 0 bytes, stm32f0xx_hal.o(i.HAL_IncTick))

[Called By]

- >> SysTick_Handler

HAL_Init (Thumb, 28 bytes, Stack size 8 bytes, stm32f0xx_hal.o(i.HAL_Init))

[Stack]

- Max Depth = 48
- Call Chain = HAL_Init ⇒ HAL_InitTick ⇒ HAL_SYSTICK_Config ⇒ __NVIC_SetPriority

[Calls]

- >> HAL_InitTick
- >> HAL_MspInit

[Called By]

- >> main

HAL_InitTick (Thumb, 70 bytes, Stack size 16 bytes, stm32f0xx_hal.o(i.HAL_InitTick))

[Stack]

- Max Depth = 40
- Call Chain = HAL_InitTick ⇒ HAL_SYSTICK_Config ⇒ __NVIC_SetPriority

[Calls]

- >> HAL_SYSTICK_Config
- >> HAL_NVIC_SetPriority
- >> __aeabi_uidivmod

[Called By]

- >> HAL_RCC_ClockConfig
- >> HAL_Init

HAL_MspInit (Thumb, 60 bytes, Stack size 8 bytes, stm32f0xx_hal_msp.o(i.HAL_MspInit))

[Stack]

- Max Depth = 8
- Call Chain = HAL_MspInit

[Called By]

- >> HAL_Init

HAL_NVIC_SetPriority (Thumb, 18 bytes, Stack size 16 bytes, stm32f0xx_hal_cortex.o(i.HAL_NVIC_SetPriority))

[Stack]

- Max Depth = 24
- Call Chain = HAL_NVIC_SetPriority ⇒ __NVIC_SetPriority

[Calls]

- >> __NVIC_SetPriority

[Called By]

- >> HAL_InitTick

HAL_RCC_ClockConfig (Thumb, 342 bytes, Stack size 16 bytes, stm32f0xx_hal_rcc.o(i.HAL_RCC_ClockConfig))

[Stack]

- Max Depth = 128
- Call Chain = HAL_RCC_ClockConfig ⇒ HAL_RCC_GetSysClockFreq ⇒ __aeabi_uldivmod ⇒ __aeabi_llsl

[Calls]

- >> HAL_InitTick
- >> HAL_GetTick
- >> HAL_RCC_GetSysClockFreq

[Called By]

- >> SystemClock_Config

HAL_RCC_GetSysClockFreq (Thumb, 162 bytes, Stack size 56 bytes, stm32f0xx_hal_rcc.o(i.HAL_RCC_GetSysClockFreq))

[Stack]

- Max Depth = 112
- Call Chain = HAL_RCC_GetSysClockFreq ⇒ __aeabi_uldivmod ⇒ __aeabi_llsl

[Calls]

- >> __ARM_common_ll_muluu
- >> __aeabi_uldivmod

[Called By]

- >> HAL_RCC_ClockConfig

HAL_RCC_OscConfig (Thumb, 1416 bytes, Stack size 32 bytes, stm32f0xx_hal_rcc.o(i.HAL_RCC_OscConfig))

[Stack]

- Max Depth = 32
- Call Chain = HAL_RCC_OscConfig

[Calls]

- >> HAL_GetTick

[Called By]

- >> SystemClock_Config

HAL_SYSTICK_Config (Thumb, 46 bytes, Stack size 16 bytes, stm32f0xx_hal_cortex.o(i.HAL_SYSTICK_Config))

[Stack]

- Max Depth = 24
- Call Chain = HAL_SYSTICK_Config ⇒ __NVIC_SetPriority

[Calls]

- >> __NVIC_SetPriority

[Called By]

- >> HAL_InitTick

HardFault_Handler (Thumb, 4 bytes, Stack size 0 bytes, stm32f0xx_it.o(i.HardFault_Handler))
[Address Reference Count : 1]

- startup_stm32f051x8.o(RESET)

MX_GPIO_Init (Thumb, 36 bytes, Stack size 8 bytes, gpio.o(i.MX_GPIO_Init))

[Stack]

- Max Depth = 8
- Call Chain = MX_GPIO_Init

[Called By]

- >> main

NMI_Handler (Thumb, 4 bytes, Stack size 0 bytes, stm32f0xx_it.o(i.NMI_Handler))
[Address Reference Count : 1]

- startup_stm32f051x8.o(RESET)

PendSV_Handler (Thumb, 2 bytes, Stack size 0 bytes, stm32f0xx_it.o(i.PendSV_Handler))
[Address Reference Count : 1]

- startup_stm32f051x8.o(RESET)

SVC_Handler (Thumb, 2 bytes, Stack size 0 bytes, stm32f0xx_it.o(i.SVC_Handler))
[Address Reference Count : 1]

- startup_stm32f051x8.o(RESET)

SysTick_Handler (Thumb, 8 bytes, Stack size 8 bytes, stm32f0xx_it.o(i.SysTick_Handler))

[Stack]

- Max Depth = 8
- Call Chain = SysTick_Handler

[Calls]

- >> HAL_IncTick

[Address Reference Count : 1]

- startup_stm32f051x8.o(RESET)

SystemClock_Config (Thumb, 92 bytes, Stack size 72 bytes, main.o(i.SystemClock_Config))

[Stack]

- Max Depth = 200
- Call Chain = SystemClock_Config ⇒ HAL_RCC_ClockConfig ⇒ HAL_RCC_GetSysClockFreq ⇒ __aeabi_uldivmod ⇒ __aeabi_llsl

[Calls]

- >> HAL_RCC_OscConfig
- >> HAL_RCC_ClockConfig
- >> Error_Handler
- >> __aeabi_memclr4

[Called By]

- >> main

SystemInit (Thumb, 2 bytes, Stack size 0 bytes, system_stm32f0xx.o(i.SystemInit))
[Address Reference Count : 1]

- startup_stm32f051x8.o(.text)

__ARM_common_ll_muluu (Thumb, 48 bytes, Stack size 24 bytes, stm32f0xx_hal_rcc.o(i.__ARM_common_ll_muluu))

[Stack]

- Max Depth = 24
- Call Chain = __ARM_common_ll_muluu

[Called By]

- >> HAL_RCC_GetSysClockFreq

__scatterload_copy (Thumb, 14 bytes, Stack size unknown bytes, handlers.o(i.__scatterload_copy), UNUSED)

__scatterload_null (Thumb, 2 bytes, Stack size unknown bytes, handlers.o(i.__scatterload_null), UNUSED)

__scatterload_zeroinit (Thumb, 14 bytes, Stack size unknown bytes, handlers.o(i.__scatterload_zeroinit), UNUSED)

main (Thumb, 16 bytes, Stack size 0 bytes, main.o(i.main))

[Stack]

- Max Depth = 200
- Call Chain = main ⇒ SystemClock_Config ⇒ HAL_RCC_ClockConfig ⇒ HAL_RCC_GetSysClockFreq ⇒ __aeabi_uldivmod ⇒ __aeabi_llsl

[Calls]

- >> MX_GPIO_Init
- >> HAL_Init
- >> SystemClock_Config

[Address Reference Count : 1]

- entry9a.o(.ARM.Collect$$$$0000000B)

### Local Symbols

__NVIC_SetPriority (Thumb, 110 bytes, Stack size 8 bytes, stm32f0xx_hal_cortex.o(i.__NVIC_SetPriority))

[Stack]

- Max Depth = 8
- Call Chain = __NVIC_SetPriority

[Called By]

- >> HAL_SYSTICK_Config
- >> HAL_NVIC_SetPriority

### Undefined Global Symbols

__arm_fini_ (Unknown, 0 bytes, Stack size 0 bytes, UNDEFINED)

[Called By]

- >> __rt_lib_shutdown_fini

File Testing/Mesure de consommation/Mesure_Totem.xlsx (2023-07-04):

Tous les résultats sont en mA
Luminosité | Texte* | Nyan | Full rouge | Full Vert | Full bleu | Full blanc | LED Off | Alim Off
5 | 375 | 416 | 464 | 464 | 464 | 693 | 344 | 27
10 | 396 | 501 | 594 | 594 | 594 | 1081
20 | 419 | 666 | 859 | 859 | 859 | 1877
50 | 531 | 1159 | 1655 | 1655 | 1655 | 3994
100 | 724 | 2008 | 2844 | 2844 | 2844 | 7644
*Le texte écrit est "STEAK" en couleur arc en ciel.
5 | 31 | 72 | 120 | 120 | 120 | 349 | 69.8 | 24
10 | 52 | 157 | 250 | 250 | 250 | 737 | 73.7 | 25
20 | 75 | 322 | 515 | 515 | 515 | 1533 | 76.65 | 25.75
50 | 187 | 815 | 1311 | 1311 | 1311 | 3650 |  | 26.22
100 | 380 | 1664 | 2500 | 2500 | 2500 | 7300

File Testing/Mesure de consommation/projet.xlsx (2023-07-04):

Valeur en mA
 |  |  |  |  |  |  |  |  |  |  |  |  |  |  |  |  |  |  |  |  |  |  |  |  |  |  |  |  |  |  |  |  |  |  |  | éstimation des cout
Luminositer = 5/255
 |  | nombre de Led |  |  |  |  |  |  |  |  |  |  |  |  |  |  |  |  |  |  |  |  |  |  |  |  |  |  |  |  |  |  |  |  |  | Composant | Prix
 |  | 1 | 20 | 128 | 255 | Pmax[W] | Pmin[W] |  |  |  |  |  |  |  |  |  |  |  |  |  |  |  |  |  |  |  |  |  |  |  |  |  |  |  |  | PIC | 10 .-
Couleur | Rouge | 173 | 177 | 203 | 233 | 2.33 | 0.885 |  |  |  |  |  |  |  |  |  |  |  |  |  |  |  |  |  |  |  |  |  |  |  |  |  |  |  |  | Module WIFI | 5 à 18.-
 | Bleu | 173 | 177 | 203 | 233 | 2.33 | 0.885 |  |  |  |  |  |  |  |  |  |  |  |  |  |  |  |  |  |  |  |  |  |  |  |  |  |  |  |  | Régulateurs | 5 à ~20.-
 | Vert | 173 | 177 | 203 | 233 | 2.33 | 0.885 |  |  |  |  |  |  |  |  |  |  |  |  |  |  |  |  |  |  |  |  |  |  |  |  |  |  |  |  | panneau solaire, batterie et régulateur | 230.-
 | Blanc | 173 | 187 | 263 | 353 | 3.53 | 0.935 |  |  |  |  |  |  |  |  |  |  |  |  |  |  |  |  |  |  |  |  |  |  |  |  |  |  |  |  | Matrices X2 | 200.-
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

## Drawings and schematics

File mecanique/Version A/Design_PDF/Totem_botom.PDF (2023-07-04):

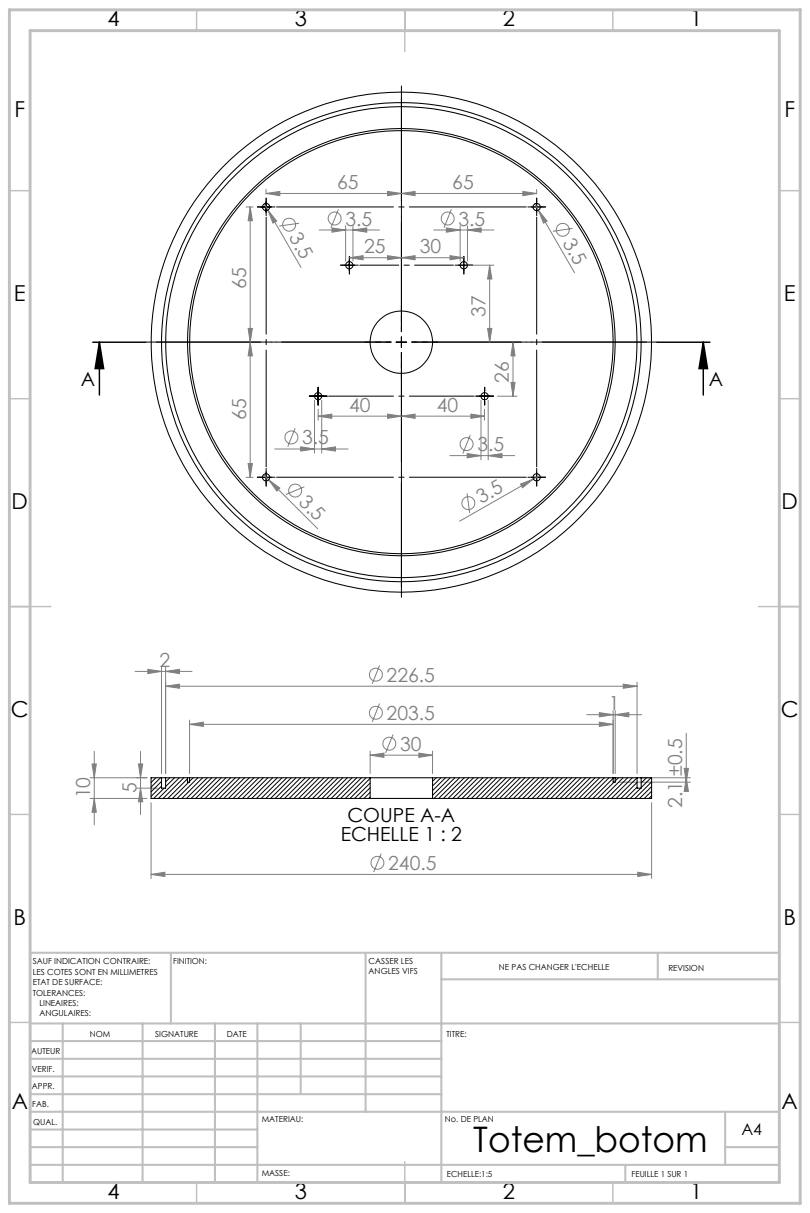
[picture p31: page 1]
COUPE A-A ECHELLE 1 : 2; FINITION:; CASSER LES; ANGLES VIFS; NE PAS CHANGER L'ECHELLE; REVISION; ECHELLE:1:5; FEUILLE 1 SUR 1

SAUF INDICATION CONTRAIRE:
LES COTES SONT EN MILLIMETRES
ETAT DE SURFACE:
TOLERANCES:
LINEAIRES:
ANGULAIRES:

NOM | SIGNATURE | DATE | | | | TITRE:

AUTEUR
VERIF.
APPR.
FAB.
QUAL. | | | | MATERIAU: | No. DE PLAN Totem_botom | A4

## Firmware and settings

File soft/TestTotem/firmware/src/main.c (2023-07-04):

/*******************************************************************************
  MPLAB Harmony Project Main Source File

  Company:
    Microchip Technology Inc.
  
  File Name:
    main.c

  Summary:
    This file contains the "main" function for an MPLAB Harmony project.

  Description:
    This file contains the "main" function for an MPLAB Harmony project.  The
    "main" function calls the "SYS_Initialize" function to initialize the state 
    machines of all MPLAB Harmony modules in the system and it calls the 
    "SYS_Tasks" function from within a system-wide "super" loop to maintain 
    their correct operation. These two functions are implemented in 
    configuration-specific files (usually "system_init.c" and "system_tasks.c")
    in a configuration-specific folder under the "src/system_config" folder 
    within this project's top-level folder.  An MPLAB Harmony project may have
    more than one configuration, each contained within it's own folder under
    the "system_config" folder.
 *******************************************************************************/

// DOM-IGNORE-BEGIN
/*******************************************************************************
Copyright (c) 2013-2014 released Microchip Technology Inc.  All rights reserved.

//Microchip licenses to you the right to use, modify, copy and distribute
Software only when embedded on a Microchip microcontroller or digital signal
controller that is integrated into your product or third party product
(pursuant to the sublicense terms in the accompanying license agreement).

You should refer to the license agreement accompanying this Software for
additional information regarding your rights and obligations.

SOFTWARE AND DOCUMENTATION ARE PROVIDED "AS IS" WITHOUT WARRANTY OF ANY KIND,
EITHER EXPRESS OR IMPLIED, INCLUDING WITHOUT LIMITATION, ANY WARRANTY OF
MERCHANTABILITY, TITLE, NON-INFRINGEMENT AND FITNESS FOR A PARTICULAR PURPOSE.
IN NO EVENT SHALL MICROCHIP OR ITS LICENSORS BE LIABLE OR OBLIGATED UNDER
CONTRACT, NEGLIGENCE, STRICT LIABILITY, CONTRIBUTION, BREACH OF WARRANTY, OR
OTHER LEGAL EQUITABLE THEORY ANY DIRECT OR INDIRECT DAMAGES OR EXPENSES
INCLUDING BUT NOT LIMITED TO ANY INCIDENTAL, SPECIAL, INDIRECT, PUNITIVE OR
CONSEQUENTIAL DAMAGES, LOST PROFITS OR LOST DATA, COST OF PROCUREMENT OF
SUBSTITUTE GOODS, TECHNOLOGY, SERVICES, OR ANY CLAIMS BY THIRD PARTIES
(INCLUDING BUT NOT LIMITED TO ANY DEFENSE THEREOF), OR OTHER SIMILAR COSTS.
 *******************************************************************************/
// DOM-IGNORE-END


// *****************************************************************************
// *****************************************************************************
// Section: Included Files
// *****************************************************************************
// *****************************************************************************

#include <stddef.h>                     // Defines NULL
#include <stdbool.h>                    // Defines true
#include <stdlib.h>                     // Defines EXIT_FAILURE
#include "system/common/sys_module.h"   // SYS function prototypes

// *****************************************************************************
// *****************************************************************************
// Section: Main Entry Point
// *****************************************************************************
// *****************************************************************************
int main ( void )
{
    /* Initialize all MPLAB Harmony modules, including application(s). */
    SYS_Initialize ( NULL );


    while ( true )
    {
        /* Maintain state machines of all polled MPLAB Harmony modules. */
        SYS_Tasks ( );

    }

    /* Execution should not come here during normal operation */

    return ( EXIT_FAILURE );
}


/*******************************************************************************
 End of File
*/

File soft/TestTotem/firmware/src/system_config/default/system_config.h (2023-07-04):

/*******************************************************************************
  MPLAB Harmony System Configuration Header

  File Name:
    system_config.h

  Summary:
    Build-time configuration header for the system defined by this MPLAB Harmony
    project.

  Description:
    An MPLAB Project may have multiple configurations.  This file defines the
    build-time options for a single configuration.

  Remarks:
    This configuration header must not define any prototypes or data
    definitions (or include any files that do).  It only provides macro
    definitions for build-time configuration options that are not instantiated
    until used by another MPLAB Harmony module or application.

    Created with MPLAB Harmony Version 2.05
*******************************************************************************/

// DOM-IGNORE-BEGIN
/*******************************************************************************
Copyright (c) 2013-2015 released Microchip Technology Inc.  All rights reserved.

Microchip licenses to you the right to use, modify, copy and distribute
Software only when embedded on a Microchip microcontroller or digital signal
controller that is integrated into your product or third party product
(pursuant to the sublicense terms in the accompanying license agreement).

You should refer to the license agreement accompanying this Software for
additional information regarding your rights and obligations.

SOFTWARE AND DOCUMENTATION ARE PROVIDED AS IS WITHOUT WARRANTY OF ANY KIND,
EITHER EXPRESS OR IMPLIED, INCLUDING WITHOUT LIMITATION, ANY WARRANTY OF
MERCHANTABILITY, TITLE, NON-INFRINGEMENT AND FITNESS FOR A PARTICULAR PURPOSE.
IN NO EVENT SHALL MICROCHIP OR ITS LICENSORS BE LIABLE OR OBLIGATED UNDER
CONTRACT, NEGLIGENCE, STRICT LIABILITY, CONTRIBUTION, BREACH OF WARRANTY, OR
OTHER LEGAL EQUITABLE THEORY ANY DIRECT OR INDIRECT DAMAGES OR EXPENSES
INCLUDING BUT NOT LIMITED TO ANY INCIDENTAL, SPECIAL, INDIRECT, PUNITIVE OR
CONSEQUENTIAL DAMAGES, LOST PROFITS OR LOST DATA, COST OF PROCUREMENT OF
SUBSTITUTE GOODS, TECHNOLOGY, SERVICES, OR ANY CLAIMS BY THIRD PARTIES
(INCLUDING BUT NOT LIMITED TO ANY DEFENSE THEREOF), OR OTHER SIMILAR COSTS.
*******************************************************************************/
// DOM-IGNORE-END

#ifndef _SYSTEM_CONFIG_H
#define _SYSTEM_CONFIG_H

// *****************************************************************************
// *****************************************************************************
// Section: Included Files
// *****************************************************************************
// *****************************************************************************
/*  This section Includes other configuration headers necessary to completely
    define this configuration.
*/


// DOM-IGNORE-BEGIN
#ifdef __cplusplus  // Provide C++ Compatibility

extern "C" {

#endif
// DOM-IGNORE-END

// *****************************************************************************
// *****************************************************************************
// Section: System Service Configuration
// *****************************************************************************
// *****************************************************************************
// *****************************************************************************
/* Common System Service Configuration Options
*/
#define SYS_VERSION_STR           "2.05"
#define SYS_VERSION               20500

// *****************************************************************************
/* Clock System Service Configuration Options
*/
#define SYS_CLK_FREQ                        48000000ul
#define SYS_CLK_BUS_PERIPHERAL_1            48000000ul
#define SYS_CLK_UPLL_BEFORE_DIV2_FREQ       192000000ul
#define SYS_CLK_CONFIG_PRIMARY_XTAL         8000000ul
#define SYS_CLK_CONFIG_SECONDARY_XTAL       32768ul
   
/*** Ports System Service Configuration ***/
#define SYS_PORT_A_ANSEL        0xF87F
#define SYS_PORT_A_TRIS         0xFFFB
#define SYS_PORT_A_LAT          0x0000
#define SYS_PORT_A_ODC          0x0002
#define SYS_PORT_A_CNPU         0x0000
#define SYS_PORT_A_CNPD         0x0000
#define SYS_PORT_A_CNEN         0x0000

#define SYS_PORT_B_ANSEL        0xF01B
#define SYS_PORT_B_TRIS         0xFBBF
#define SYS_PORT_B_LAT          0x0400
#define SYS_PORT_B_ODC          0x0000
#define SYS_PORT_B_CNPU         0x2000
#define SYS_PORT_B_CNPD         0x0000
#define SYS_PORT_B_CNEN         0x0000

#define SYS_PORT_C_ANSEL        0xFC0F
#define SYS_PORT_C_TRIS         0xFFFF
#define SYS_PORT_C_LAT          0x0000
#define SYS_PORT_C_ODC          0x0000
#define SYS_PORT_C_CNPU         0x0000
#define SYS_PORT_C_CNPD         0x0000
#define SYS_PORT_C_CNEN         0x0000


/*** Interrupt System Service Configuration ***/
#define SYS_INT                     true
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

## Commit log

2023-07-04 version ETML-ES - projet 1814 N. Furst
    [1814_TotemLumineux.PrjPcb, 1814_TotemLumineux.xlsx, Alim.SchDoc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]
2023-08-09 MAJ dossier Doc
    [1814_TotemLumineux.PrjPcb, Alim.SchDoc, Liste des Composant_V1.xlsx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]
2023-09-19 Realisation feuille de modification mecanique
    [1814_TotemLumineux.PrjPcb, 1814_TotemLumineux.xlsx, Alim.SchDoc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]
2023-10-20 MAJ README V0_8 + electronic block diagram
    [NoProjet_NomProjet-BOM-v1.XLS]
2023-10-20 MAJ README V0_10
    [ListeComposants_V1.xlsx]
2024-05-13 MAJ word + prj demoLed STM32
